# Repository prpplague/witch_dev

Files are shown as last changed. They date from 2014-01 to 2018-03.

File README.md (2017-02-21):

WITCH Development
=========

Repository for misc documents and code relating to the study of the Harwell
WITCH. The Harwell computer, later known as the Wolverhampton Instrument for
Teaching Computing from Harwell (WITCH), or the Harwell Dekatron Computer,
was an early British relay-based computer. It is currently being restored at
The National Museum of Computing at Bletchley Park, where it is described as
"the oldest original functioning electronic stored program computer in the 
world".

http://www.witch-e.org

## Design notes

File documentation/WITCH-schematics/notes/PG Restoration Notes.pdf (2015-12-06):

Pulse Generator Restoration Notes

January – March 2012, updated August 2012

Delwyn Holroyd

Test setup

The pulse generator was powered up on the bench using the WITCH rectifier and stabilizer for all tests. Three switches were provided :-

- Stop switch on A4 (+20 / -10V)
- RCB on / off on A2 (Returned Carry B pulses from A10 / ground)
- Start switch on A3 (-200V / open)

Oscillator

On initial power-up the oscillator worked and pulse widths were observed to be approximately correct. Nominal widths for A and B pulses are 1.5ms.

Over the course of the next few weeks as work progressed, B pulse width became highly unstable and narrower. This fault was traced to C19 (two caps – the larger flat mica to blame). These were replaced with new modern 2200 + 150pF caps on 17th March.

An unusual feature was observed on the +B outputs from V8 – on the anode positive going and on screen negative going narrow pulses coincident with V9 (+A pulse) rising edge. It is unclear exactly how this arises, but is clearly associated with the current which must flow through C19 into the grid of V8, although there is no evidence of a voltage spike on V8 grid. The -ve pulse on the screen output is effectively removed by the following stage (V13) so has no effect on circuit operation.

The anode of V8 goes to A13 and onto Units GA and GB, but is not shown on the schematics of the latter. Investigation of how this signal is used GA and GB will be needed to determine whether the +ve pulse is a problem. Exchanging V8 didn't alter the waveform.

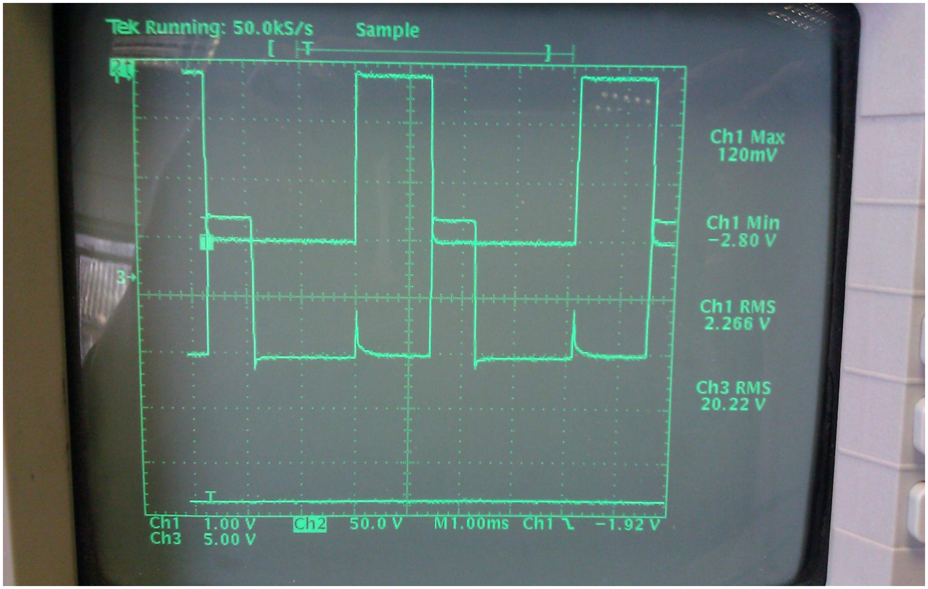
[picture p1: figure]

The picture above shows +A and +B pulses before C19 replacement.

The function of the 10n capacitor on V10 anode (-A pulses) was not immediately obvious. It's effect is to heavily round-off the rising pulse edge into V11 and V12. After clamping in the latter stages the rising edge is delayed and noticeably slower (100us). The functional effect is to delay the -A rising edge so that -A and -B pulses overlap slightly, important to ensure the Dekatrons step correctly.

On 17th March V10 failed, causing pulse widths and period to contract. The 6AM5 was replaced with an equivalent NOS EL91.

The photo below shows +A, -B, -A pulses after replacement of C19 and V10.

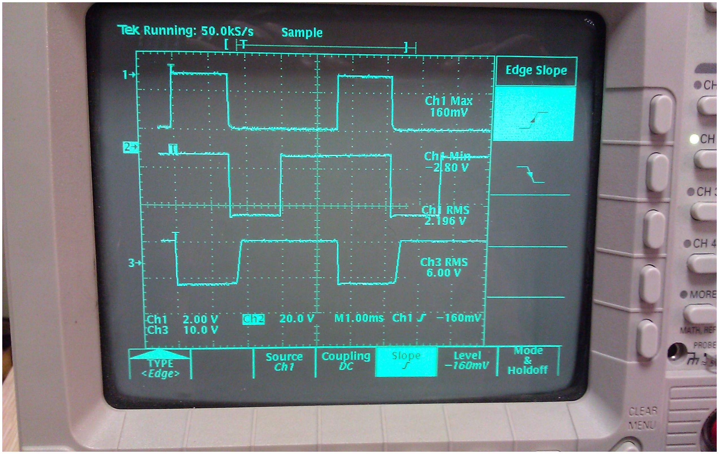
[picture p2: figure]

Control Circuit

On initial power-up, the two G1/371K trigger tubes V5, V6 did not work (no priming gap glow). The GTE175M tester was modified to accept G1/371K in an additional socket and the entire stock tested. We had only 7 working and the machine requires six in total (four in the pulse generator and two in Unit GA). The working parts have quite widely varying characteristics – both maintaining voltages and trigger threshold. Two tubes with reasonably well matched Vm were chosen for V5 and V6.

The adjustment of the circuit with RV1-3 is tricky since RV1 also affects the B pulse switching circuit, and V20 in Unit GA as well as the amplitude of the waveform appearing at V5 trigger (coincident with the trailing rising edge of the first RCB pulse). The contemporary “Computer Routine Maintenance” document from Wolverhampton notes that RV2 can be adjusted for two or three returned carry pulses, but it was found to be possible to adjust for one pulse. It isn't clear why more than one would be necessary.

A fault was discovered in this circuit which became more apparent over the period of fault-finding. This was traced to rectifier W2 (actually two germanium in series, probably a Wolverhampton replacement). This was replaced on 17th March with a modern 1N4007 silicon diode. This restored the correct timing of the trigger signal to V5 and eliminated spurious narrow pulses from the B pulse switching outputs.

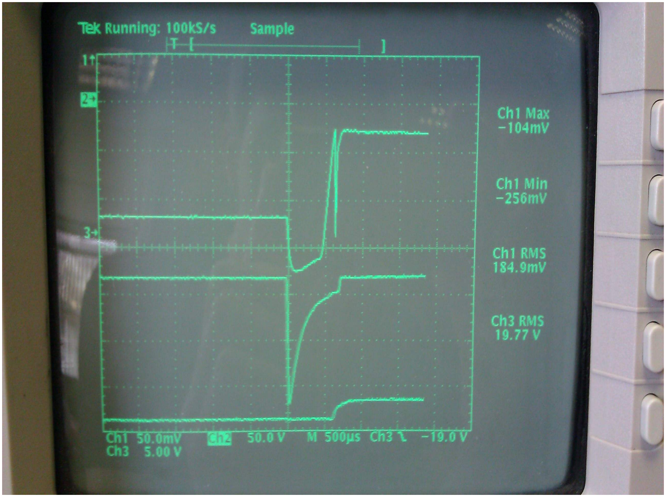
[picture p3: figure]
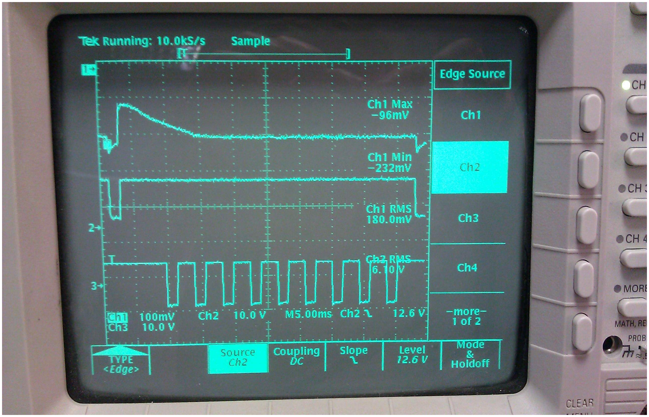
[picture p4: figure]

The left picture above shows the V5 trigger, V4 grid and V5 cathode before the repair, the right hand picture shows V5 trigger, RCB and 9B after replacement of W2.

Round-off Circuit

This was tested briefly, but due to the extreme shortage of working trigger tubes and the non essential nature of this circuit it has been left with V22-23 unpopulated.

A Pulse Switching Circuit

No problems were found in this circuit (V11-12) and all the clamping diodes are working.

B Pulse Switching Circuit

As noted above RV1 must be adjusted correctly to ensure waveform z (from trailing edge of RCB pulses) is not too large relative to waveform y (from trailing edge of first normal B pulse). The picture below shows correct adjustment – RCB, z, y.

B Pulse Output Stages

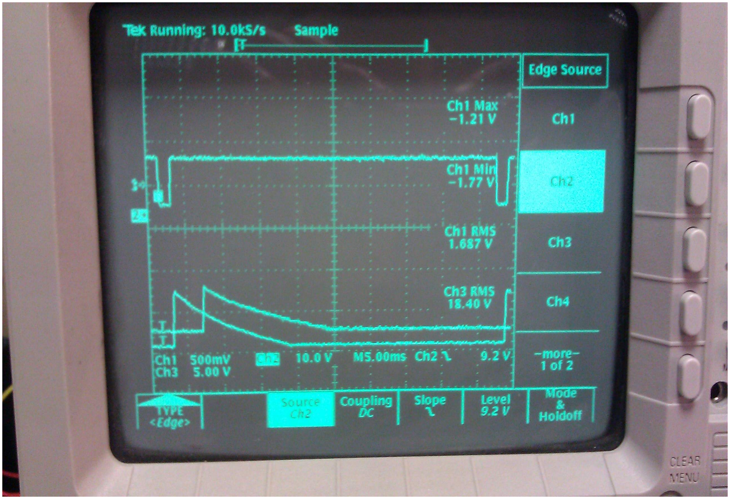
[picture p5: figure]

No problems were found in this circuit (V17-19, V25). However during early integration testing of the machine it was noted that send B pulses from V19 (SK21) only fall to around -50V, with RV6 at the limit of adjustment. To correct this problem the bias on RV6 was rewired from -200V to -180V, which now gives plenty of adjustment margin.

Trigger Valve Anode Waveform Circuit

These circuits produced the correct waveforms but with narrow spikes coincident with the rising edge of B pulses. These were traced to V20, the output of which drives SK3 and is mixed into SK2. Initially rectifier W29 was suspected, but temporary substitution with a silicon diode didn't alter the symptom. The picture below shows SK2, and V20 grids.

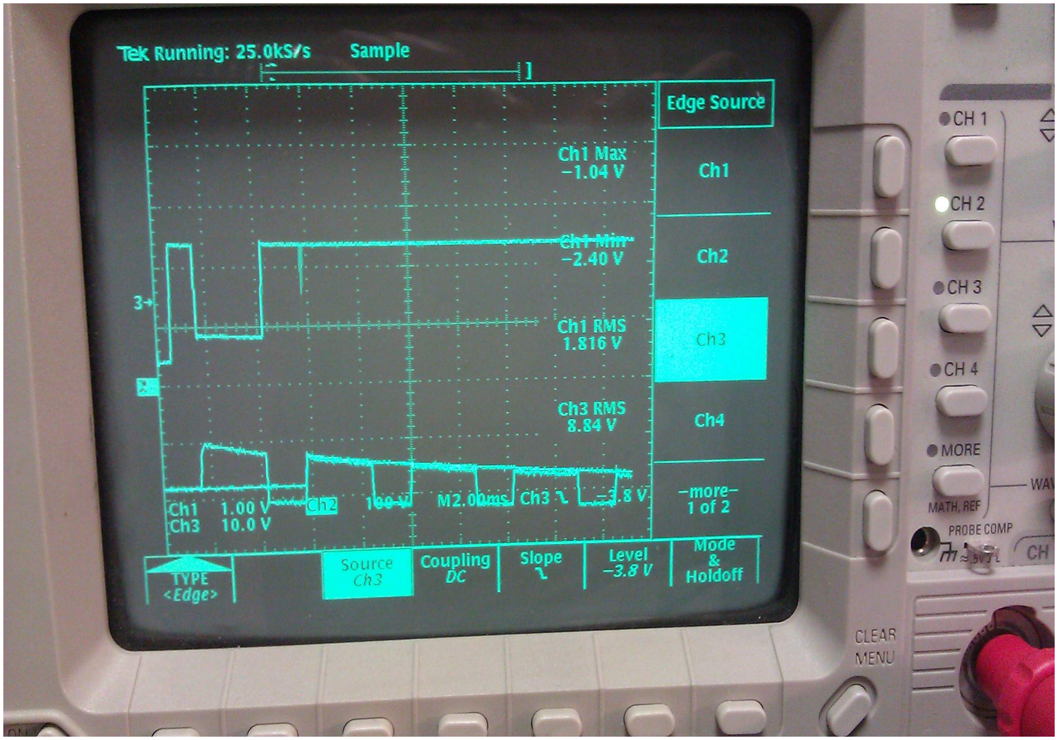
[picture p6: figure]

The problem is hard to see in this picture but there is ringing on the rising edges of the B pulses mixed into waveform z which is compared with waveform y by V20. This problem was solved by adding a 330pF capacitor from the junction of W29/R60 to -180V, to slow down the rising edges. The picture below shows the waveforms on SK3 and V20 grids after the capacitor was added.

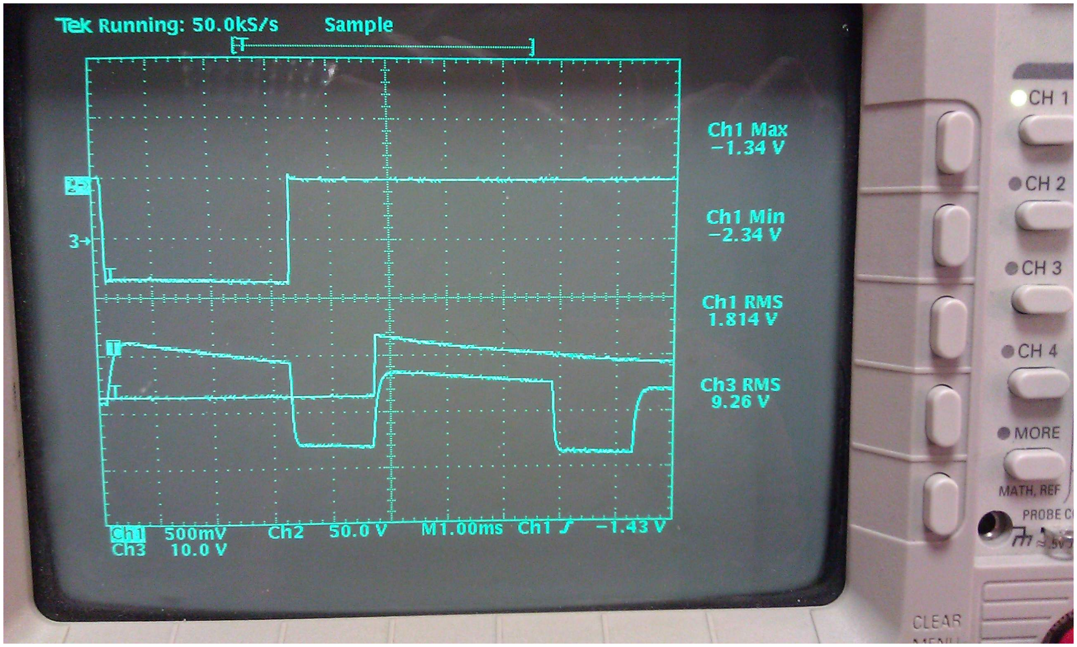
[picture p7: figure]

Circuit Modifications

Capacitor on W29 | Replacement C19

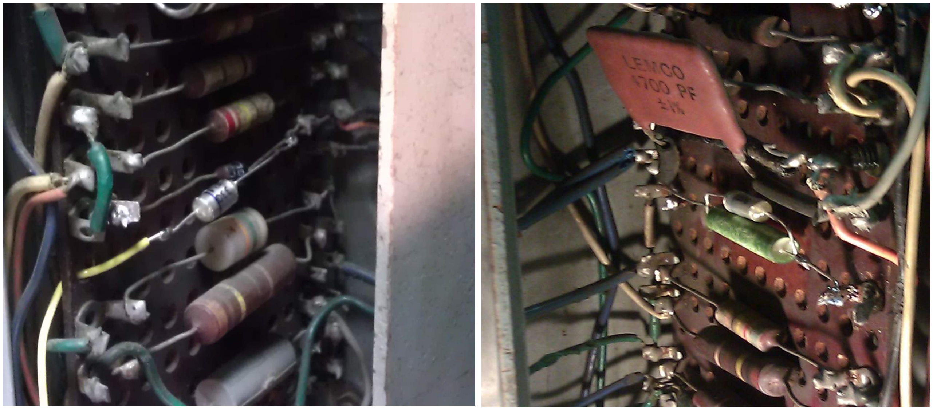
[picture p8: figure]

Replacement W2

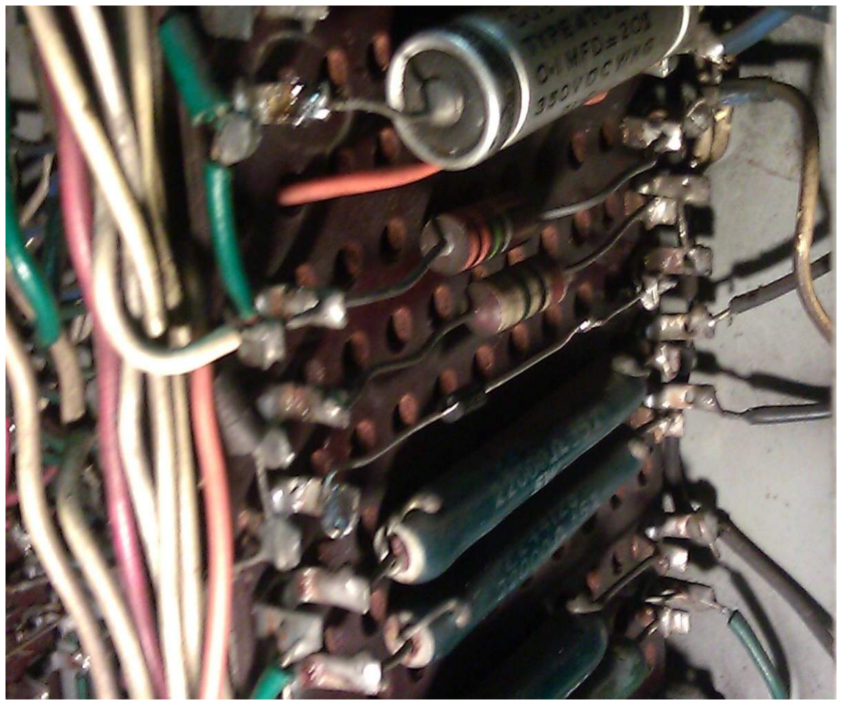
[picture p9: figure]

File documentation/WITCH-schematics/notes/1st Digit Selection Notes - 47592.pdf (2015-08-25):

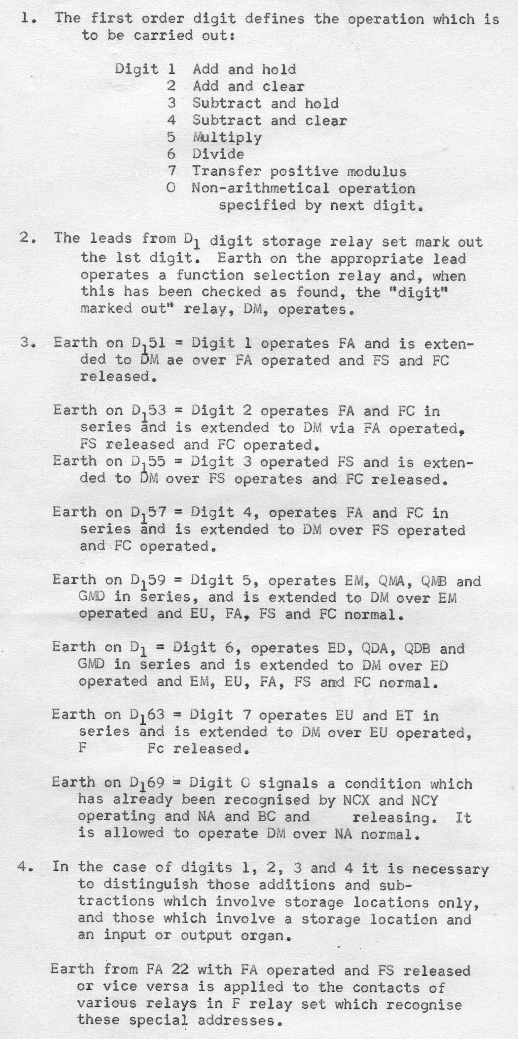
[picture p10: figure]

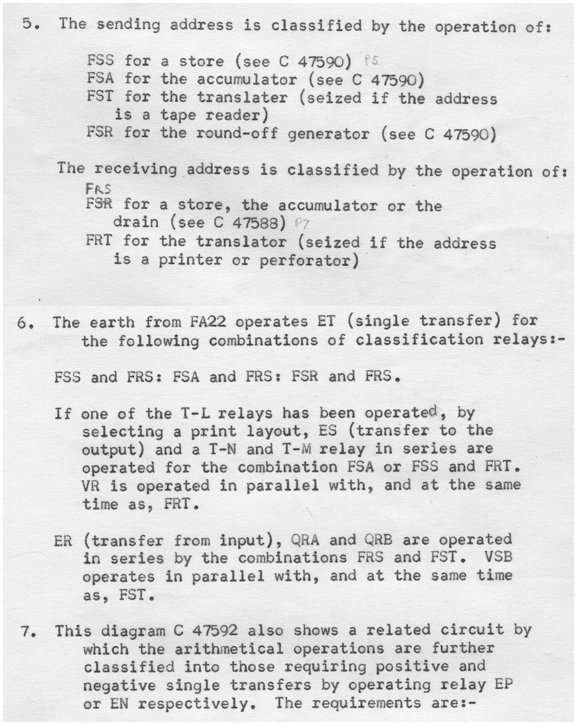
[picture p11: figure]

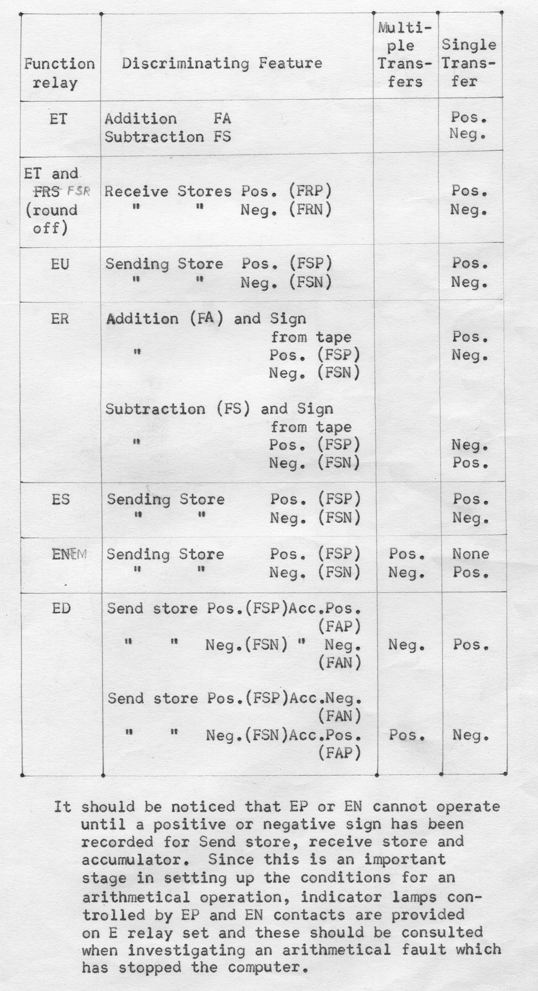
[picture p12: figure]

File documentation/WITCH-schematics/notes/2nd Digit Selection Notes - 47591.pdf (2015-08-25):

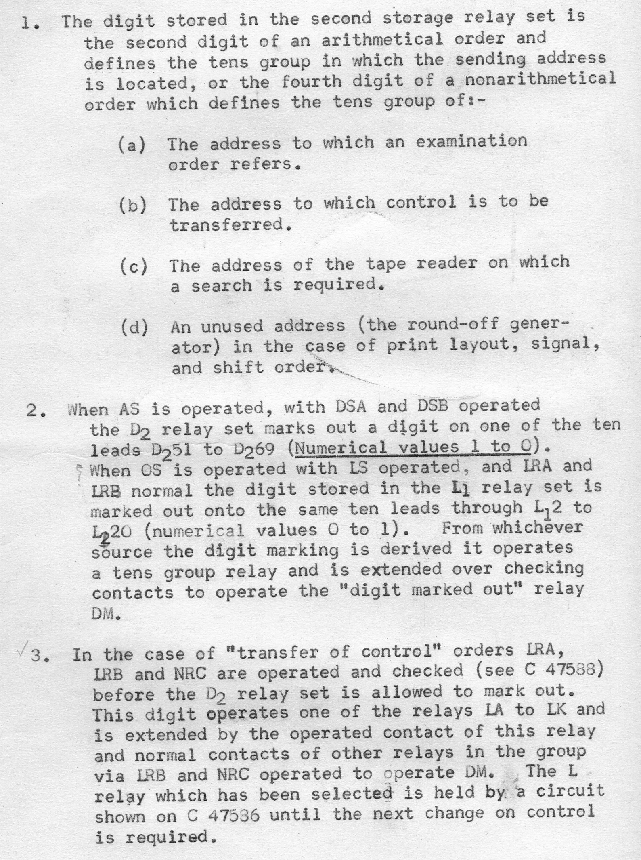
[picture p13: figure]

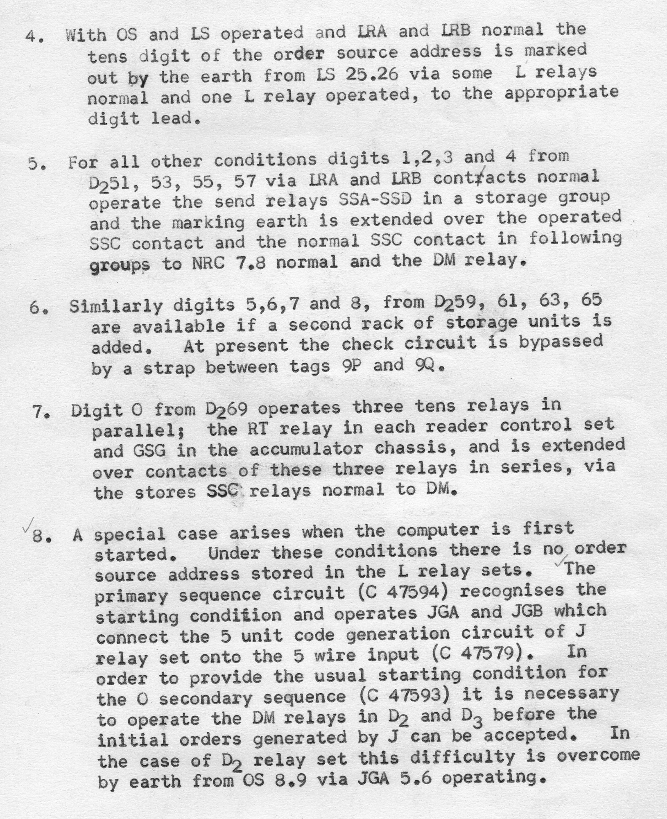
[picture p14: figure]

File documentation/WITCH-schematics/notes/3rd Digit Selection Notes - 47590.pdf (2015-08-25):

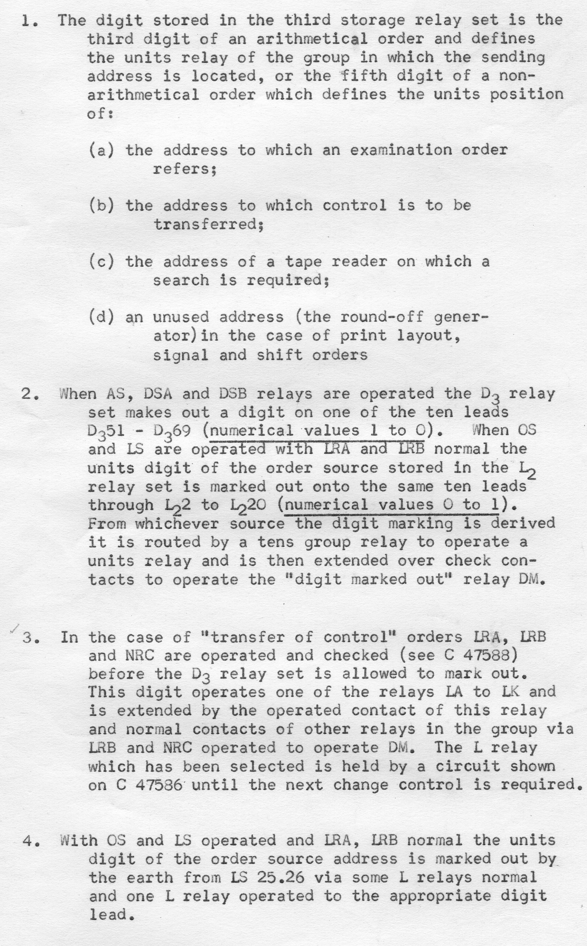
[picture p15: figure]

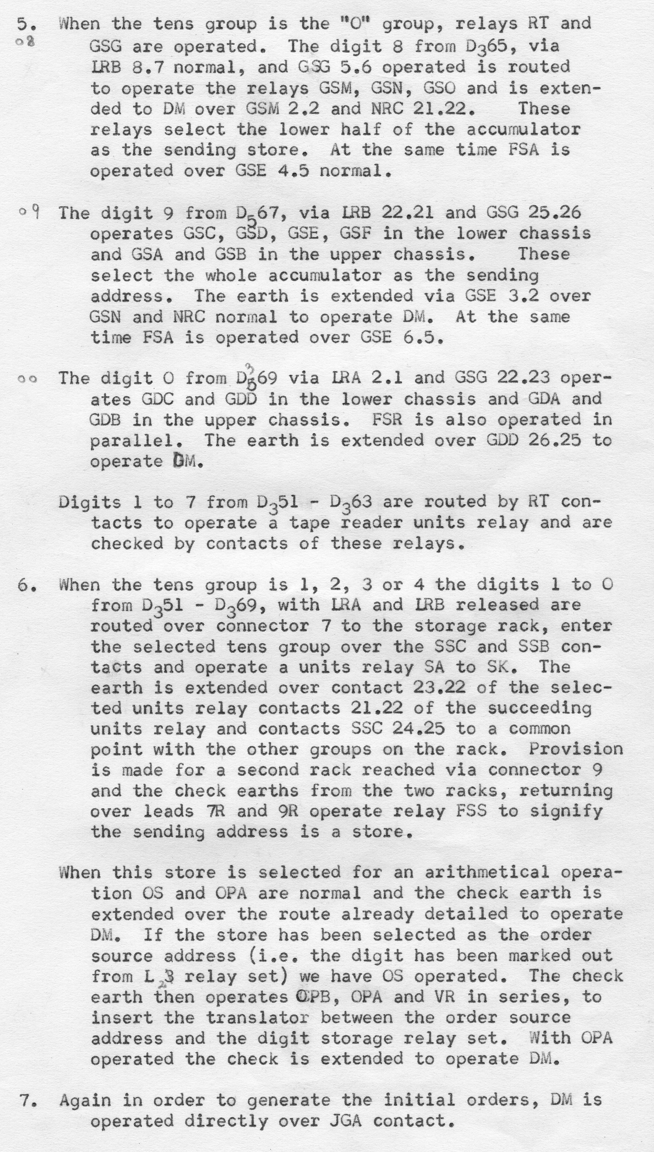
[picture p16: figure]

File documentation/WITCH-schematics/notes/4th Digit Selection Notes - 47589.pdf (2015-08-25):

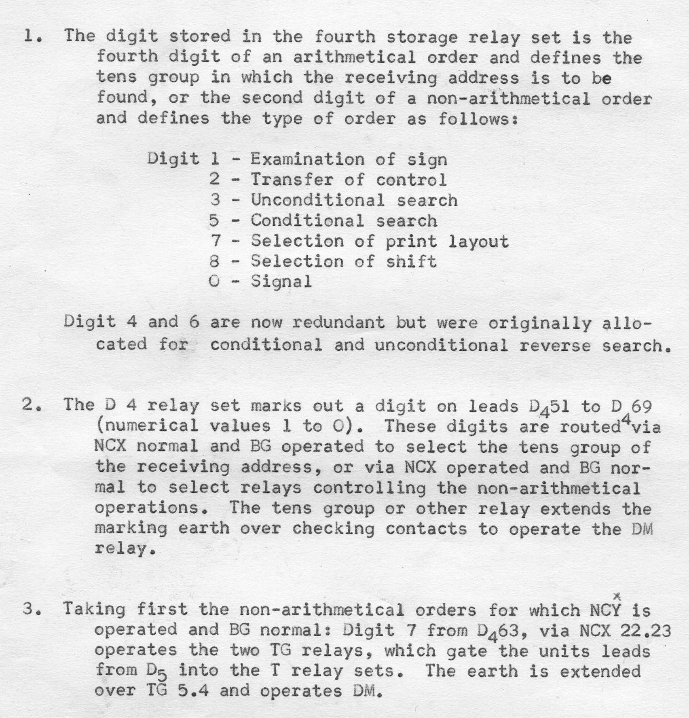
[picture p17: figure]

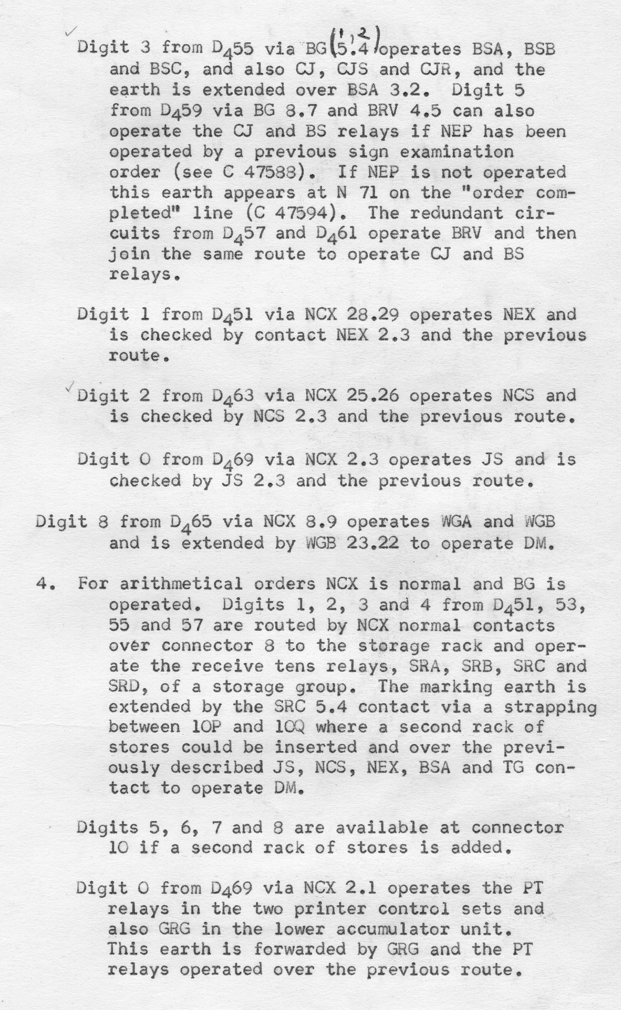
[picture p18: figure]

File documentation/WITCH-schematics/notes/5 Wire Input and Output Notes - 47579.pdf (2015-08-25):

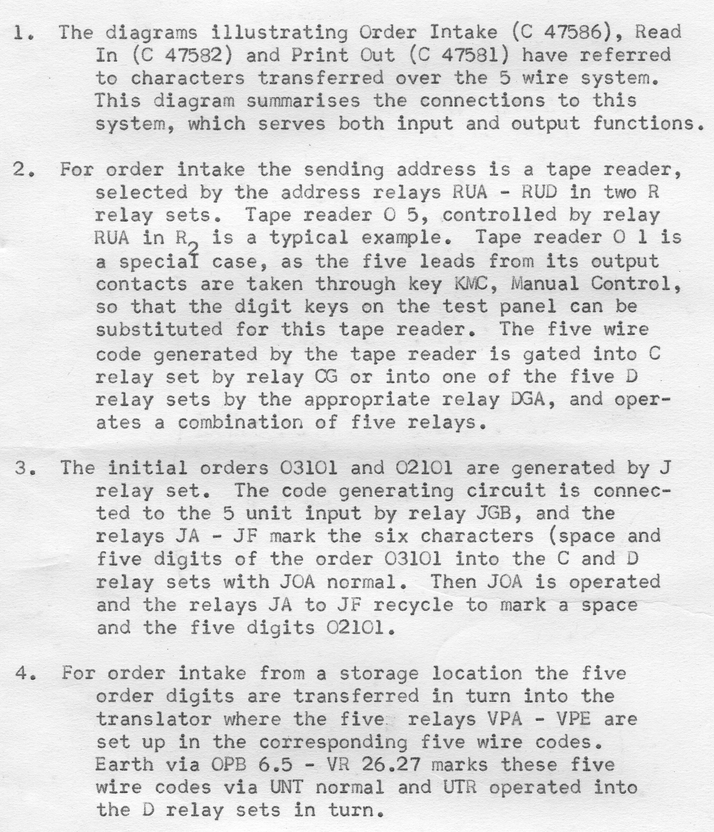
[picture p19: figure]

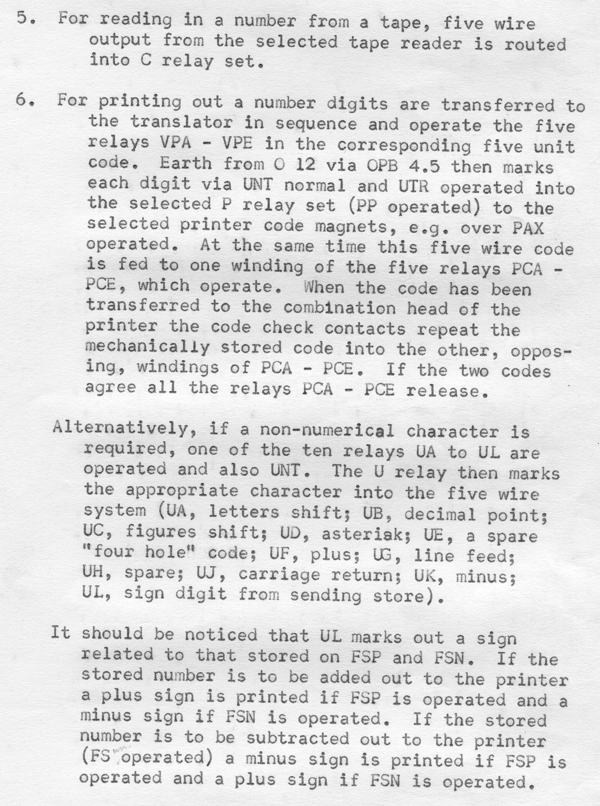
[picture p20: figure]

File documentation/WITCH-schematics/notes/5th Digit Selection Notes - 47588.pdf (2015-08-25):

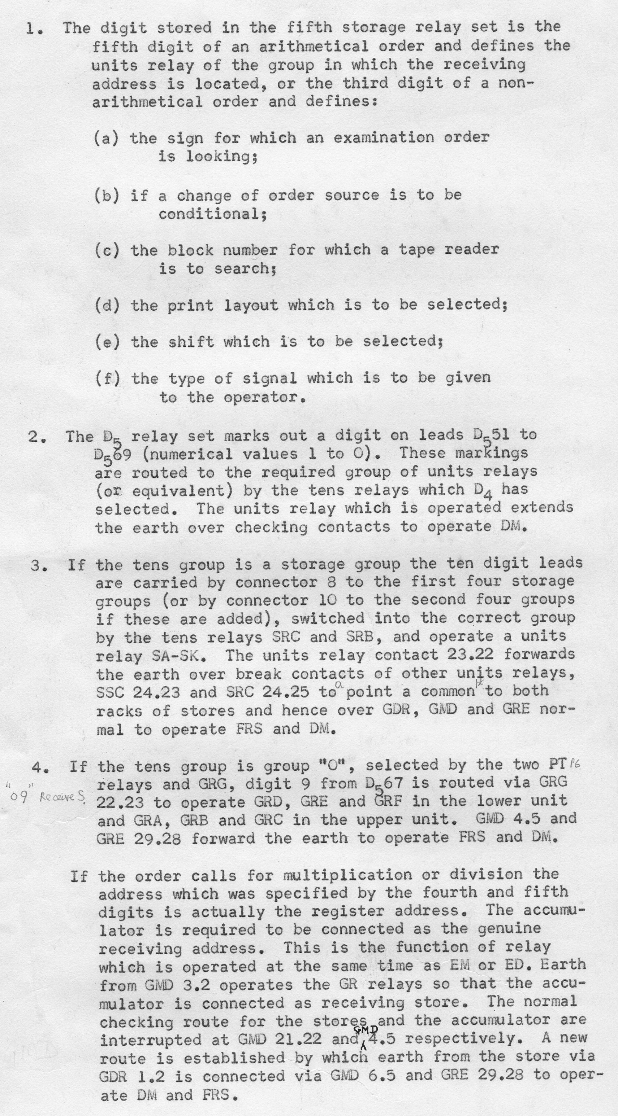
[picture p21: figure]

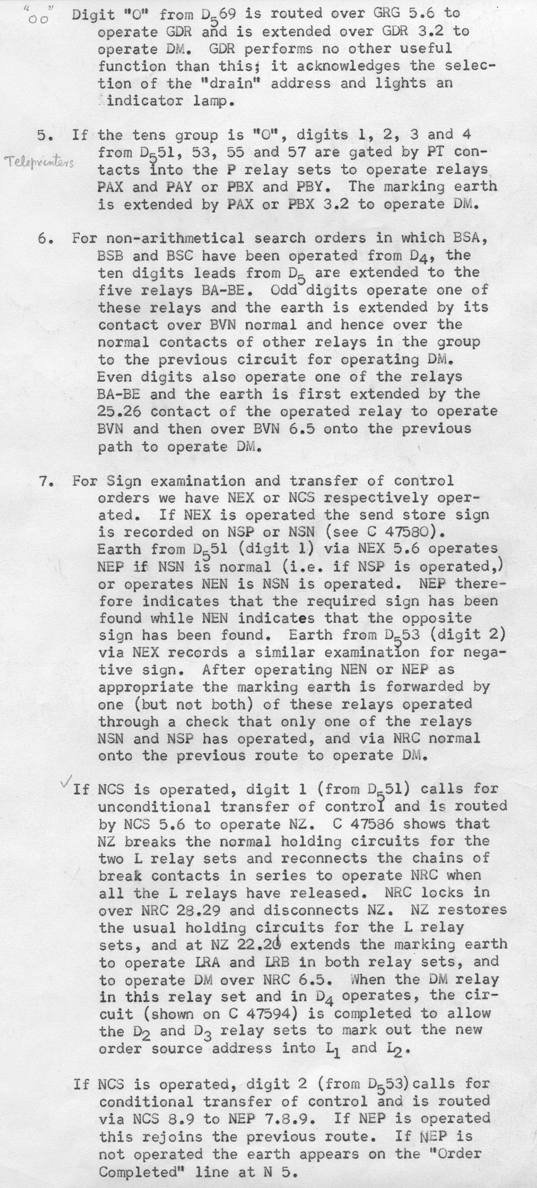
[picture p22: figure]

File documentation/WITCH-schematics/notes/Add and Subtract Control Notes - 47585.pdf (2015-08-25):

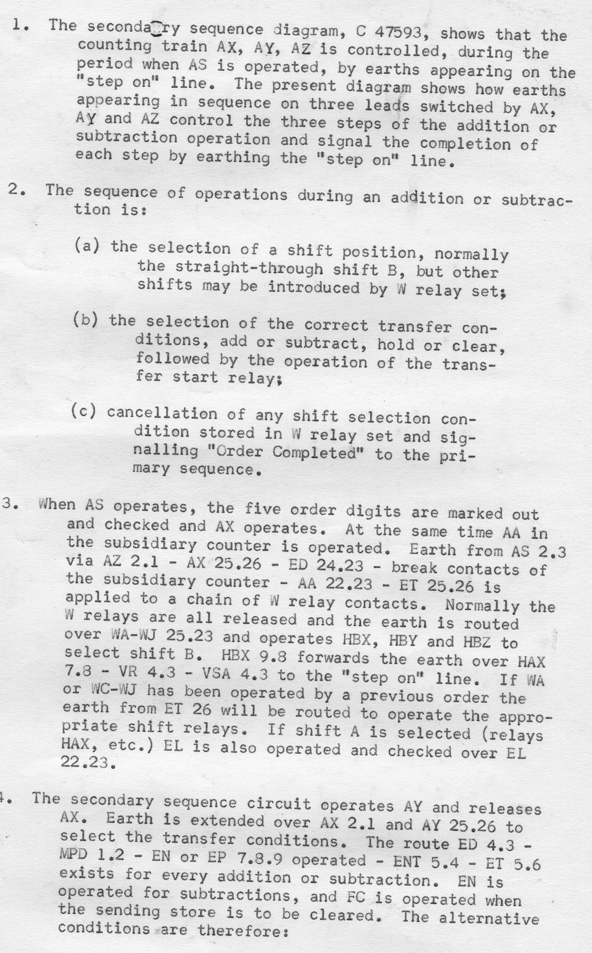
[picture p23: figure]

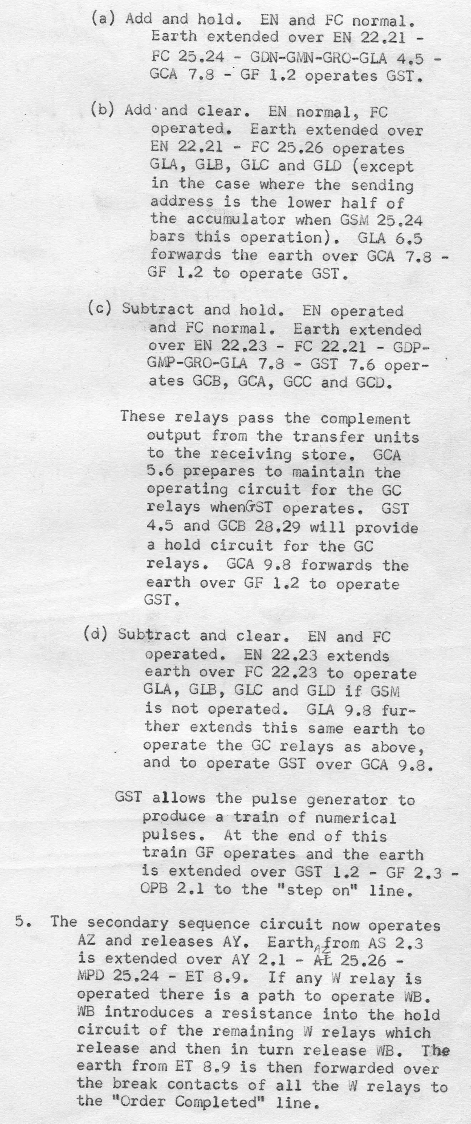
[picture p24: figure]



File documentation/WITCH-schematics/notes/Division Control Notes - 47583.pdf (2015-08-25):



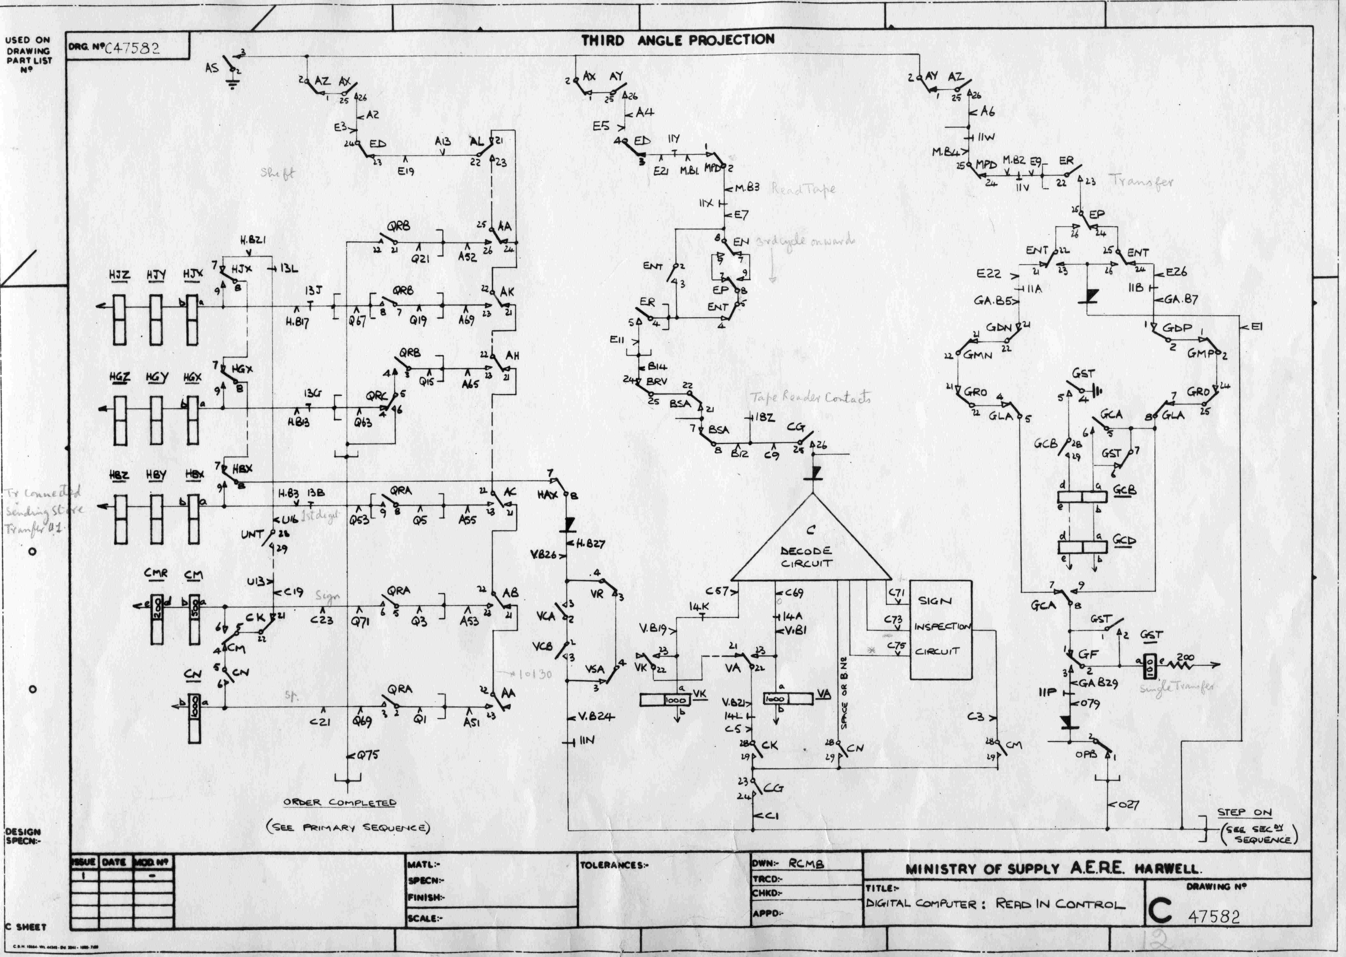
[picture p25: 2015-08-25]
documentation/WITCH-schematics/jpgs/Read In Control - 47582.jpg

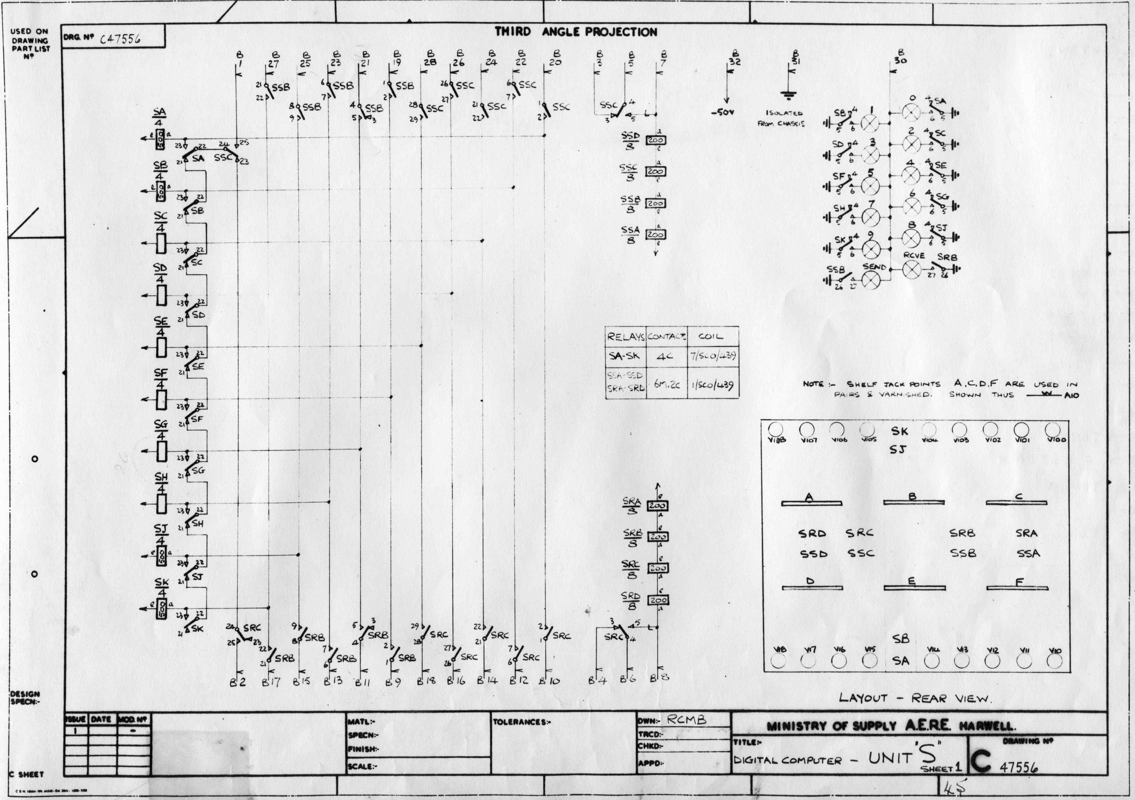
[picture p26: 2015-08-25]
documentation/WITCH-schematics/jpgs/Unit S Sheet 1 - 47556.jpg

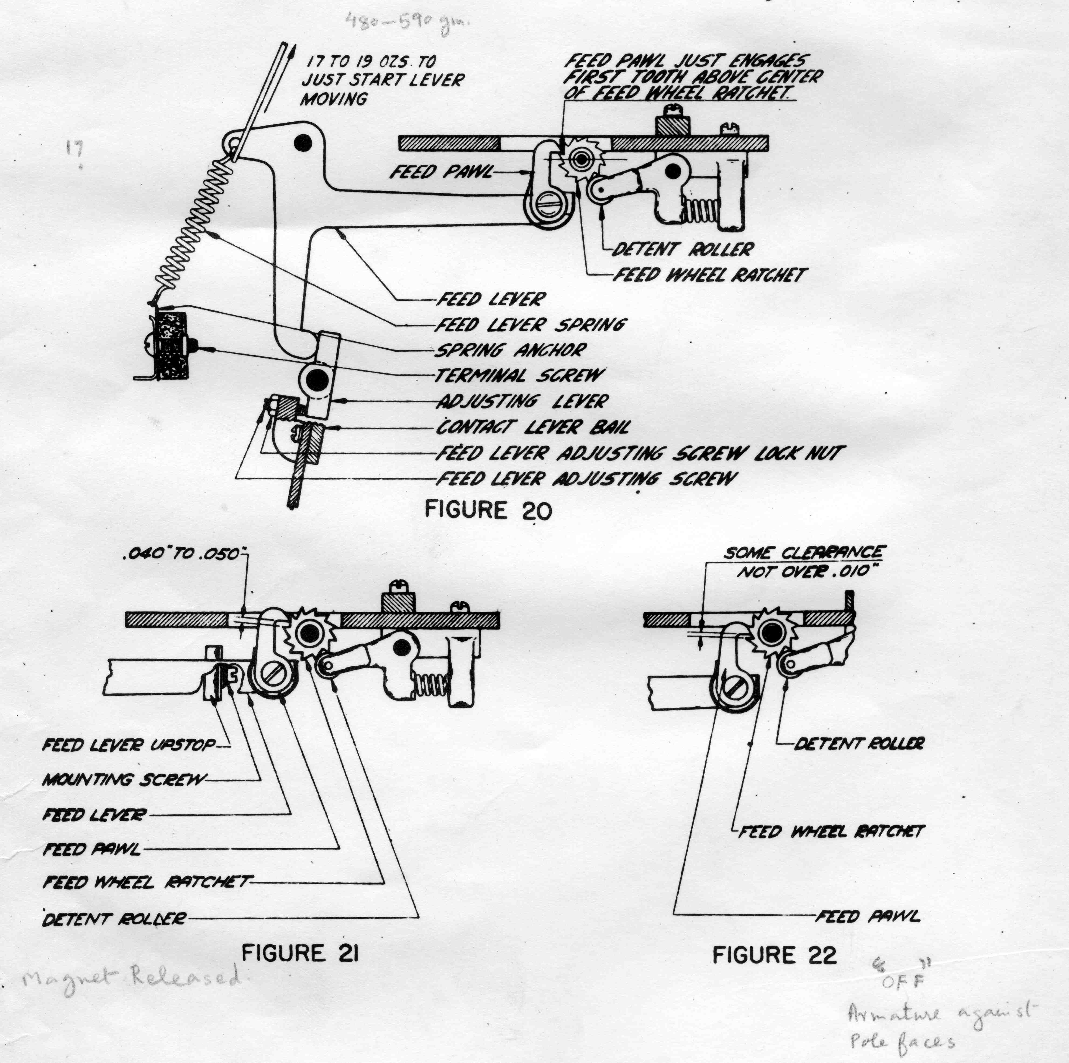
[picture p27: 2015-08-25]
documentation/WITCH-schematics/jpgs/Figure 20.jpg

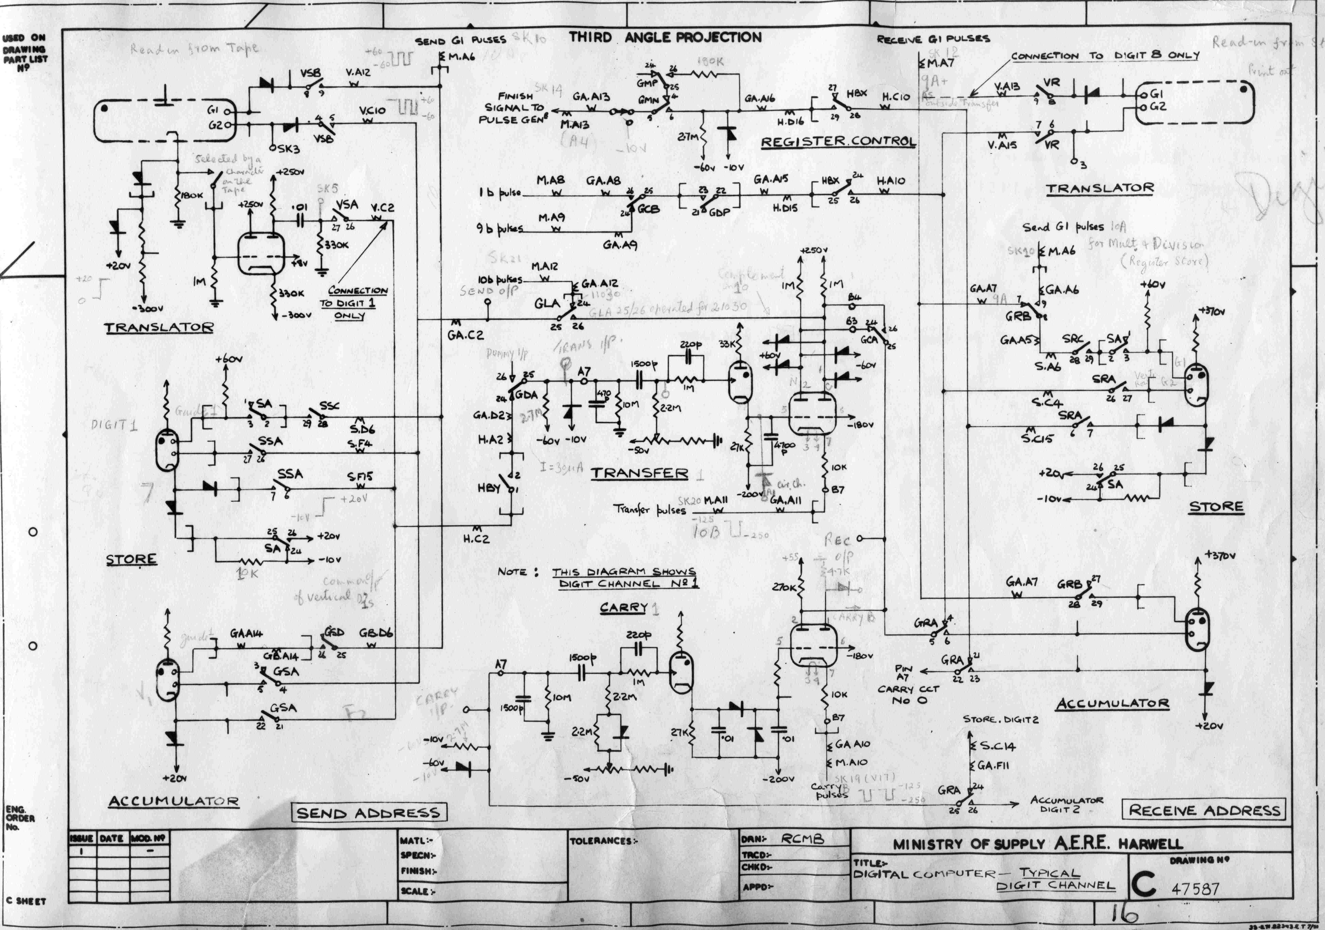
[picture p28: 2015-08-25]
documentation/WITCH-schematics/jpgs/Typical Digit Channel - 47587.jpg

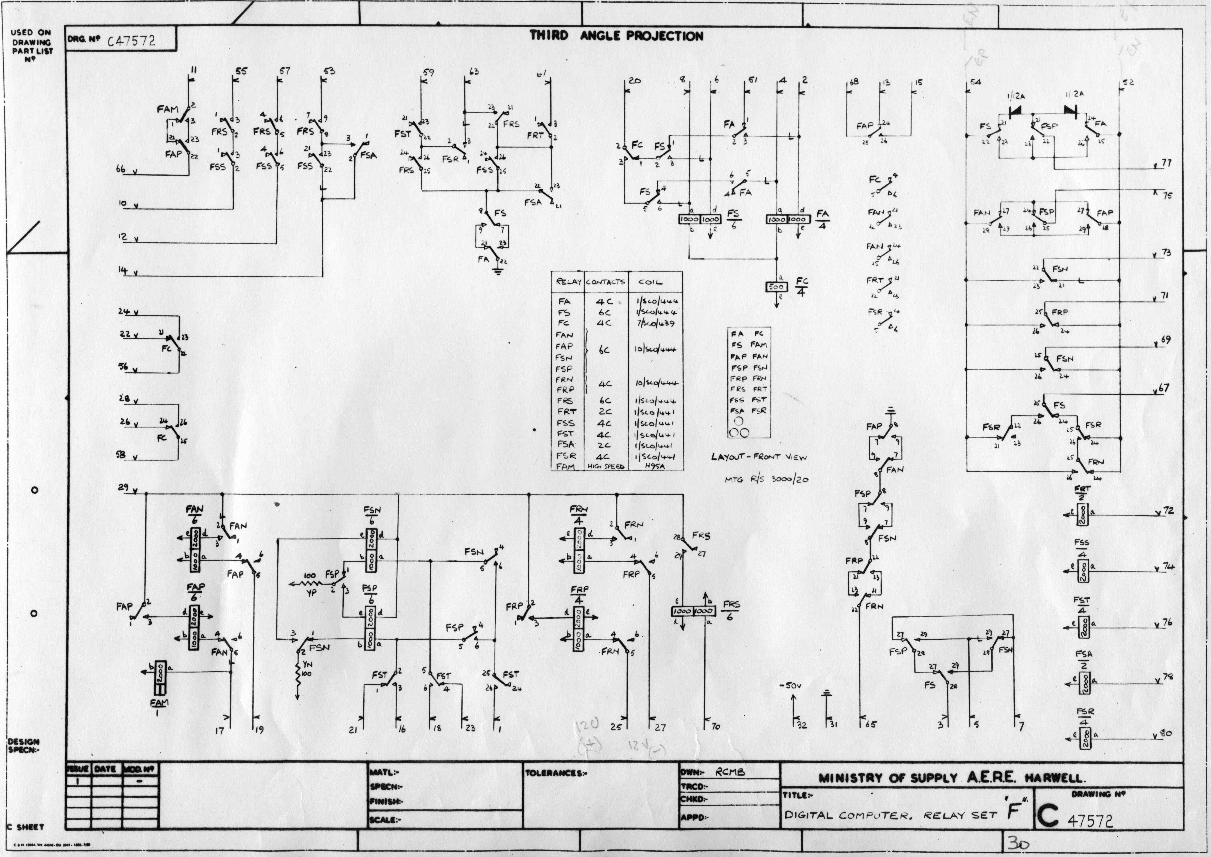
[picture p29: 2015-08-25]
documentation/WITCH-schematics/jpgs/Relay Set F - 47572.jpg

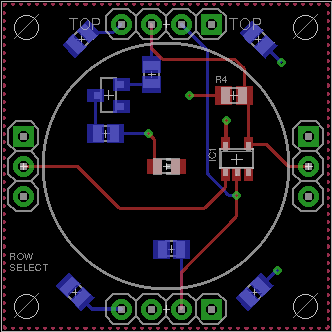
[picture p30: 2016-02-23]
block-designs/witch-phase2/store-row-block/store-row-block.png

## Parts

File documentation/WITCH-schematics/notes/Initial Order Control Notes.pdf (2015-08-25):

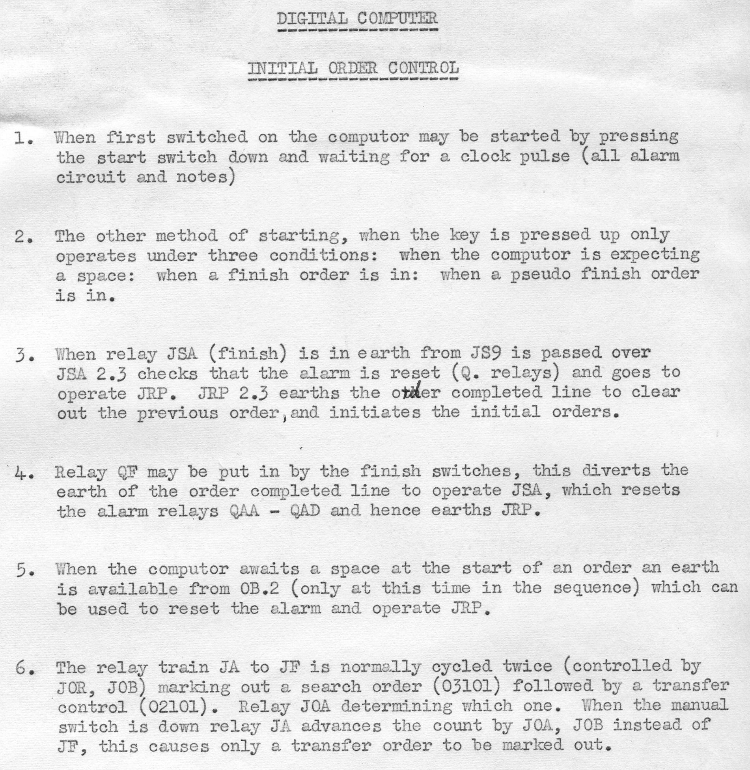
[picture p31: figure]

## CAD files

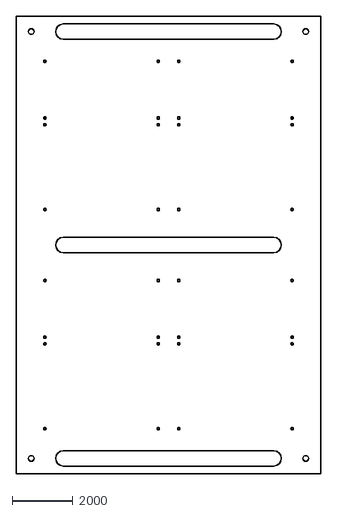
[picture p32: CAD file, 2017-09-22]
block-designs/witch-phase2/cad/snd-rcv-select.dxf
10000.0 x 15000.0

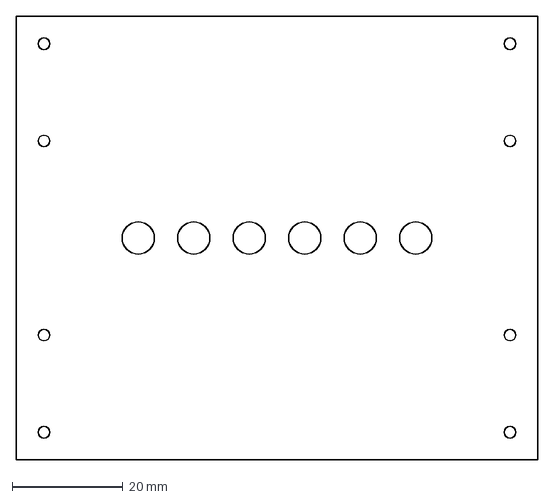
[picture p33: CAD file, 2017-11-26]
block-designs/witch-phase4/tape-reader/cad/80mm/tape-reader-top.dxf
94.0 x 80.0 mm

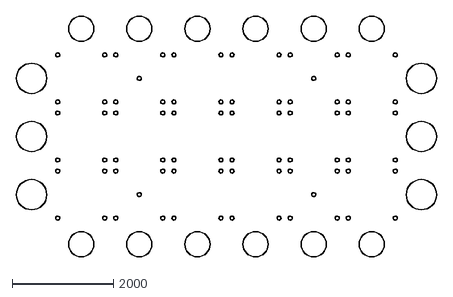
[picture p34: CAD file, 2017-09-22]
block-designs/witch-phase2/cad/transfer-acc-mounting.dxf
8315.0 x 4765.0

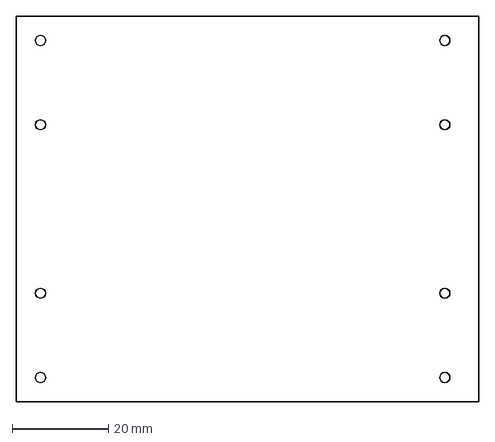
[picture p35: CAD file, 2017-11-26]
block-designs/witch-phase4/tape-reader/cad/80mm/tape-reader-mid.dxf
96.0 x 80.0 mm

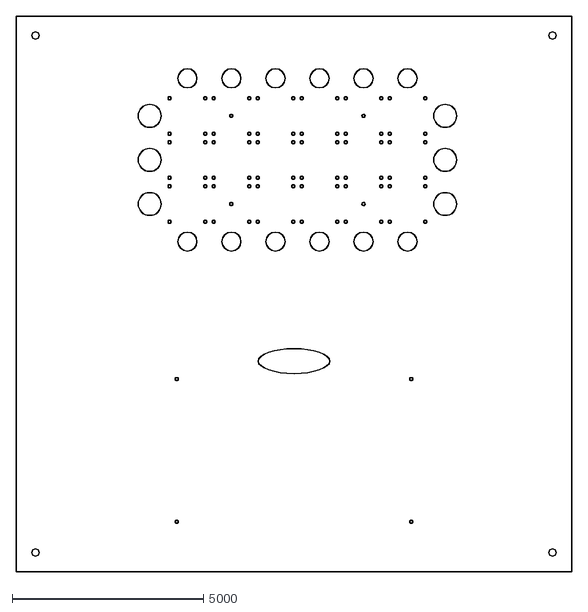
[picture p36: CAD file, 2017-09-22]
block-designs/witch-phase2/cad/transfer-and-pulse.dxf
14500.0 x 14500.0

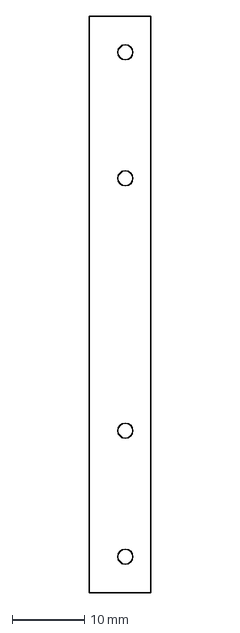
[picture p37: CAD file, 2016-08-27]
block-designs/witch-phase4/tape-reader/cad/58mm/tape-reader-guide.dxf
8.50 x 80.0 mm

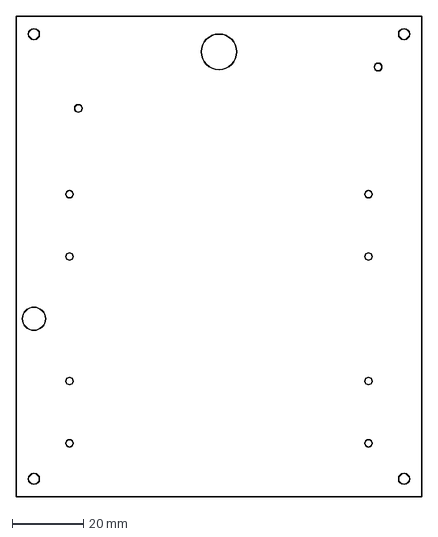
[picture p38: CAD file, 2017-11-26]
block-designs/witch-phase4/tape-reader/cad/80mm/tape-reader-bot.dxf
114.0 x 135.0 mm

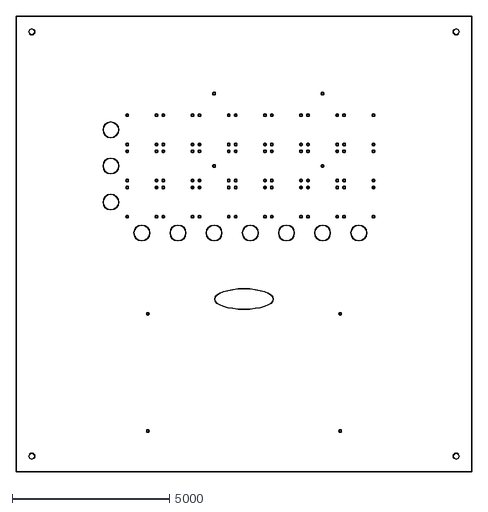
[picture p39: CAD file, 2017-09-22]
block-designs/witch-phase2/cad/single-store-single-row.dxf
14500.0 x 14500.0

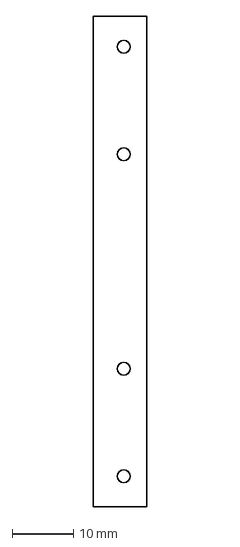
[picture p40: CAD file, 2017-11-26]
block-designs/witch-phase4/tape-reader/cad/80mm/tape-reader-spc.dxf
8.80 x 80.0 mm

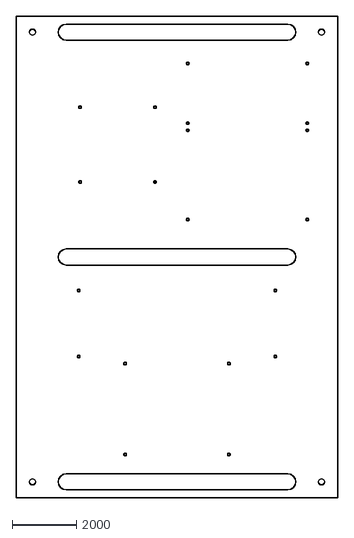
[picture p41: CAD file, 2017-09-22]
block-designs/witch-phase2/cad/keypad-n-sequence.dxf
10000.0 x 15000.0

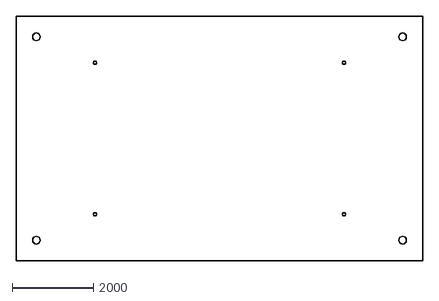
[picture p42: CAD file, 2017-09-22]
block-designs/witch-phase2/cad/single-panel.dxf
10000.0 x 6000.0

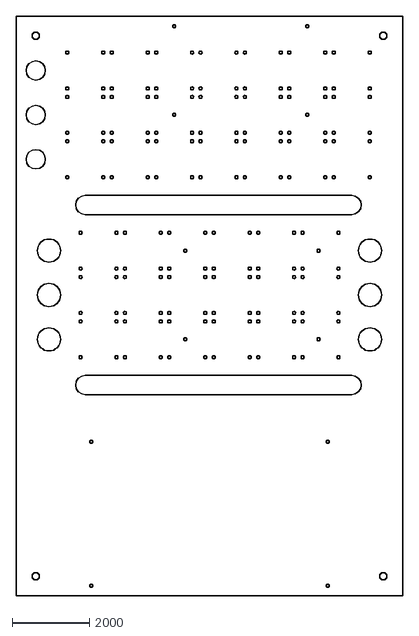
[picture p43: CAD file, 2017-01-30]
block-designs/witch-phase2/cad/new-set-a.dxf
10000.0 x 15000.0

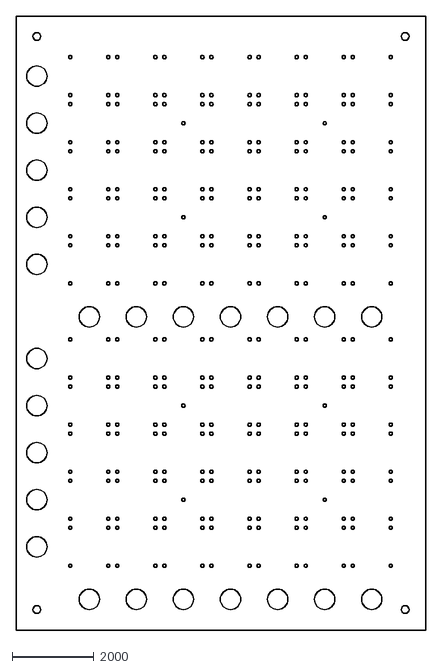
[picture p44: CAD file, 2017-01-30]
block-designs/witch-phase2/cad/mini-store.dxf
10000.0 x 15000.0

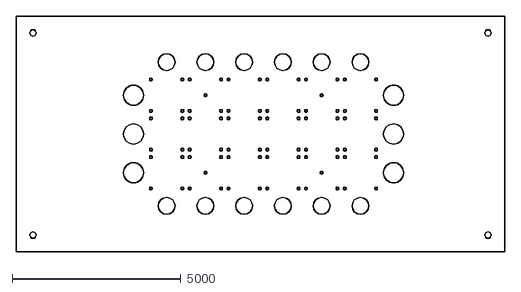
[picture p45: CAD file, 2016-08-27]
block-designs/witch-phase2/cad/transfer-acc.dxf
14500.0 x 7000.0

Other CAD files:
block-designs/witch-phase2/cad/relay-set-d.dxf
block-designs/witch-phase4/tape-reader/cad/58mm/tape-reader-top.dxf
block-designs/witch-phase4/tape-reader/cad/58mm/tape-reader-bot.dxf
block-designs/witch-phase4/tape-reader/cad/58mm/tape-reader-mid.dxf

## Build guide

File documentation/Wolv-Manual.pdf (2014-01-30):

ELECTRONIC DIGITAL COMPUTER

Notes on Programming and Operating (2nd edition)

### 1. THE ORDER CODE

1. The Code
2. Numerical input
3. Initial orders
4. Addresses
5. Addition and Subtraction, including Input, Output orders
6. Multiplication
7. Division
8. Sign Examination
9. Transfer of control
10. Search orders
11. Printing layouts
12. Shift selection
13. Signal Orders
14. Round-off

### 11. OPERATING THE COMPUTER

1. The operating controls
2. Operating instructions
3. Preparation of tapes
4. Perforating the paper original
5. Printing and perforating copies
6. Reading the perforated tape
111. PERFORMING THE PROGRAMME
1. Subdividing a programme on one tape
2. Subdividing a programme on more than one tape
3. Use of stored orders
4. Some arithmetical difficulties
5. Completing the loop
6. Testing for zero
7. Controlling the repetition of a sub-routine
8. Testing for the end of a numerical input tape
9. Reading into the drain
10. Alternative orders for correct round-off
11. Other examples of alternative orders
12. Refinements in printing layouts
13. Adding block numbers to the perforated output
14. Clearing stores
15. Estimating the running-time of a programme

1. The Code.

Orders are perforated on the tape as a block marking character or space code followed by five decimal digits. These five digits form the order code shown in Table A. It is a two-address code and for orders controlling arithmetical operations the first digit specifies the operation (addition, subtraction, multiplication or division) and the remaining four digits are two addresses defining the location of the two quantities which are to be operated upon. Further details of the arithmetical orders are given in paragraph 3, 4, 5, 6 and 7 below.

A second class of order, in which the first digit is 0, do not require arithmetical operations but result in various operations in the controlling part of the Computer. These orders are described in paragraphs 8 - 13 below.

2. Numerical Input.

Numbers are perforated on the tape in one of two forms, either eight decimal digits preceded by a space (or block marking character) and a positive or negative sign; or five decimal digits preceded by a space (or block marking character) and an asterisk (equivalent to a positive sign). This latter form was originally intended for orders which are to be read into the internal storage of the Computer, but it is useful for positive numbers when only five digits are necessary.

Throughout the Computer the decimal point is fixed after the first digit. The numerical capacity, N, of every storage location in the Computer is therefore 10 > N > -10

A check is provided so that the computer cannot produce a number outside this range by normal arithmetical operations.

3. Initial Orders.

Two orders are stored permanently in the wiring of the computer and are used whenever the start key is operated or the computer restarts itself.

These orders are:

03101 i.e. Search for block No. 1 on tape reader 01.
02101 i.e. Transfer control to tape reader 01.

Hence the tape in reader 01 must begin with block No. 1 and the first order which is to be obeyed. The tape need not be loaded into the reader at block No.1.

4. Addresses.

Each storage group contains ten stores with addresses numbered, for example, 30, 31, 32 -- 38, 39. At present the computer is equipped with stores 10 to 99.

The addresses in the group 00 - 09 are allocated as follows:-

As sending Address | As Receiving Address
00 | Round-off Circuit | Drain
01 | Tape reader | Printer
02 | “ | Perforator
03 | “ | Printer
04 | “ | Perforator
05 | “ | Spare
06 | “ | “
07 | “ | “
08 | Last 7 digits of accumulator * | “
09 | All digits of accumulator →

* with the sign which stands before the first digit of the accumulator.

5. Addition and Subtraction Including Input and Output Orders.

Addition and subtraction are specified by orders beginning with the digits 1, 2, 3 and 4. Digits 1 and 3 control Addition and Subtractions, respectively, when the contents of the sending store are to be retained. These are usually called "Add and hold" and “Subtract and hold". Digits 2 and 4 control addition and subtraction when the contents of the sending store are to be cleared. These orders are called "Add and clear" and "Subtract and clear".

Input is a special case of the orders with first digit 1 or 3, in which the sending address is a tape read (01 - 07) and the receiving address is a store or the accumulator. If the receiving address has not been cleared previously a sum or difference will be formed in it.

Output is another special case of the orders with first digit 1 or 3 in which the sending address is a store or either half of the accumulator (09 or 08) ad' the receiving address is a printer or reperforator (01 - 04). It is not possible to print out and clear the sending store. The layout of the printed message is determined by a layout order described in Para. 11.

Another special case of addition and subtraction is the order with first digit 7, which allows the transfer of the positive modulus. This examines the sign of the sending address, which must be a store or the accumulator. If it is positive it behaves as an "add and hold" order, or if it is negative it behaves as a "subtract and hold" order. There are no orders allowing the transfer of negative modulus or the transfer of modulus with clearance of the sending store.

The orders 209 -- and 409 -- clear the whole of the accumulator.

The two addresses in these, or any other, arithmetical orders must not be in the same group of ten stores with the following exceptions in the group 00 - 09, which are permitted.

Sending address | Receiving Address | Task
00 | 09 | Rounding off the accumulator.
01 - 07 | 00 | Reading into the drain
01 - 07 | 09 | Reading into the accumulator
08 | 00 | Transferring last 7 digits of accumulator to drain
08 | 01 - 04 | Printing out last 7 digits of accumulator x 108
09 | 00 | Transfer from accumulator to drain
09 | 01 - 04 | Printing out first 8 digits of accumulator.

"Add and Clear" at "Subtract and Clear" orders are not permitted with these combinations of addresses.

6. Multiplication.

The multiplication order has the first digit 5. The two addresses must not be in the group 00 - 09. During multiplication the product is formed in the accumulator. If the accumulator has not been cleared the product is added to the previous contents. The multiplier is in the receiving address, and is cleared during multiplication.

Since the numerical storage of the computer, including the accumulator, has a capacity less than 10 a multiplication (+3) x (+3) is permissible but (+3) x (+4) will overfill the accumulator unless this already holds a negative number. (-3) x (-3) is also permissible. During multiplication with a negative multiplier the computer "overshoots" when dealing with each digit of the multiplier. This is very similar to the action of this computer or most mechanical calculators during division. For instance the multiplication (+ 3) x (-3) takes place as two operations:-

[ ( +3) x (-4) ] + [ (+3) x (+1) The first product temporarily overfills the accumulator and the computer is stopped. In effect the capacity of the accumulator is reduced during multiplication with a negative multiplier.

7. Division.

The division order has the first digit 6. The two addresses must not be in the group 00 - 09. The dividend must be placed in the accumulator. The quotient is built up in the receiving address but there is no carry-over between digits so that this address must be cleared previously. The remainder, if any, is left in the accumulator after division.

There is no guard against overfilling the quotient register, except that a division which attempts to produce a quotient of, say 1000 will take about 45 seconds and the normal inactivity alarm (see Section II) will operate.

The dividend must not be +0 (i.e. all 0's) but may be -0 (i.e. all 9's). A dividend of +0 stops the computer, but no detailed warning is given.

An exact division of a positive dividend, which should leave zero remainder, produces an error of -1 in the seventh decimal place of the quotient and leaves a remainder. Division of a negative dividend is always correct.

Division is appreciably slower than multiplication, leaves a remainder which has to be cleared out of the accumulator and the quotient is not easily rounded off correctly. Where it is possible multiplication by a reciprocal is usually superior to division.

8. Sign Examination.

The order beginning with the digits 01 causes the computer to compare the sign stored in a specified address with the required sign. A Yes-No answer is stored until superseded by the result of another sign examination. This information is used in conjunction with orders relating to conditional transfer of control and conditional search but it need not be used immediately.

9. Transfer of Control.

After the initial permanent orders, described in paragraph 3, orders are read from tape reader 01, until an order beginning with the digits 02 is reached. Transfer control orders beginning with 021 are always obeyed. Those beginning with 022 are only obeyed, if the sign examination memory has stored an affirmative, otherwise the computer proceeds to the next order. If there has been no previous sign examination the computer stops.

In an 02 order transfers control to a storage address orders are read from successive stores until a further 02 order is found in a store.

10. Search Orders.

These orders provide a means whereby control can be transferred to another point on the same loop of tape, or another loop of tape can be prepositioned in readiness for transfer of control to it or reading information from it. They cause the specified tape reader to search for a particular one of (up to) ten distinctive characters or block numbers.

Orders beginning with digits 03 always cause a search. Orders beginning with digits 05 only cause a search if the previous sign examination has stored an affirmative, otherwise the computer reads in the next order.

In either case a guard circuit gives an alarm if no space code is encountered in any half minute or if a space code persists for more than about half a minute. A search for a non-existent block number continues indefinitely.

11. Printing Layouts.

Each number can be perforated in two ways or printed in 8 ways the choice being determined by orders with first digits 07. No output can take place until a layout has been specified. The ten layouts are used as follows:-

| Layout No | Use
Perforating
| 1 | 8 digits.
| 2 | 5 digits with asterisk.
Printing
| 3 | 8 digits, 5 columns, first or intermediate column.
| 4 | 8 digits, last number on line.
| 5 | 8 digits, last number on line, followed by blank line.
| 6 | 6 digits, 6 columns, first or intermediate column.
| 7 | 6 digits, 5 columns, first or intermediate column.
| 8 | 6 digits, last number on line.
| 9 | 6 digits, last number on line, followed by blank line.
| 0 | feeds up five rows of blank paper.

The printer stores one character mechanically. When switched off it retains the last character fed to it and prints it whenever another character is fed in. The tabulations are chosen so that this stored character is normally "Figures Shift", but under special circumstances it may be any code.

Print layout 0 allows any such stored character to be printed well clear of the genuine output and provides blank paper for headings.

The use of the print layouts is illustrated in Appendix 1.

12. Shift Selection.

Additions and subtractions normally take place with the straight through shift position (Shift B). The orders beginning with digits 08 allow I the next addition, subtraction 'or transfer of modulus (i.e. 1, 3, or 7 orders) to be performed with a specified shift over the range from one place to the left to seven places to the right. The sending store cannot be cleared when this facility is in use. The 08 order affects only one transfer following it, and shift B is then effective again.

It does not affect any input, output, multiply or divide orders which
may occur between the 08 order and the 1, 3 or 7 order to which it refers. The following table shows the multiplying factors which are introduced:-
Order | Shift-selected | Factor
08100 | A | 10
08300 | C | 10 -1
08400 | D | 10 -2
08500 | E | 10 -3
08600 | F | 10 -4
08700 | G | 10 -5
08800 | H | 10 -6
08900 | J | 10 -7

The order 08200 is permissible, but it only selects the usual straight-through shift.

When using shift A the left hand digit is discarded. It is not added into the sign position. When using shifts C - J the right hand digits are discarded unless the receiving store is the accumulator.

13. Signal Orders.

These orders allow the computer to call for assistance. Two distinctive signals are provided :-

Order 00100 : "Finish". The computer can pass on to the next order if the “Pass Finish" key is operated permanently or temporarily. In passing this order the delayed alarm facility is reset.

Order 00200 : "Signal". The computer can pass onto the next order if the "Pass Signal” key is operated permanently or temporarily. The delayed alarm is not reset.

If either of these orders is encountered when the respective pass key is not operated the appropriate signal lamp lights and after a delay the inactivity alarm operates.

The computer ignores the order 00000 and passes on to the next order.

14. Round Off.

Section III para. 10, shows how a programme can be constructed to perform the usual rounding process by adding 5 into the right of the last digit which is being retained.

A less accurate method is available without elaborate programming. The sending address 00 is a device which produces randomly the digits 0 or 1 to be added (with the correct sign provided automatically) into the last digit which is to be retained. Unless preceded by an 08 order the round-off digit is added into the seventh decimal place.

II OPERATING THE COMPUTER.

### 1. The Operating Controls

The controls essential to the operator are :-

On the power rack

(a) The "on" press switch. This switches on all power supplies.
(b) The "off” press switch. This switches off all the computer except any equipment running off the monitor power sockets, which are controlled by a separate switch.
(c) "Automatic Shut Down" switch. All equipment except the monitors shuts down when the alarm circuit operates if this switch is down.

On the Control Unit

(d) "Start" key. Operate momentarily to start.
(e) "Pass Finish" key. See Section I paragraph 13.
(f) "Pass Signal" key.
(g) Alarm key with positions "No Alarm", "Normal Alarm" and "Delayed Alarm" • The no alarm position is used while testing or to clear an alarm condition. The use of the other positions is described in paragraph 2.
(h) "Busser Off" key. Disconnects the audible alarm.
2. Operating the Computer.
(a) Switch on Power Supplies by operating the "ON” push Switch on the power rack. After about one minute the Sealing tubes light and the computer is ready for use.
(b) Load the tape readers. If each tape has an order searching for the correct block number on any tape reader to which it is about to transfer control it is not necessary to load the tapes at any particular row. (See also paragraph I.3.) Check that the tapes are not reversed. The direction of motion is from the gate towards the raised end of the tape reader.

Tapes which lie on the floor or are otherwise in danger of becoming trapped or tangled should be passed over the support wire and under the tight tape lever of the tape reader.

(c) Operate the "Start" key (Green). This will be ineffective if the "No Alarm” key on the input table or the control rack is operated, and, until the internal clock mechanism generates an impulse.

(d) Set the required alarm conditions (Red key). The normal alarm gives a warning if the computer is inactive for 30-60 seconds. The delayed alarm returns the computer to the beginning of the programme when a period of inactivity is detected if the inactivity is not due to either Signal order. In general after three such attempts the normal alarm is given, but whenever a finish signal is passed the memory of my previous delayed alarms is lost and the full three lives are restored. The alarm key on the control rack should be set at "Normal Alarm".
(e) To Reset.
When experimenting with a new programme it is not unusual to wish to restart the computer at the beginning of the programme. This can be done in two ways:-

If the computer has stopped cancel the existing alarm, if any, and allow the delayed alarm to operate. If the computer is running,select the delayed alarm and lift the tight tape lever of the tape reader in use.

Alternatively the 50 volt D.C. switch on the power distribution unit may be switched off momentarily and the “Start" key operated again. This is preferable to switching the, whole equipment off.

(f) The Order Monitor Display.
When the computer stops owing to a programme error on a faulty tape it is useful to know what order is stored in the control section of the computer or the address from which an order is being read. Five keys on the Control racks switch in a lamp display showing this information.

When using the display it will be noticed that the two "addresses" of non-arithmetical, "0", order are interchanged e.g. an order which is perforated as 03104 appears on the display as 00431.

3. Preparation of Tapes.

The normal procedure is to make a paper original using the keyboard perforator. From this a printed slip is produced and checked against the manuscript programme. Any errors are marked up and if necessary a corrected paper copy is made. The paper original or copy may then be proved in the computer and any further corrections inserted. Where the final loops of tape are required to pass through the computer more than a few dozen times linen copies are made from the paper originals.

4. Perforating the Paper Original.

The tape preparation equipment draws its power from the computer and the

110V and 50V supplies should be switched on. The three-bank keyboard of the perforator is similar in appearance to that of a typewriter but some of the upper case characters have been changed. The top bank is used for the digits 1 - 0, the middle bank for the block marking numbers 1 - 9, (labeled in red) and the lower bank for +, -, *, and the block number 0.

Perforating errors can be omitted in the subsequent copying processes. When a keying mistake is noticed, backspace by using the level near the perforating head, perforate "letters shift" (5 holes) over the incorrect row and all rows which follow it and then repeat correctly. The row of tape which has just been perforated is visible immediately to the left of the perforating head.

5. Printing and Perforating Copies.

The tape copying equipment has two inputs, tape readers A and. B, selected by a key; and two outputs, the printer and the reperforator, also selected by a key. The input may either be copied exactly ("copy" key operated) or certain codes may be omitted (key in "Edit" position). The codes which are omitted are selected by a key having three positions. "Blank", "Blank and Erase", and "Erase". As the Erase" code is also the code for "Letters Shift" it is essential both to edit and erase codes when printing matter containing figures only and also to copy erase codes when printing a mixture of letters and figures.

To reproduce a tape, load the original into one of the tape readers and select the appropriate input, output and whether a direct or edited copy is required. Operate the "Motor On" control and then the "start" control. At the end of the tape operate the "Stop" control. The "Single Row" control may be used when only a few rows are to be copied or when it is essential to stop exactly on a particular row. When at rest the row standing in the gate of the tape reader has not been copied.

Blank tape may be run out of the reperforator by using the "Edit Run-out" key when the perforator is selected as the output and the motor is running. If the printer is selected as the output and the motor is running the "Edit Run-out" key causes the printer to be set to the "figures Shift" position; it does not run out unprinted tape.

It is advisable to check copies against the original tape. This can be done by holding the two tapes together and viewing against the light.
Badly worn tapes may often be copied more successfully if they pass through the tape reader inverted and reversed. This has the double advantage that the tape is driven by the unworn edges of the feed holes and the reading pins bear against the raised side of the distorted tape. The tape readers associated with the copying equipment operate with a greater pressure on the reading pins than the other readers and so unless the tape is inverted they may fail to copy correctly a tape which has been found worn but serviceable in the computer.

Splice the tape into loops by cutting the ends to a blunt point, allowing an overlap of two or three rows. Coat both ends sparingly with thick paste on one side and join ,with the leading end on top. The joint should be lined up carefully to ensure that there is no discontinuity at the edges and that the feed holes are clear. Press the joint together firmly and dry thoroughly before use. Avoid excess paste on the linen tape as the starch impregnation is easily removed by moisture.

6. Reading the Perforated Tape.

The accuracy of the perforated tape is usually checked by printing out the contents but, when modifying or correcting a tape or when experimenting with a new programme, it is useful to be able to read the perforations visually.

The five positions in which holes may be perforated are labelled "a" to “e”. Holes a and b are separated from holes c, d and e by the smaller feed hole.

The codes with only one hole per row are :-

Code | Perforations | Use
| E D C B A
A | 0 | + Sign
B | O | Line Feed *
C | O | Space
D | O | Carriage Return *
E | O | - Sign
* Not used during the preparation of tapes

The codes with two holes per row represent the tens digit :-

Code | Perforations | Use
E D C B A
BA | O O | 0
EB | O O | 2
DC | O O | 4
ED | O O | 6
AE | O | O | 8
Code | Perforations | Use
E D C B A
CA | O | O | 1
DB | O | O | 3
EC | O | O | 5
AD | O | O | 7
BE | O | O | 9

The codes with three holes per row represent the ten block marking characters and are the complement of the corresponding digit codes e.g. block marking character 1 is codes BDE and digit 1 is coded AC

Code | Perforations | Use
E D C B A
EDEB | O O O | O | Asterisk
AEDC | O | Decimal Point *
BAED | O | Figures Shift
CBAE | O | Letter N only *
DEBA | O | Letter Only *
* Not used during the preparation of tapes

The five hole code is used for "Letters Shift" and also for erasures.

The perforations on the tape and the printed characters on paper slip have a similar spacing. This can often be used as a guide to a point on the tape with sufficient accuracy that only a few orders need be read visually. It will also be found that the most easily recognised codes are the asterisks (code bedc) and these/can often be a help when looking for a point on a tape.

III PREPARING THE PROGRAMME

### 1. Subdividing a programme on one tape

Any programme which is suitable for automatic computing is repetitive and usually consists of a number of repetitive sub-routines.

Consider a programme which has a sequence of orders, A, used to control
the initial intake of information and clear the stores, a sequence B which has to be repeated N times and during which it is necessary to repeat a third sequence C, m times. It would be possible to perforate all these orders on one loop or tape, heading sequence A with Block No.1 and sequences B and C with block numbers 2 and 3. It is easy to devise orders at the end of sequence B which will cause a search for block number 2 to occur -1 times and some other order e.g. 'Finish' the nth time sequence B is completed. At the appropriate point in Sequence B there can be an order causing a search for block number 3
so that sequence C is introduced. At the end of sequence C a simple routine can cause a return to block number 3 the first (m-1) times and a return to the correct point in sequence B ( marked with another Block number) after the m th application of sequence C.

This is the simplest arrangement of several sequences of orders but it wastes time, tape, and machine life. Although sequence A is needed once and sequence B n times both have to pass through the tape reader n x m times to give access to sequence C. Some improvement can be affected by perforating sequence C in times on the tape, but this may not be convenient if it makes the tape very
long or if m is variable.

It is usually only necessary to arrange several sequences on one tape if
a programme would otherwise require more than seven tape readers, and it is then usually possible to collect together several sequences of orders which are not used frequently.

### 2. Subdividing a programme on more than one tape

Continuing with the example of paragraph 1, it is more convenient to have sequences A, B, and C on separate loops of tape. Then these loops only pass through their tape readers 1, nay and n x m times respectively. Searching time is eliminated, the loops may be kept to reasonable lengths and there are no complications if n and m are variable. Furthermore if n x m is greater than the expected life of the tape, about 500 passages through the tape reader, it
may be possible to perforate sequence C n x m / 500 times in one loop of reasonable size.

### 3. Use of Stored orders

Under some circumstances it may be useful to store a sequence of orders
in successive stores, but as it takes longer to read orders from the stores than from the tape this is seldom profitable unless some advantage can be gained by performing arithmetical operations in the orders.

In the example above the sub-routine loop for sequence C must always transfer control back to sequence B and a simple 02 order is adequate. If sequence could be entered from either of the sequences A or B and must return control ,to the same sequence the transfer is more complicated. One solution is to have
a store in which sequence A or B, before control ay sequence C, writes an 021 order to transfer control to sequence A or B respectively. Then at the end
of sequence C a discrimination either repeat's C or transfers control to the stored order. This, in turn, transfers control to the tape reader from which it
was originally derived.

### 4. Some Arithmetical Difficulties

The points which are summarised here are peculiarities of this particular computer which have already been mentioned in preceding paragraphs.

(a) In all arithmetical orders the two addresses must not lie in the same group of stores with certain exceptions in the group 00 - 09.
(b) When adding or subtracting with a shift preset by an 08 order it is not possible to clear the sending store.
(c) The preset shift order (08) does not apply to additions or subtractions involving the input or output.
(d) The capacity of the accumulator is reduced during multiplication by a negative multiplier. See Section I, paragraph 6.
(e) The dividend must not be +0 (all 0's). If there is any risk that this may happen, take the precaution of subtracting 0 into the accumulator before each division, thus converting to into -0. If the dividend is +0 the computer stops with the A shift selected and no direct indication of the nature of the fault.
(f) Where an error of one unit in the quotient cannot be tolerated, or where it would look unsightly in the printed output change the sign of divisor and dividend, where necessary, to make the latter negative.
(g) The receiving address (quotient register) for division must be cleared. It is sometimes assumed that a store is ready for use as the quotient register if it has previously been the multiplier register.

If the multiplier was negative the register address will be cleared to -0 which is not suitable for the quotient register.

5. Completing the Loop.

The tape can be joined into a loop with no gap between the first and last orders if the first order is repeated or several rows of letters shift
are perforated after the last order. The highest standard of splicing is necessary if all the overlapping holes are to be exactly coincident. Such a loop of' tape
can be identified by a written label but there is a risk that copies will not
be marked and so cause confusion.

These difficulties have led to the practice of perforating an identification number at the head of each tape and a search order for block number 1 at the end of each order tape. The splice can then be of any length and only the feed holes need accurate alignment. All copies, both perforated and printed, carry the identification code, which should indicate :-

(a) The tape reader, so that a set of tapes can be loaded quickly.
(b) The job or programme so that tapes can be sorted and stored easily.
(c) The "Mark No" of the programme so that the latest modification can be distinguished.
6. Testing for Zero.

This computer represents zero in two ways, as +0 (all zero's) and -0 (all nines).

The form +0 is produced by clearing a store, adding one cleared store into another, subtracting -0 from +0, or by the clearance of a positive multiplier during multiplication. The form -0 is produced by all other operations, including subtracting +0 from +0 or by the clearance of a negative multiplier during multiplication.

A simple test for either form is that zero is the only number whose positive modulus can be added to -0 and give a negative result. Where the numbers to be tested are usually zero this test can be applied very easily by adding the modulus of each number into a store containing -0 and inspecting this store for negative sign. Whenever this system is used to test a number which is not zero the testing store has to be cleared and replaced at -0.

### 7. Controlling the repetition of a sub-routine

The test to determine when a sequence has been repeated n times can be arranged in several ways, but these fall into two classes which are illustrated here. If we write +n in a store and subtract unity from it during each repetition of the sequence the sign will change from + to - at the nth subtraction. On the other hand if we write -a in a store and add unity during each repetition, the sign changes from - to + at the n + 1 addition.
There is often some advantage to be gained by choosing the right form of this test.
8. Testing for the end of a numerical input tape.

Where a problem can only be expressed as "carry out this operation on as many numbers as you find on the input tape" it may be difficult to terminate the progress neatly.

If no particular action is required after reaching the end of the input tape the crude expedient of letting the tape reader step off the end of the tape and produce an alarm might suffice.

If some further action is needed, as would be the case if the computer were to print out the answer when the last item had been read in, it is possible to head the input tape with a number which indicates the number of items on the tape. The intake routine can then repeat while counting down from this number.

Where each item or a part of each item, on the input tape is always positive the last item can be indicated by perforating it with a negative sign. A test of
the sign of each item which is read in reveals the last item.
9. Reading into the Drain.

When it is necessary to pass over a few number groups on a wholly numerical tape it may be more convenient to do this by reading the unwanted groups into the drain rather than by marking the tape with a system of block numbers so that the next wanted group can be found.

10. Alternative orders for correct Round-Off.

Correct round off i.e. not using the random round off facility, is a good example of the method by which one of two alternative groups of orders can be chosen.

If the 8th digit of the accumulator is to be rounded off we require a sequence of orders which will add 5 into the 9th digit of the accumulator if the accumulator has a positive sign, but subtract 5 if the accumulator is negative. Assume we have 0.5 in store 20 and the tape reader in use is 03.

Suitable orders are :-

08900 Set shift J
01109 Examine the accumulator for +ve sign

05203 Conditional search for block Number 2
32009 Subtract 5 from 9ayh digit of accumulator using the shift J set above.
03303 Search for block number 3.

Block No.2.

12009 Add 5 into 9th digit of accumulator using the shift J set above.

Block No.3. and next order.

Correct round off for division follows the same general lines but as there is not a ninth digit in the quotient register the same effect can be produced by adding half the divisor into the dividend with the appropriate sign and Shift

11. Other examples of alternative orders.

Some systems of alternative orders need only one block number. For instance, if the sign of a specified store has to control whether a certain number is added or subtracted into the accumulator and cleared, one block number is sufficient. Assume that the controlling sign is in store 20, the number to be transferred to the accumulator is in store 21, and the tape reader is 03.

The following orders may be used :_

01120 Examine 20 for +ve sign
05203 Search for Block No. 2 (if 20 has +ve sign) 42109 Subtract and clear 21 into accumulator.

Block No.2.

22109 Add and clear 21 into accumulator.

Note that this last order will be carried out for both +ve and -ve sign in store 20, but in the latter case the order 42109 has already cleared stored 21.

The sign of a controlling store can also be used to modify a sub-routine by similar systems of alternative orders. This has been used where it is necessary to insert some modifications in a long sub-routine during its first application. The latter part of the sub-routine is made to write a number of known sign into the controlling store, but the previous tape writes in a number of opposite sign. The sign in this store is then an indication of the first application of the sub-routine. The alternatives are to have the modified routine as a separate tape or as a part of the preceding tape.

12. Refinements in printing layouts.

Before the printer is used in any programme it is usual to set the tabulation 0 (order 07000) and have an order to print out from any store. This prints no digits but feeds up five blank rows of paper suitable for inserting headings. The same order can be used between sections of a programme where a larger break than one clear line is desirable.

The appearance of the printed output is usually improved if it is split into groups of a few lines separated by a blank line. Where the programme does not naturally provide a control for such grouping it is often convenient to have
a separate tape for the printing orders. This tape can then contain several (usually four) repetitions of the printing orders for one line, ending with a number printed with layout 4 or 8 (single line feed) and then the printing orders for one line ending with layout 5 or 9 (two line feed). This tape, may only have the printing orders for the last number in the line (i.e. 4 orders with layout 4 or 8, followed by one order with layout 5 or 9) since the orders for the first and intermediate numbers on the line will probably be the same throughout the programme. It is usually simpler to have a separate tape than to have a counting-down routine which can recognise every nth line and control alternative printing orders.

Where the output is needed in more than five or six columns it is possible to print out the first five or six columns on printer 01 and the next five or six columns on printer 02 so that the sheets of paper may be joined later.

The tape preparation equipment can be used to print headings containing letters and figures by transferring the whole paper carriage to the tape copying printer.

13. Adding Block numbers to the perforated Output.

The two output layouts (1 and 2) which control perforated outputs precede the eight or five digits with a space, whereas it may be, essential to have aye block numbers on the tape when it is used subsequently as an input to the computer. The block numbers 0, 3, 6, 7, 8, 9 can be perforated, by keyboard perforator or hand punch, over the space row as these block numbers include hole "C". Other block numbers can only be introduced while copying the output· tape.

14. Clearing Stores.

When the computer is switched on the stores contain unwanted (but probably not random) numbers. There are two approaches to clearing out these number and subsequently providing clear stores where needed.

One system which has been used is that of clearing each store just before it is required for use. This has the advantage that the programmer can construct each part of the programme separately without considering which stores have been cleared by previous parts of the programme. This is often helpful when a programme has to be modified. It does not lead to the most economical use of clearing orders since these are essentially orders which leave a store cleared after it has been used.

Another alternative is to clear all stores at the beginning of the programme and then clear each store, as far as possible, after it is used. It is not necessary to write out or key the orders for clearing all the stores each time a programme is prepared. These orders may either by copied from a master tape or one tape reader can be reserved for a "store clearing sub-routine".

15. Estimating Running Time.

To obtain a rough estimate of the running time for a sequence of orders allow:-

Addition
Subtraction
0 orders, except search | 2 seconds
Reading in | 5 seconds
Printing out | 10 seconds
Multiplication | 15 seconds
Division
Search | 1.4 orders per second
| 0.8 eight digit numbers per second.

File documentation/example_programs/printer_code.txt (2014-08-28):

The National Museum of Computing (http://www.tnmoc.org)
This work is licensed under the Creative Commons 
Attribution-NonCommercial-ShareAlike 4.0 International License
http://creativecommons.org/licenses/by-nc-sa/4.0/

Printer code

abcde	Figure	Letter

00000	??	??
00001	-	X
00010	CR	CR
00011	6	Y
00100	SP	SP
00101	5	T
00110	4	R
00111	Block 0	B
01000	LF	LF
01001	9	O	
01010	3	E
01011	Block 1	A	
01100	2	W
01101	Block 7	J
01110	Block 8	K
01111	*	C
10000	+	Z
10001	8	I
10010	7	U
10011	Block 2	S
10100	1	Q
10101	Block 3	D
10110	Block 9	L
10111	.	V
11000	0	P
11001	Block 4	F
11010	Block 5	G
11011	Figure	Figure
11100	Block 6	H
11101	N?	N
11110	M?	M
11111	Letters	Letters

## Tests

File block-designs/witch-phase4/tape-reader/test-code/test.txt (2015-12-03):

=
>1
21000
22000
23000
24000
25000
26000
27000
20900
10110
+1.0000000
10130
+8.0000000
11020
11009
11060
07400
03202
02102
=
>1
11040
64050
20900
15009
25060
32030
01130
05202
16001
00100

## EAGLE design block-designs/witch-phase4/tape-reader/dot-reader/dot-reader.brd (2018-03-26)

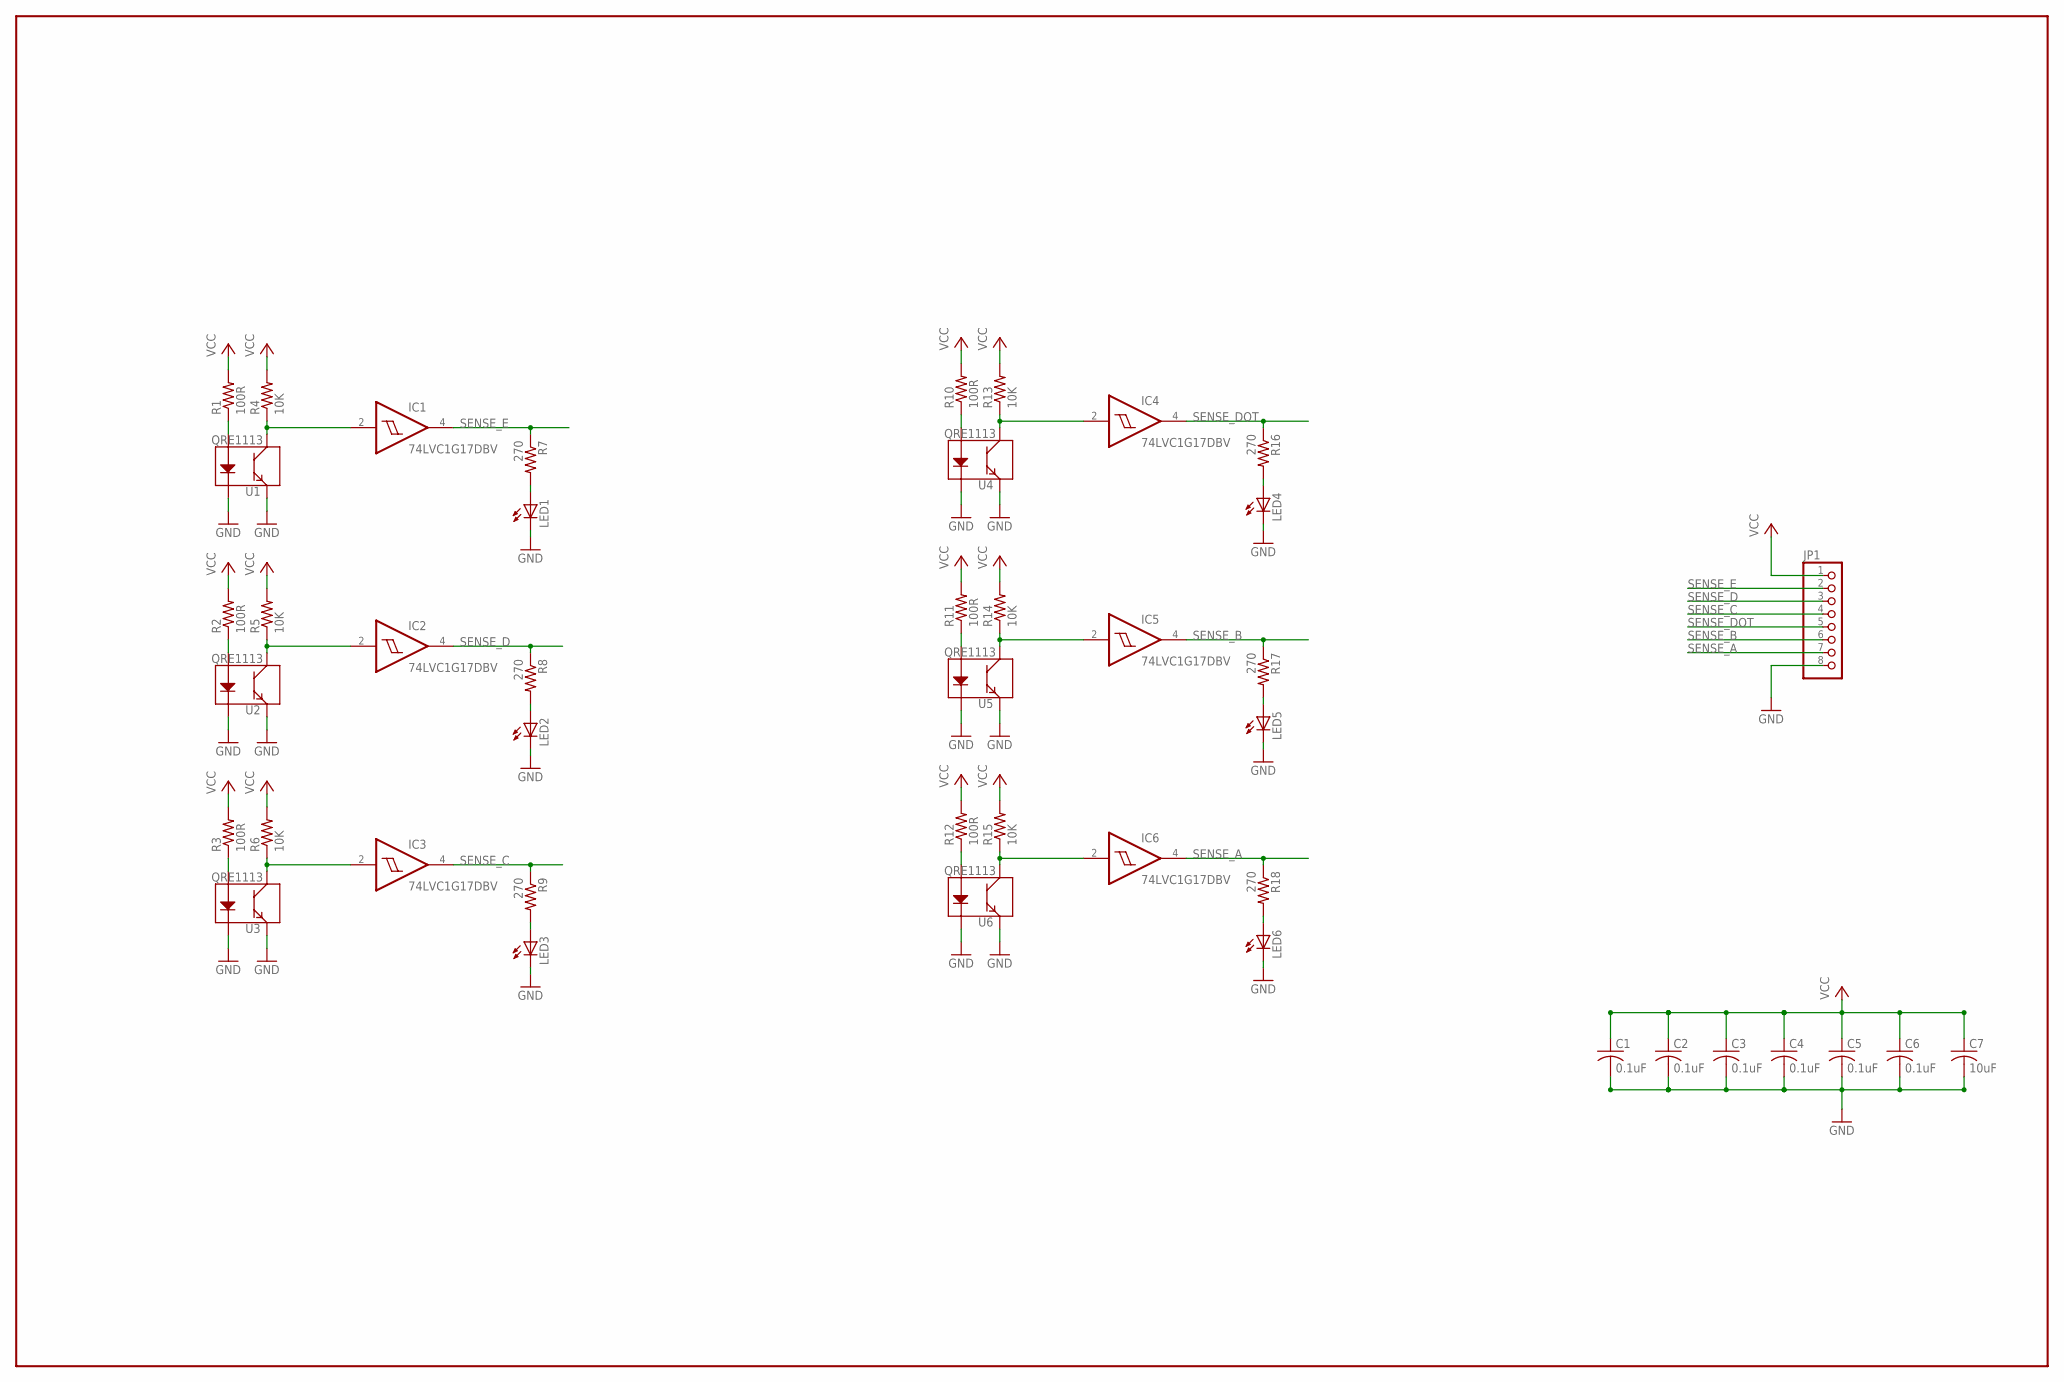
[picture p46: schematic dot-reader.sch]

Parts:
C1, C2, C3, C4, C5, C6: 0.1uF; C0603
C7: 10uF; C0805
IC1, IC2, IC3, IC4, IC5, IC6: 74LVC1G17DBV; SOT23-5
JP1: PINHD-1X8; 1X08
LED1, LED2, LED3, LED4, LED5, LED6: LEDCHIP-LED0805; CHIP-LED0805
R1, R2, R3, R10, R11, R12: 100R; M0805
R4, R5, R6, R13, R14, R15: 10K; M0805
R7, R8, R9, R16, R17, R18: 270; R0805
U1, U2, U3, U4, U5, U6: QRE1113

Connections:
A: IC1.2 (I), R4.1, U1.3 (C)
B: IC2.2 (I), R5.1, U2.3 (C)
C: IC4.2 (I), R13.1, U4.3 (C)
D: IC5.2 (I), R14.1, U5.3 (C)
DOT: IC3.2 (I), R6.1, U3.3 (C)
E: IC6.2 (I), R15.1, U6.3 (C)
GND: C1.2, C2.2, C3.2, C4.2, C5.2, C6.2, C7.2, IC1.3 (GND), IC2.3 (GND), IC3.3 (GND), IC4.3 (GND), IC5.3 (GND), IC6.3 (GND), JP1.8, LED1.C, LED2.C, LED3.C, LED4.C, LED5.C, LED6.C, U1.2 (K), U1.4 (E), U2.2 (K), U2.4 (E), U3.2 (K), U3.4 (E), U4.2 (K), U4.4 (E), U5.2 (K), U5.4 (E), U6.2 (K), U6.4 (E)
unnamed: R1.1, U1.1 (A)
unnamed: LED2.A, R8.2
unnamed: R2.1, U2.1 (A)
unnamed: LED4.A, R16.2
unnamed: R3.1, U3.1 (A)
unnamed: LED5.A, R17.2
unnamed: R10.1, U4.1 (A)
unnamed: LED3.A, R9.2
unnamed: R11.1, U5.1 (A)
unnamed: LED6.A, R18.2
unnamed: R12.1, U6.1 (A)
unnamed: LED1.A, R7.2
SENSE_A: IC6.4 (O), JP1.7, R18.1
SENSE_B: IC5.4 (O), JP1.6, R17.1
SENSE_C: IC3.4 (O), JP1.4, R9.1
SENSE_D: IC2.4 (O), JP1.3, R8.1
SENSE_DOT: IC4.4 (O), JP1.5, R16.1
SENSE_E: IC1.4 (O), JP1.2, R7.1
VCC: C1.1, C2.1, C3.1, C4.1, C5.1, C6.1, C7.1, IC1.5 (VCC), IC2.5 (VCC), IC3.5 (VCC), IC4.5 (VCC), IC5.5 (VCC), IC6.5 (VCC), JP1.1, R1.2, R2.2, R3.2, R4.2, R5.2, R6.2, R10.2, R11.2, R12.2, R13.2, R14.2, R15.2

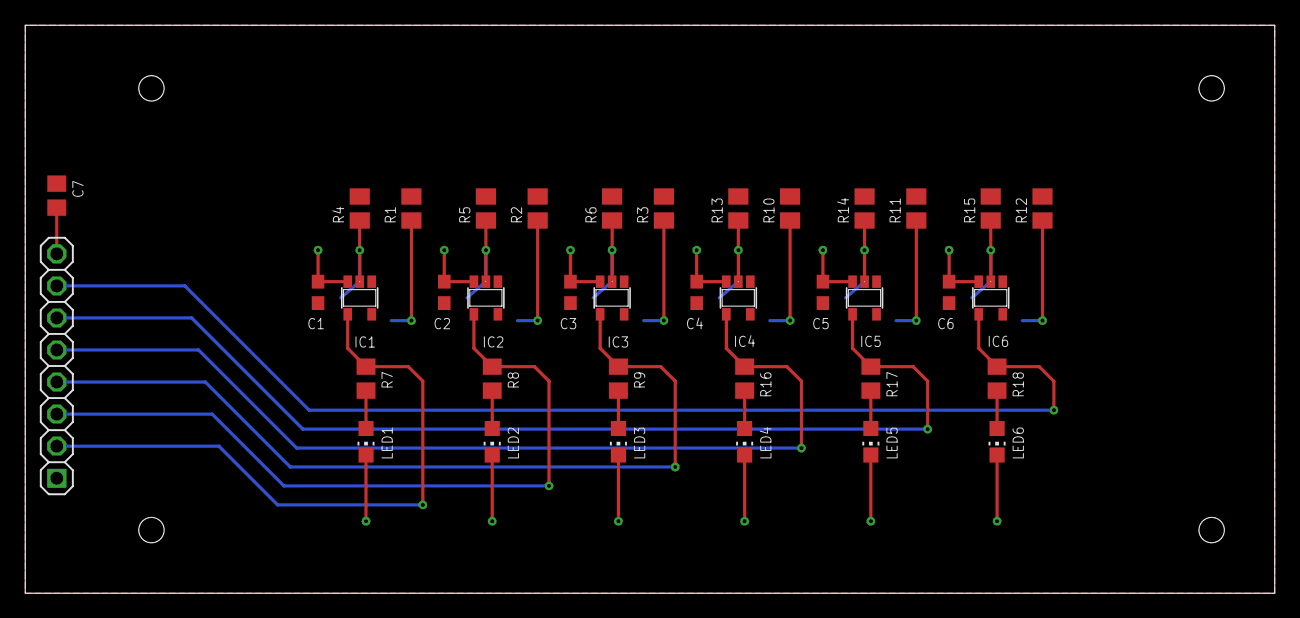
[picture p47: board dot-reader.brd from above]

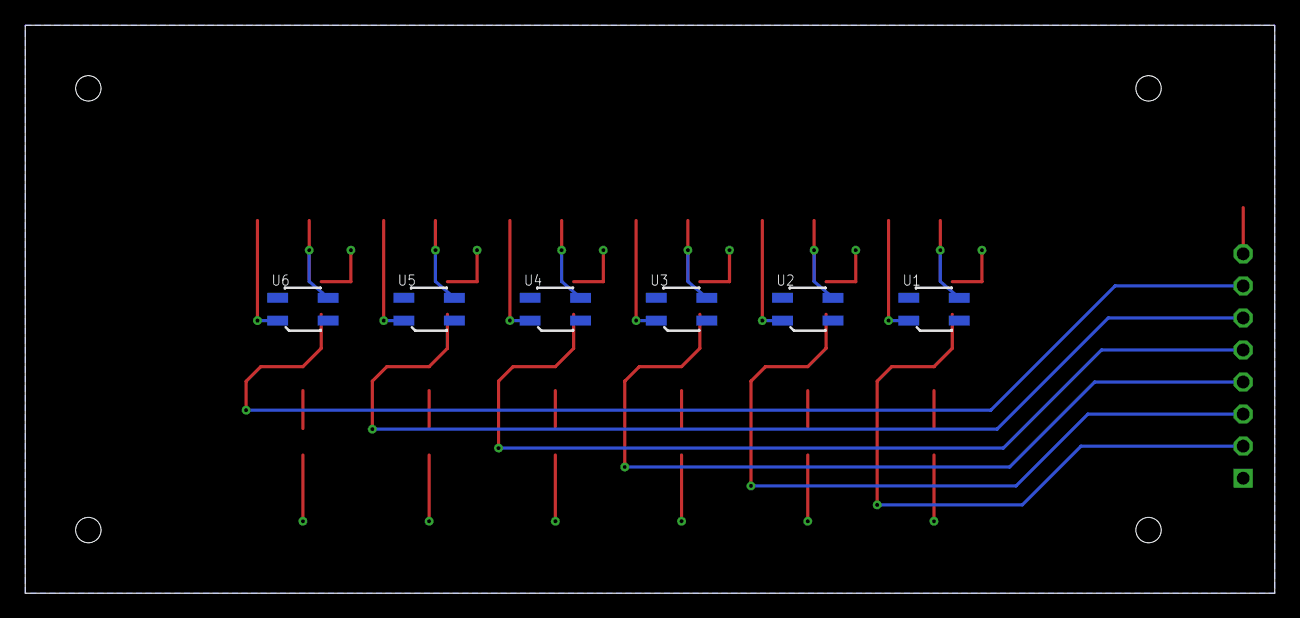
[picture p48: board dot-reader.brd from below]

Board: 2 copper layers, 99.0 x 45.0 mm, 44 parts (6 on the bottom side), 26 nets.

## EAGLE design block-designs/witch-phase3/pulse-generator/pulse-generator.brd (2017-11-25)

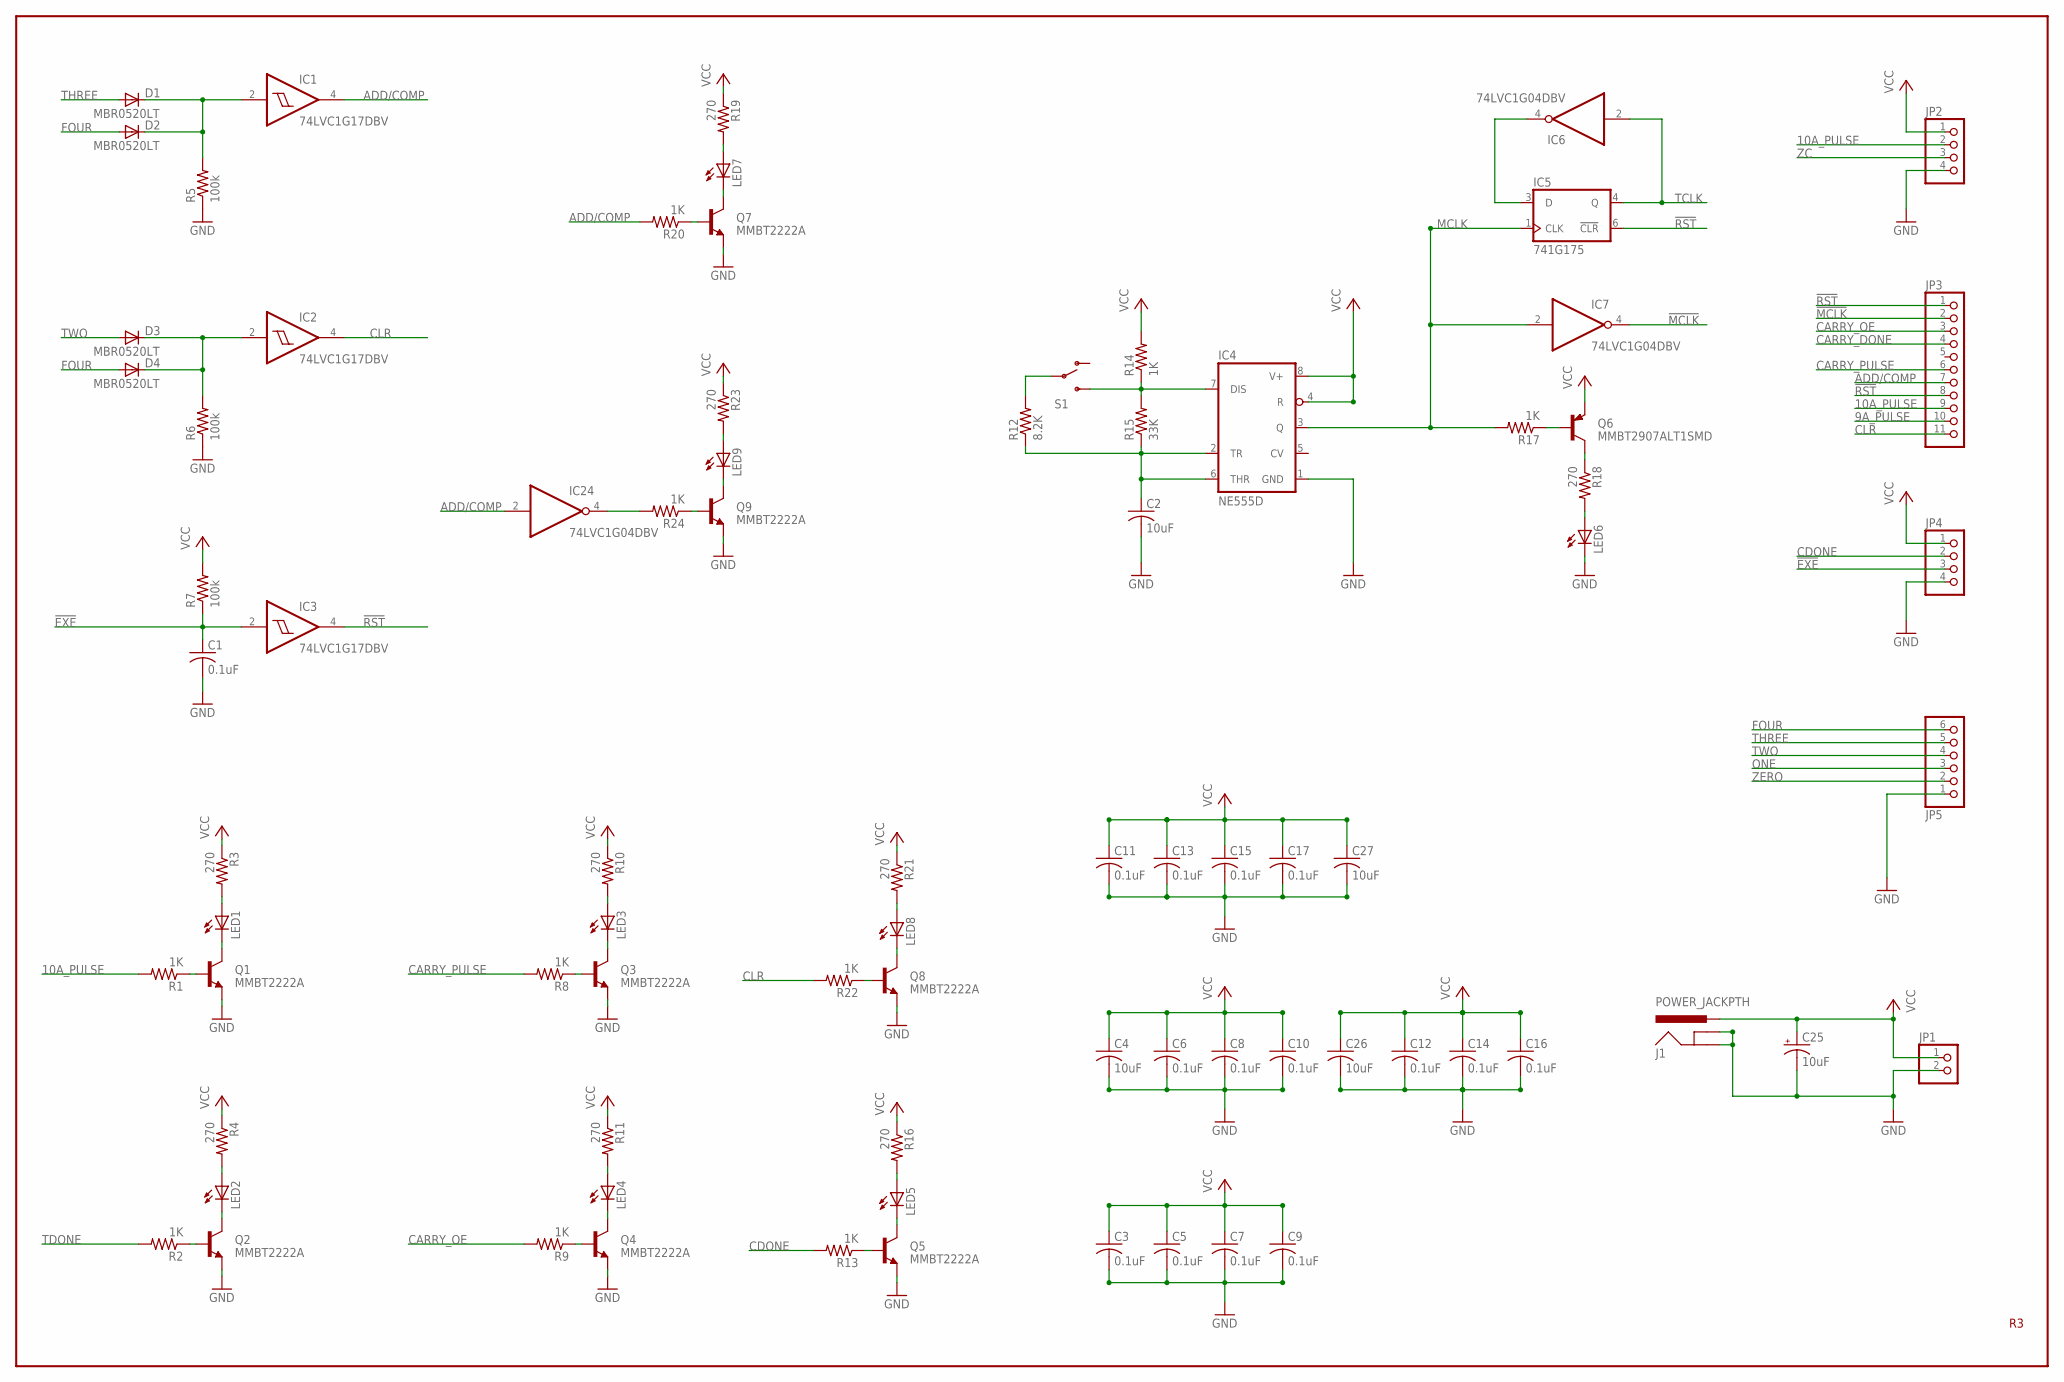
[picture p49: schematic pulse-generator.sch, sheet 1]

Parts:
C1, C7: 0.1uF; C0805
C2, C4, C26, C27: 10uF; C0805
C3, C5, C6, C8, C9, C10, C11, C12, C13, C14, C15, C16, C17: 0.1uF; C0603
C25: 10uF; EIA3216
D1, D2, D3, D4: MBR0520LT; SOD123
IC1, IC2, IC3: 74LVC1G17DBV; SOT23-5
IC4: NE555D; SO08
IC5: 741G175; DBV_R-PDSO-G6
IC6, IC7, IC24: 74LVC1G04DBV; SOT23-5
J1: POWER_JACKPTH; POWER_JACK_PTH
JP1: PINHD-1X2; 1X02
JP2, JP4: PINHD-1X4; 1X04
JP3: PINHD-1X11; 1X11
JP5: PINHD-1X6; 1X06
LED1, LED2, LED3, LED4, LED5, LED6, LED7, LED8, LED9: LEDCHIP-LED0805; CHIP-LED0805
Q1, Q2, Q3, Q4, Q5, Q7, Q8, Q9: MMBT2222A; SOT23-3
Q6: MMBT2907ALT1SMD; SOT23-BEC
R1, R2, R8, R9, R13, R14, R17, R20, R22, R24: 1K; R0805
R3, R4, R10, R11, R16, R18, R19, R21, R23: 270; R0805
R5, R6, R7: 100k; R0805
R12: 8.2K; R0805
R15: 33K; R0805
S1: SWITCH-SPDTPTH; SWITCH-SPDT

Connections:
9A_PULSE: JP3.10; also elsewhere on the board
10A_PULSE: JP2.2, JP3.9, R1.2; also elsewhere on the board
!EXE: C1.1, IC3.2 (I), JP4.3, R7.1
!MCLK: IC7.4 (O), JP3.2; also elsewhere on the board
!RST: IC3.4 (O), IC5.6 (!CLR), JP3.1, JP3.8; also elsewhere on the board
ADD/COMP: IC1.4 (O), IC24.2 (I), JP3.7, R20.2
CARRY_DONE: JP3.4; also elsewhere on the board
CARRY_OE: JP3.3, R9.2; also elsewhere on the board
CARRY_PULSE: JP3.6, R8.2; also elsewhere on the board
CDONE: JP4.2, R13.2; also elsewhere on the board
CLR: IC2.4 (O), JP3.11, R22.2
FOUR: D2.A, D4.A, JP5.6
GND: C1.2, C2.2, C3.2, C4.2, C5.2, C6.2, C7.2, C8.2, C9.2, C10.2, C11.2, C12.2, C13.2, C14.2, C15.2, C16.2, C17.2, C25.C (-), C26.2, C27.2, IC1.3 (GND), IC2.3 (GND), IC3.3 (GND), IC4.1 (GND), IC5.2 (GND), IC6.3 (GND), IC7.3 (GND), IC24.3 (GND), J1.GND, J1.GNDBREAK, JP1.2, JP2.4, JP4.4, JP5.1, LED6.C, Q1.2 (E), Q2.2 (E), Q3.2 (E), Q4.2 (E), Q5.2 (E), Q7.2 (E), Q8.2 (E), Q9.2 (E), R5.1, R6.1; also elsewhere on the board
MCLK: IC4.3 (Q), IC5.1 (CLK), IC7.2 (I), R17.2
unnamed: IC5.3 (D), IC6.4 (O)
unnamed: C2.1, IC4.2 (TR), IC4.6 (THR), R12.1, R15.1
unnamed: IC4.7 (DIS), R14.1, R15.2, S1.3 (S)
unnamed: R12.2, S1.2
unnamed: Q6.B, R17.1
unnamed: Q6.C, R18.1
unnamed: LED6.A, R18.2
unnamed: LED3.C, Q3.3 (C)
unnamed: LED7.C, Q7.3 (C)
unnamed: LED1.C, Q1.3 (C)
unnamed: Q7.1 (B), R20.1
unnamed: D1.C, D2.C, IC1.2 (I), R5.2
unnamed: D3.C, D4.C, IC2.2 (I), R6.2
unnamed: LED7.A, R19.2
unnamed: LED8.C, Q8.3 (C)
unnamed: Q8.1 (B), R22.1
unnamed: Q3.1 (B), R8.1
unnamed: LED3.A, R10.2
unnamed: Q1.1 (B), R1.1
unnamed: LED8.A, R21.2
unnamed: LED1.A, R3.2
unnamed: LED9.C, Q9.3 (C)
unnamed: Q9.1 (B), R24.1
unnamed: LED2.C, Q2.3 (C)
unnamed: Q2.1 (B), R2.1
unnamed: LED2.A, R4.2
unnamed: LED4.C, Q4.3 (C)
unnamed: Q4.1 (B), R9.1
unnamed: LED4.A, R11.2
unnamed: LED5.C, Q5.3 (C)
unnamed: Q5.1 (B), R13.1
unnamed: LED5.A, R16.2
unnamed: LED9.A, R23.2
unnamed: IC24.4 (O), R24.2
ONE: JP5.3
TCLK: IC5.4 (Q), IC6.2 (I); also elsewhere on the board
TDONE: R2.2; also elsewhere on the board
THREE: D1.A, JP5.5
TWO: D3.A, JP5.4
VCC: C3.1, C4.1, C5.1, C6.1, C7.1, C8.1, C9.1, C10.1, C11.1, C12.1, C13.1, C14.1, C15.1, C16.1, C17.1, C25.A (+), C26.1, C27.1, IC1.5 (VCC), IC2.5 (VCC), IC3.5 (VCC), IC4.4 (R), IC4.8 (V+), IC5.5 (VCC), IC6.5 (VCC), IC7.5 (VCC), IC24.5 (VCC), J1.PWR, JP1.1, JP2.1, JP4.1, Q6.E, R3.1, R4.1, R7.2, R10.1, R11.1, R14.2, R16.1, R19.1, R21.1, R23.1; also elsewhere on the board
ZC: JP2.3; also elsewhere on the board
ZERO: JP5.2

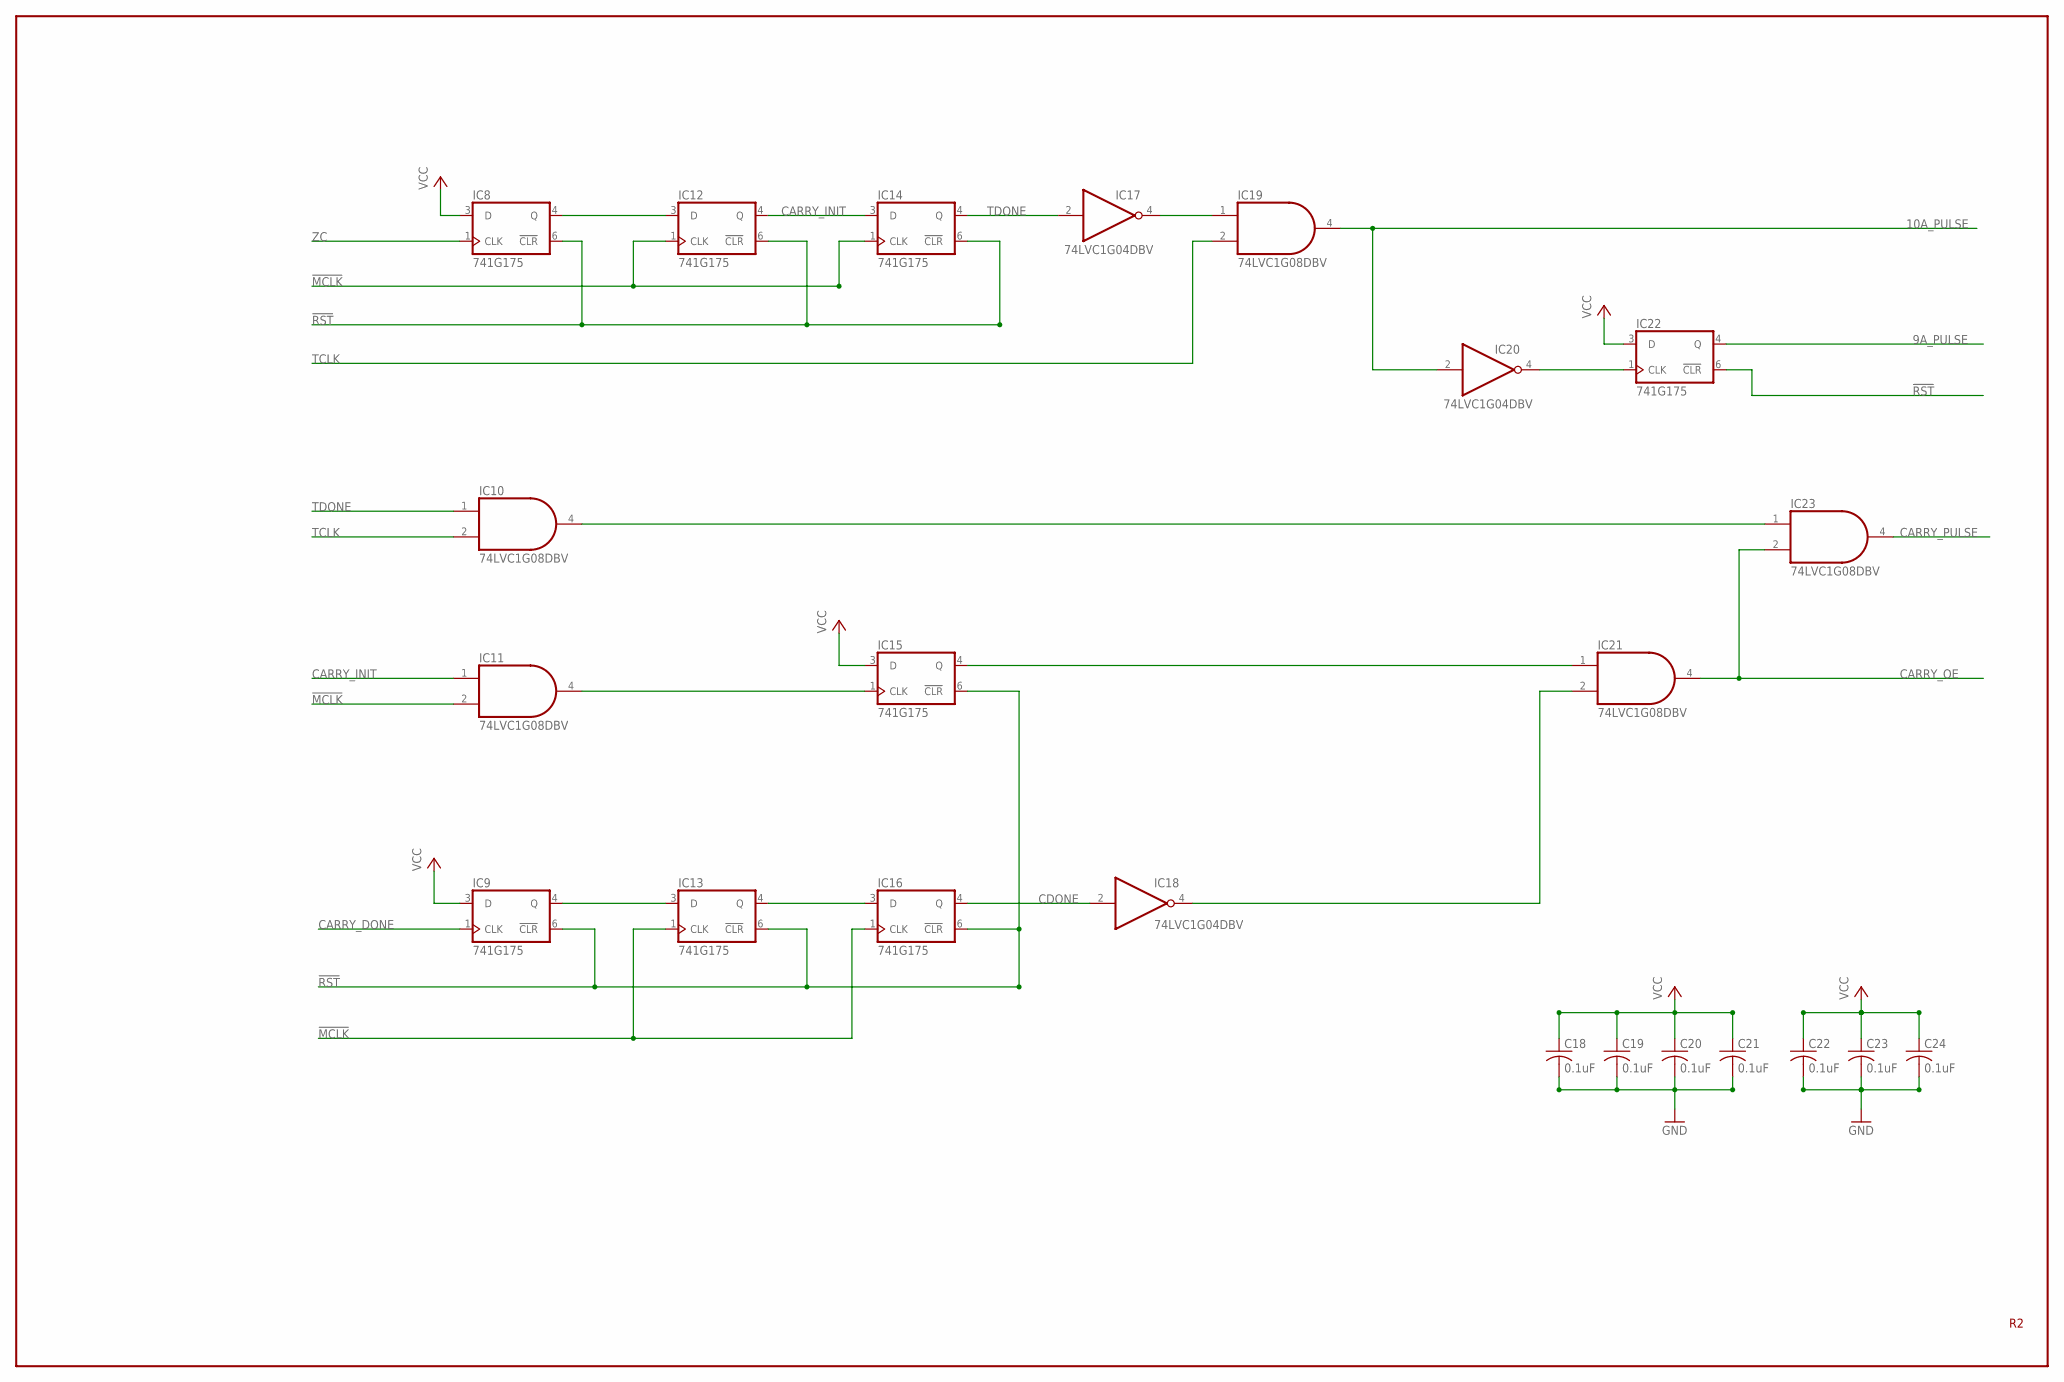
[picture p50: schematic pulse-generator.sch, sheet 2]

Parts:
C18, C19, C20, C21, C22, C23, C24: 0.1uF; C0603
IC8, IC9, IC12, IC13, IC14, IC15, IC16, IC22: 741G175; DBV_R-PDSO-G6
IC10, IC11, IC19, IC21, IC23: 74LVC1G08DBV; SOT23-5
IC17, IC18, IC20: 74LVC1G04DBV; SOT23-5

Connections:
9A_PULSE: IC22.4 (Q); also elsewhere on the board
10A_PULSE: IC19.4 (O), IC20.2 (I); also elsewhere on the board
!CDONE: IC18.4 (O), IC21.2 (I1)
!MCLK: IC11.2 (I1), IC12.1 (CLK), IC13.1 (CLK), IC14.1 (CLK), IC16.1 (CLK); also elsewhere on the board
!RST: IC8.6 (!CLR), IC9.6 (!CLR), IC12.6 (!CLR), IC13.6 (!CLR), IC14.6 (!CLR), IC15.6 (!CLR), IC16.6 (!CLR), IC22.6 (!CLR); also elsewhere on the board
!TDONE: IC17.4 (O), IC19.1 (I0)
CARRY_DONE: IC9.1 (CLK); also elsewhere on the board
CARRY_INIT: IC11.1 (I0), IC12.4 (Q), IC14.3 (D)
CARRY_OE: IC21.4 (O), IC23.2 (I1); also elsewhere on the board
CARRY_PULSE: IC23.4 (O); also elsewhere on the board
CDONE: IC16.4 (Q), IC18.2 (I); also elsewhere on the board
GND: C18.2, C19.2, C20.2, C21.2, C22.2, C23.2, C24.2, IC8.2 (GND), IC9.2 (GND), IC10.3 (GND), IC11.3 (GND), IC12.2 (GND), IC13.2 (GND), IC14.2 (GND), IC15.2 (GND), IC16.2 (GND), IC17.3 (GND), IC18.3 (GND), IC19.3 (GND), IC20.3 (GND), IC21.3 (GND), IC22.2 (GND), IC23.3 (GND); also elsewhere on the board
unnamed: IC8.4 (Q), IC12.3 (D)
unnamed: IC10.4 (O), IC23.1 (I0)
unnamed: IC9.4 (Q), IC13.3 (D)
unnamed: IC15.4 (Q), IC21.1 (I0)
unnamed: IC11.4 (O), IC15.1 (CLK)
unnamed: IC13.4 (Q), IC16.3 (D)
unnamed: IC20.4 (O), IC22.1 (CLK)
TCLK: IC10.2 (I1), IC19.2 (I1); also elsewhere on the board
TDONE: IC10.1 (I0), IC14.4 (Q), IC17.2 (I); also elsewhere on the board
VCC: C18.1, C19.1, C20.1, C21.1, C22.1, C23.1, C24.1, IC8.3 (D), IC8.5 (VCC), IC9.3 (D), IC9.5 (VCC), IC10.5 (VCC), IC11.5 (VCC), IC12.5 (VCC), IC13.5 (VCC), IC14.5 (VCC), IC15.3 (D), IC15.5 (VCC), IC16.5 (VCC), IC17.5 (VCC), IC18.5 (VCC), IC19.5 (VCC), IC20.5 (VCC), IC21.5 (VCC), IC22.3 (D), IC22.5 (VCC), IC23.5 (VCC); also elsewhere on the board
ZC: IC8.1 (CLK); also elsewhere on the board

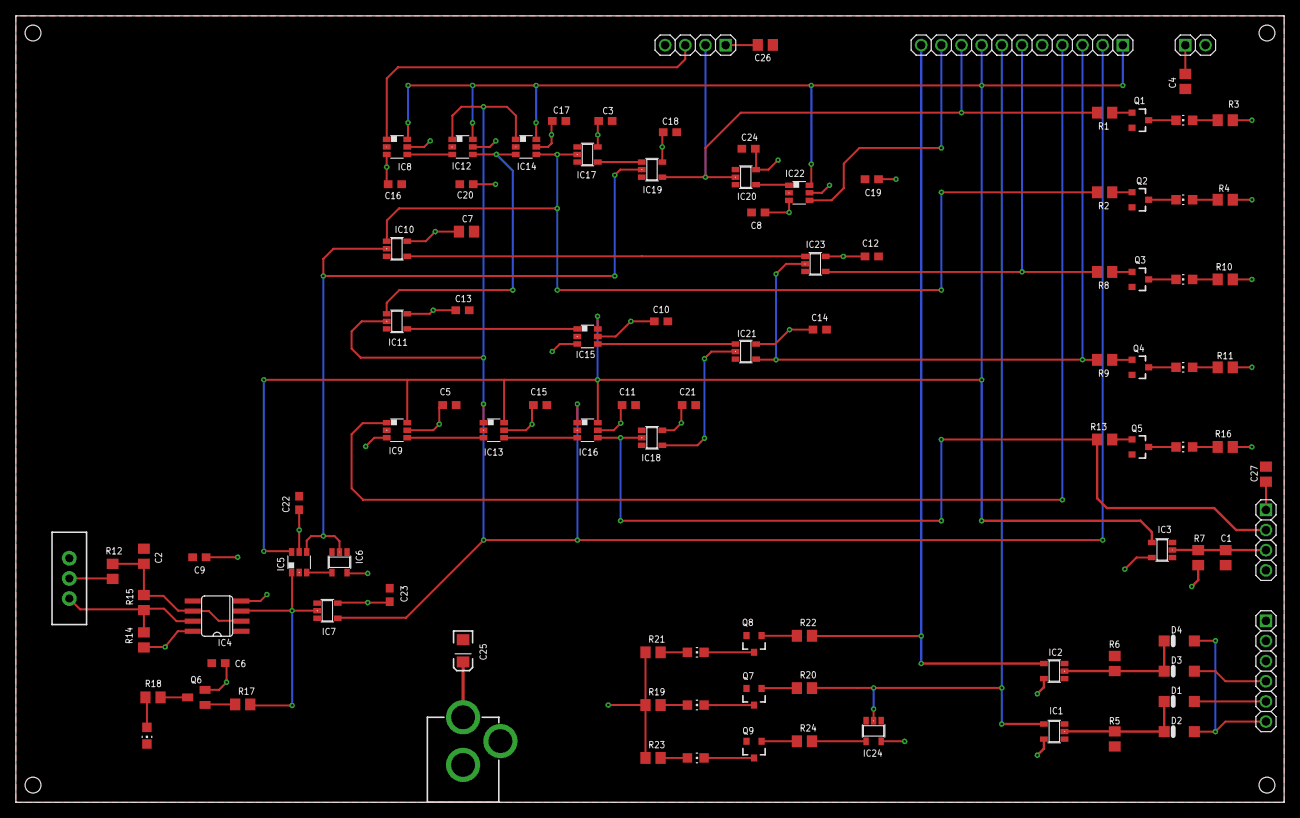
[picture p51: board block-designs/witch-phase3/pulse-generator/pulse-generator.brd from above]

Board: 2 copper layers, 159.8 x 99.1 mm, 104 parts (0 on the bottom side), 64 nets.

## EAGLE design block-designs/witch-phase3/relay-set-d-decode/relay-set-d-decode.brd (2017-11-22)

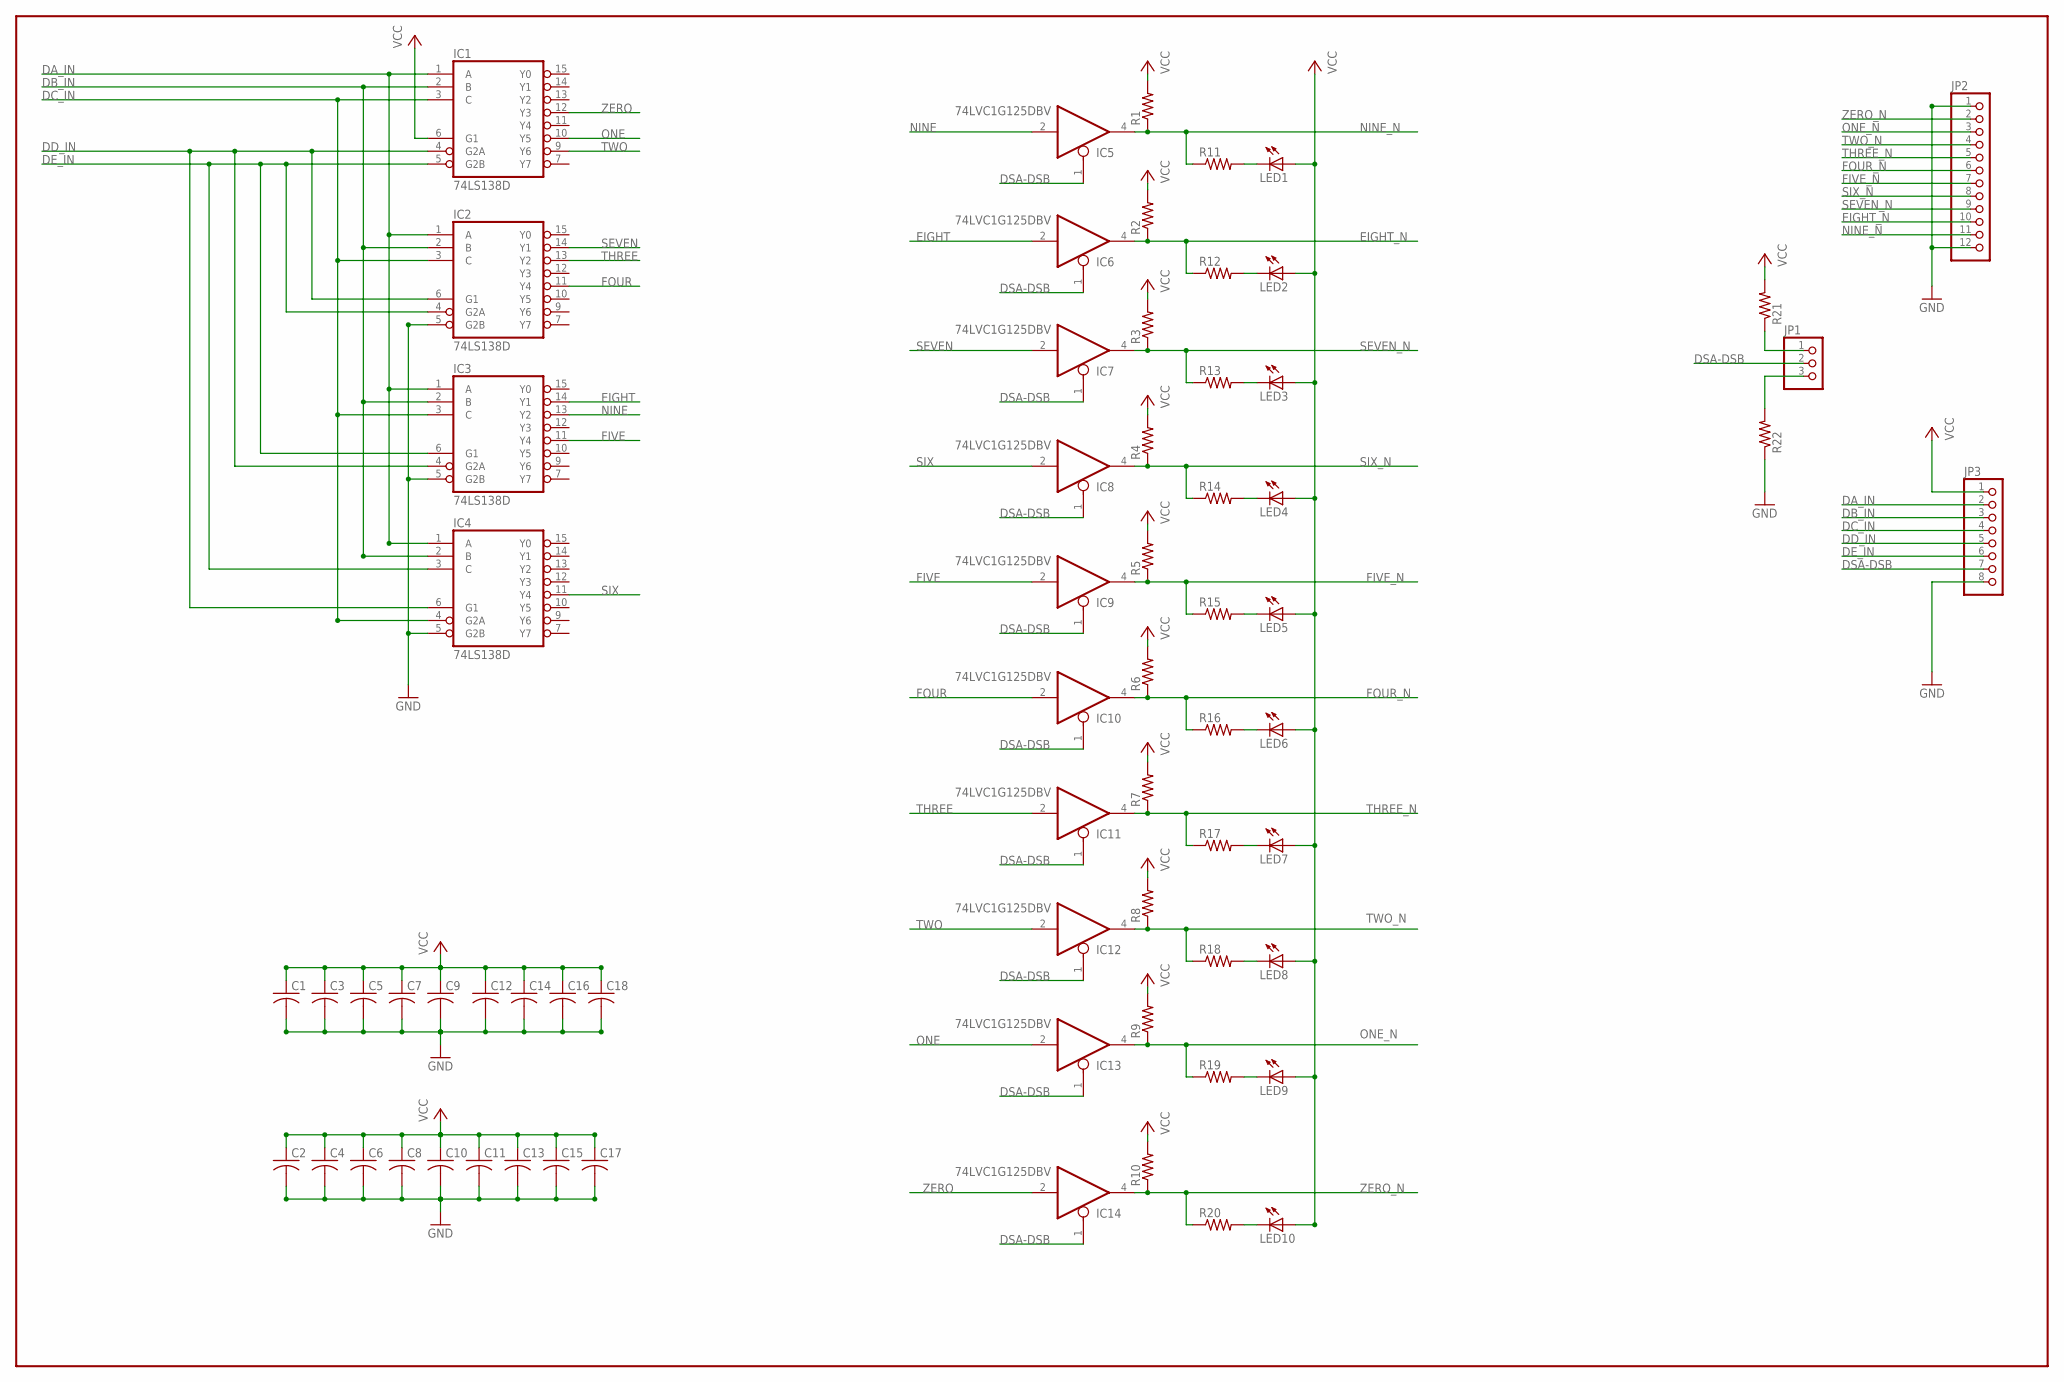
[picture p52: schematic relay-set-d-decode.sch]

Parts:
C1, C2, C3, C4, C6, C8, C10, C11, C12, C13, C14, C15, C16, C17, C18: C-USC0603; C0603
C5, C7, C9: C-USC0805; C0805
IC1, IC2, IC3, IC4: 74LS138D; SO16
IC5, IC6, IC7, IC8, IC9, IC10, IC11, IC12, IC13, IC14: 74LVC1G125DBV; SOT23-5
JP1: PINHD-1X3; 1X03
JP2: PINHD-1X12; 1X12
JP3: PINHD-1X8; 1X08
LED1, LED2, LED3, LED4, LED5, LED6, LED7, LED8, LED9, LED10: LEDCHIP-LED0805; CHIP-LED0805
R1, R2, R3, R4, R5, R6, R7, R8, R9, R10, R11, R12, R13, R14, R15, R16, R17, R18, R19, R20, R21, R22: R-US_R0805; R0805

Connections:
DA_IN: IC1.1 (A), IC2.1 (A), IC3.1 (A), IC4.1 (A), JP3.2
DB_IN: IC1.2 (B), IC2.2 (B), IC3.2 (B), IC4.2 (B), JP3.3
DC_IN: IC1.3 (C), IC2.3 (C), IC3.3 (C), IC4.4 (G2A), JP3.4
DD_IN: IC1.4 (G2A), IC2.6 (G1), IC3.4 (G2A), IC4.6 (G1), JP3.5
DE_IN: IC1.5 (G2B), IC2.4 (G2A), IC3.6 (G1), IC4.3 (C), JP3.6
DSA-DSB: IC5.1 (OE), IC6.1 (OE), IC7.1 (OE), IC8.1 (OE), IC9.1 (OE), IC10.1 (OE), IC11.1 (OE), IC12.1 (OE), IC13.1 (OE), IC14.1 (OE), JP1.2, JP3.7
EIGHT: IC3.14 (Y1), IC6.2 (I)
EIGHT_N: IC6.4 (O), JP2.10, R2.1, R12.1
FIVE: IC3.11 (Y4), IC9.2 (I)
FIVE_N: IC9.4 (O), JP2.7, R5.1, R15.1
FOUR: IC2.11 (Y4), IC10.2 (I)
FOUR_N: IC10.4 (O), JP2.6, R6.1, R16.1
GND: C1.2, C2.2, C3.2, C4.2, C5.2, C6.2, C7.2, C8.2, C9.2, C10.2, C11.2, C12.2, C13.2, C14.2, C15.2, C16.2, C17.2, C18.2, IC1.8 (GND), IC2.5 (G2B), IC2.8 (GND), IC3.5 (G2B), IC3.8 (GND), IC4.5 (G2B), IC4.8 (GND), IC5.3 (GND), IC6.3 (GND), IC7.3 (GND), IC8.3 (GND), IC9.3 (GND), IC10.3 (GND), IC11.3 (GND), IC12.3 (GND), IC13.3 (GND), IC14.3 (GND), JP2.1, JP2.12, JP3.8, R22.1
unnamed: LED1.C, R11.2
unnamed: LED2.C, R12.2
unnamed: LED3.C, R13.2
unnamed: LED4.C, R14.2
unnamed: LED5.C, R15.2
unnamed: LED6.C, R16.2
unnamed: LED7.C, R17.2
unnamed: LED8.C, R18.2
unnamed: LED9.C, R19.2
unnamed: LED10.C, R20.2
unnamed: JP1.1, R21.1
unnamed: JP1.3, R22.2
NINE: IC3.13 (Y2), IC5.2 (I)
NINE_N: IC5.4 (O), JP2.11, R1.1, R11.1
ONE: IC1.10 (Y5), IC13.2 (I)
ONE_N: IC13.4 (O), JP2.3, R9.1, R19.1
SEVEN: IC2.14 (Y1), IC7.2 (I)
SEVEN_N: IC7.4 (O), JP2.9, R3.1, R13.1
SIX: IC4.11 (Y4), IC8.2 (I)
SIX_N: IC8.4 (O), JP2.8, R4.1, R14.1
THREE: IC2.13 (Y2), IC11.2 (I)
THREE_N: IC11.4 (O), JP2.5, R7.1, R17.1
TWO: IC1.9 (Y6), IC12.2 (I)
TWO_N: IC12.4 (O), JP2.4, R8.1, R18.1
VCC: C1.1, C2.1, C3.1, C4.1, C5.1, C6.1, C7.1, C8.1, C9.1, C10.1, C11.1, C12.1, C13.1, C14.1, C15.1, C16.1, C17.1, C18.1, IC1.6 (G1), IC1.16 (VCC), IC2.16 (VCC), IC3.16 (VCC), IC4.16 (VCC), IC5.5 (VCC), IC6.5 (VCC), IC7.5 (VCC), IC8.5 (VCC), IC9.5 (VCC), IC10.5 (VCC), IC11.5 (VCC), IC12.5 (VCC), IC13.5 (VCC), IC14.5 (VCC), JP3.1, LED1.A, LED2.A, LED3.A, LED4.A, LED5.A, LED6.A, LED7.A, LED8.A, LED9.A, LED10.A, R1.2, R2.2, R3.2, R4.2, R5.2, R6.2, R7.2, R8.2, R9.2, R10.2, R21.2
ZERO: IC1.12 (Y3), IC14.2 (I)
ZERO_N: IC14.4 (O), JP2.2, R10.1, R20.1

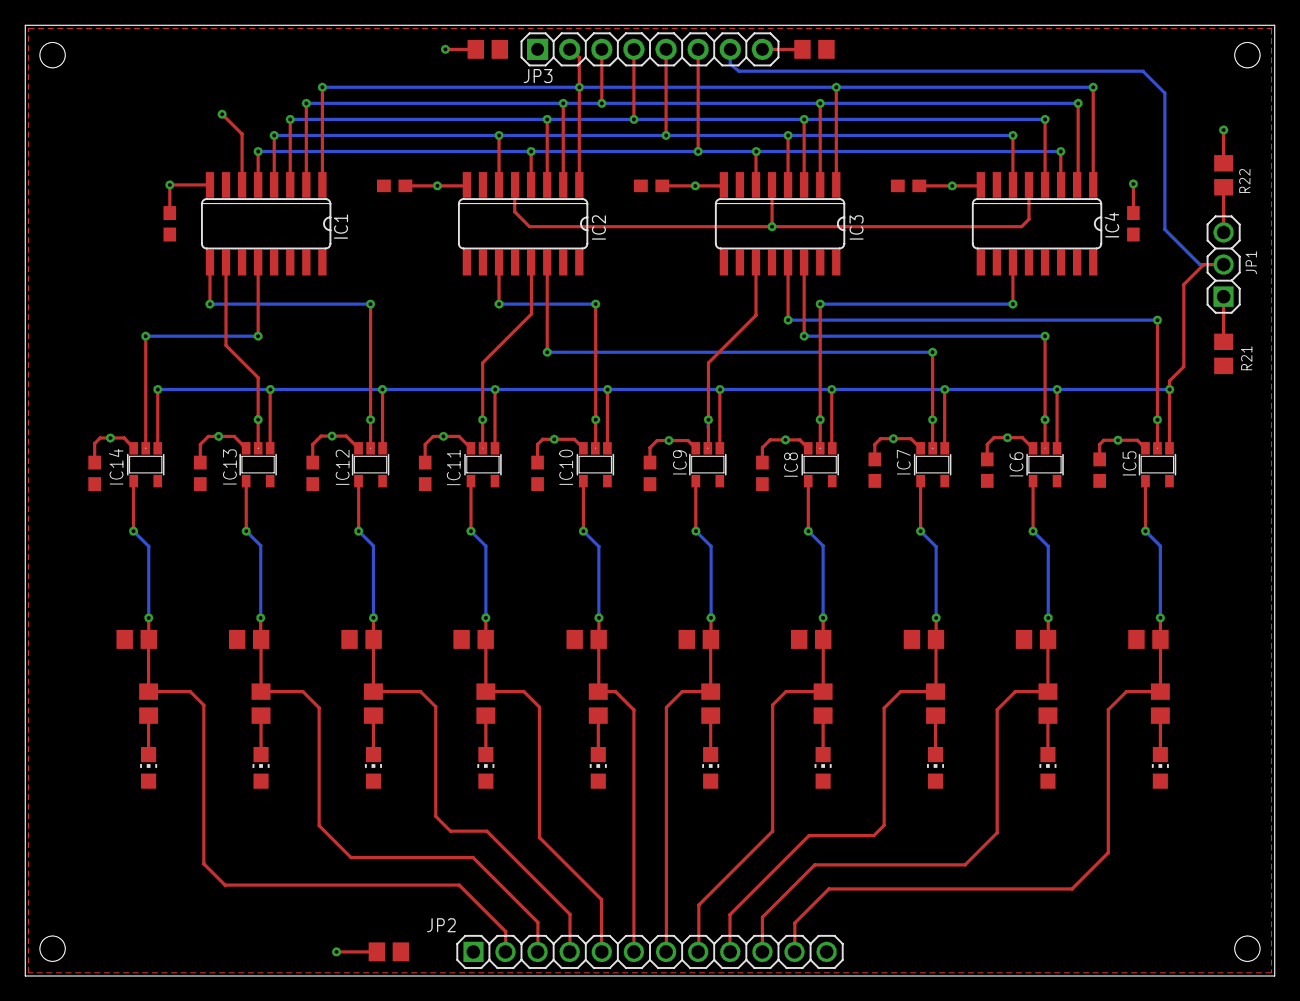
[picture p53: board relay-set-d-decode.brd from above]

Board: 2 copper layers, 98.8 x 75.2 mm, 67 parts (0 on the bottom side), 40 nets.

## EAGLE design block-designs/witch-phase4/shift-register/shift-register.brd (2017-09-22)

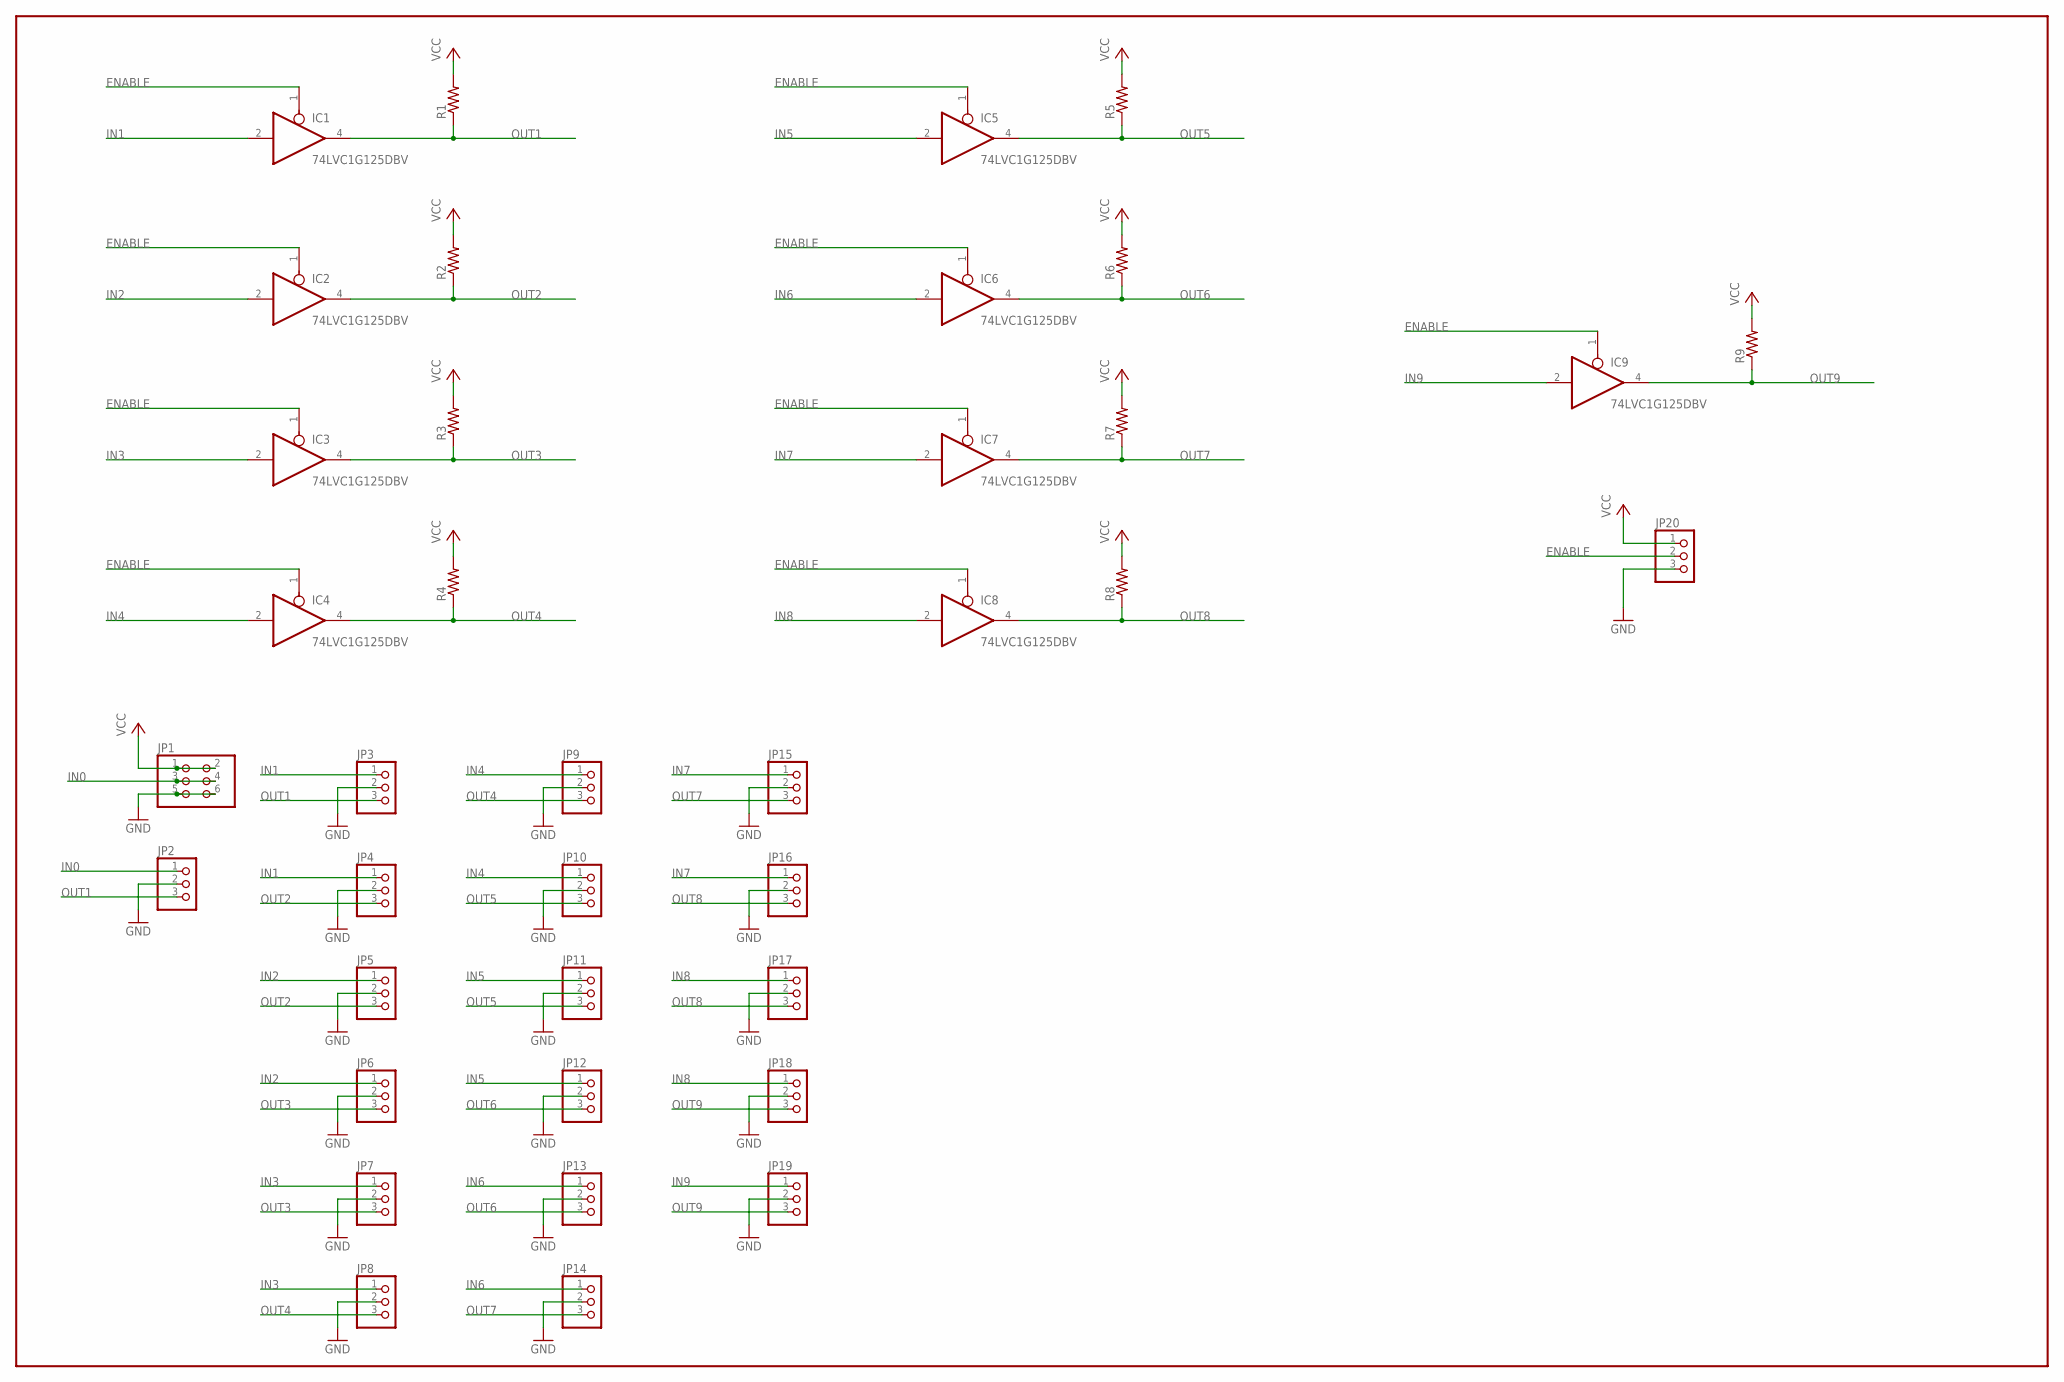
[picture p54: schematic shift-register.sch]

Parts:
IC1, IC2, IC3, IC4, IC5, IC6, IC7, IC8, IC9: 74LVC1G125DBV; SOT23-5
JP1: PINHD-2X3; 2X03
JP2, JP3, JP4, JP5, JP6, JP7, JP8, JP9, JP10, JP11, JP12, JP13, JP14, JP15, JP16, JP17, JP18, JP19, JP20: PINHD-1X3; 1X03
R1, R2, R3, R4, R5, R6, R7, R8, R9: R-US_R0603; R0603

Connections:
ENABLE: IC1.1 (OE), IC2.1 (OE), IC3.1 (OE), IC4.1 (OE), IC5.1 (OE), IC6.1 (OE), IC7.1 (OE), IC8.1 (OE), IC9.1 (OE), JP20.2
GND: IC1.3 (GND), IC2.3 (GND), IC3.3 (GND), IC4.3 (GND), IC5.3 (GND), IC6.3 (GND), IC7.3 (GND), IC8.3 (GND), IC9.3 (GND), JP1.5, JP1.6, JP2.2, JP3.2, JP4.2, JP5.2, JP6.2, JP7.2, JP8.2, JP9.2, JP10.2, JP11.2, JP12.2, JP13.2, JP14.2, JP15.2, JP16.2, JP17.2, JP18.2, JP19.2, JP20.3
IN0: JP1.3, JP1.4, JP2.1
IN1: IC1.2 (I), JP3.1, JP4.1
IN2: IC2.2 (I), JP5.1, JP6.1
IN3: IC3.2 (I), JP7.1, JP8.1
IN4: IC4.2 (I), JP9.1, JP10.1
IN5: IC5.2 (I), JP11.1, JP12.1
IN6: IC6.2 (I), JP13.1, JP14.1
IN7: IC7.2 (I), JP15.1, JP16.1
IN8: IC8.2 (I), JP17.1, JP18.1
IN9: IC9.2 (I), JP19.1
OUT1: IC1.4 (O), JP2.3, JP3.3, R1.1
OUT2: IC2.4 (O), JP4.3, JP5.3, R2.1
OUT3: IC3.4 (O), JP6.3, JP7.3, R3.1
OUT4: IC4.4 (O), JP8.3, JP9.3, R4.1
OUT5: IC5.4 (O), JP10.3, JP11.3, R5.1
OUT6: IC6.4 (O), JP12.3, JP13.3, R6.1
OUT7: IC7.4 (O), JP14.3, JP15.3, R7.1
OUT8: IC8.4 (O), JP16.3, JP17.3, R8.1
OUT9: IC9.4 (O), JP18.3, JP19.3, R9.1
VCC: IC1.5 (VCC), IC2.5 (VCC), IC3.5 (VCC), IC4.5 (VCC), IC5.5 (VCC), IC6.5 (VCC), IC7.5 (VCC), IC8.5 (VCC), IC9.5 (VCC), JP1.1, JP1.2, JP20.1, R1.2, R2.2, R3.2, R4.2, R5.2, R6.2, R7.2, R8.2, R9.2

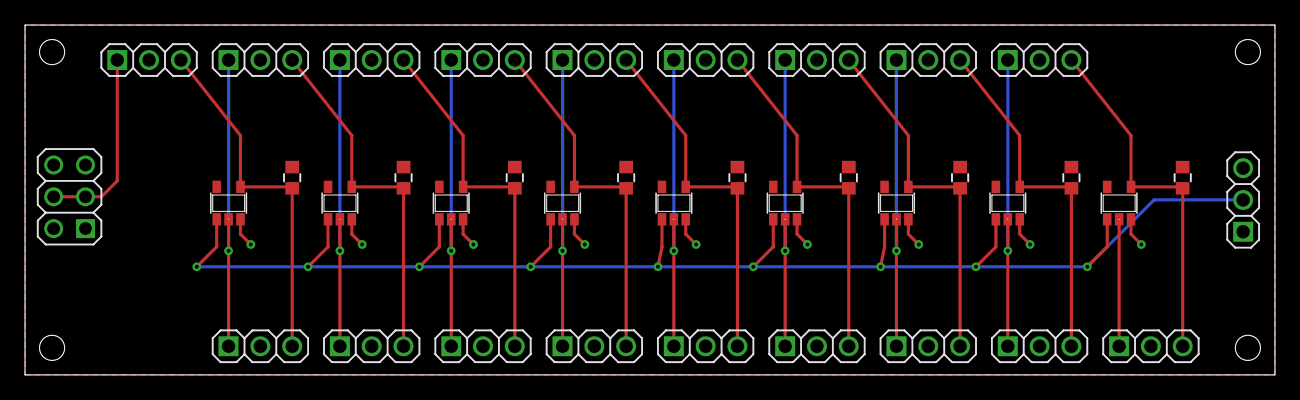
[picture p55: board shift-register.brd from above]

Board: 2 copper layers, 99.8 x 27.9 mm, 38 parts (0 on the bottom side), 22 nets.

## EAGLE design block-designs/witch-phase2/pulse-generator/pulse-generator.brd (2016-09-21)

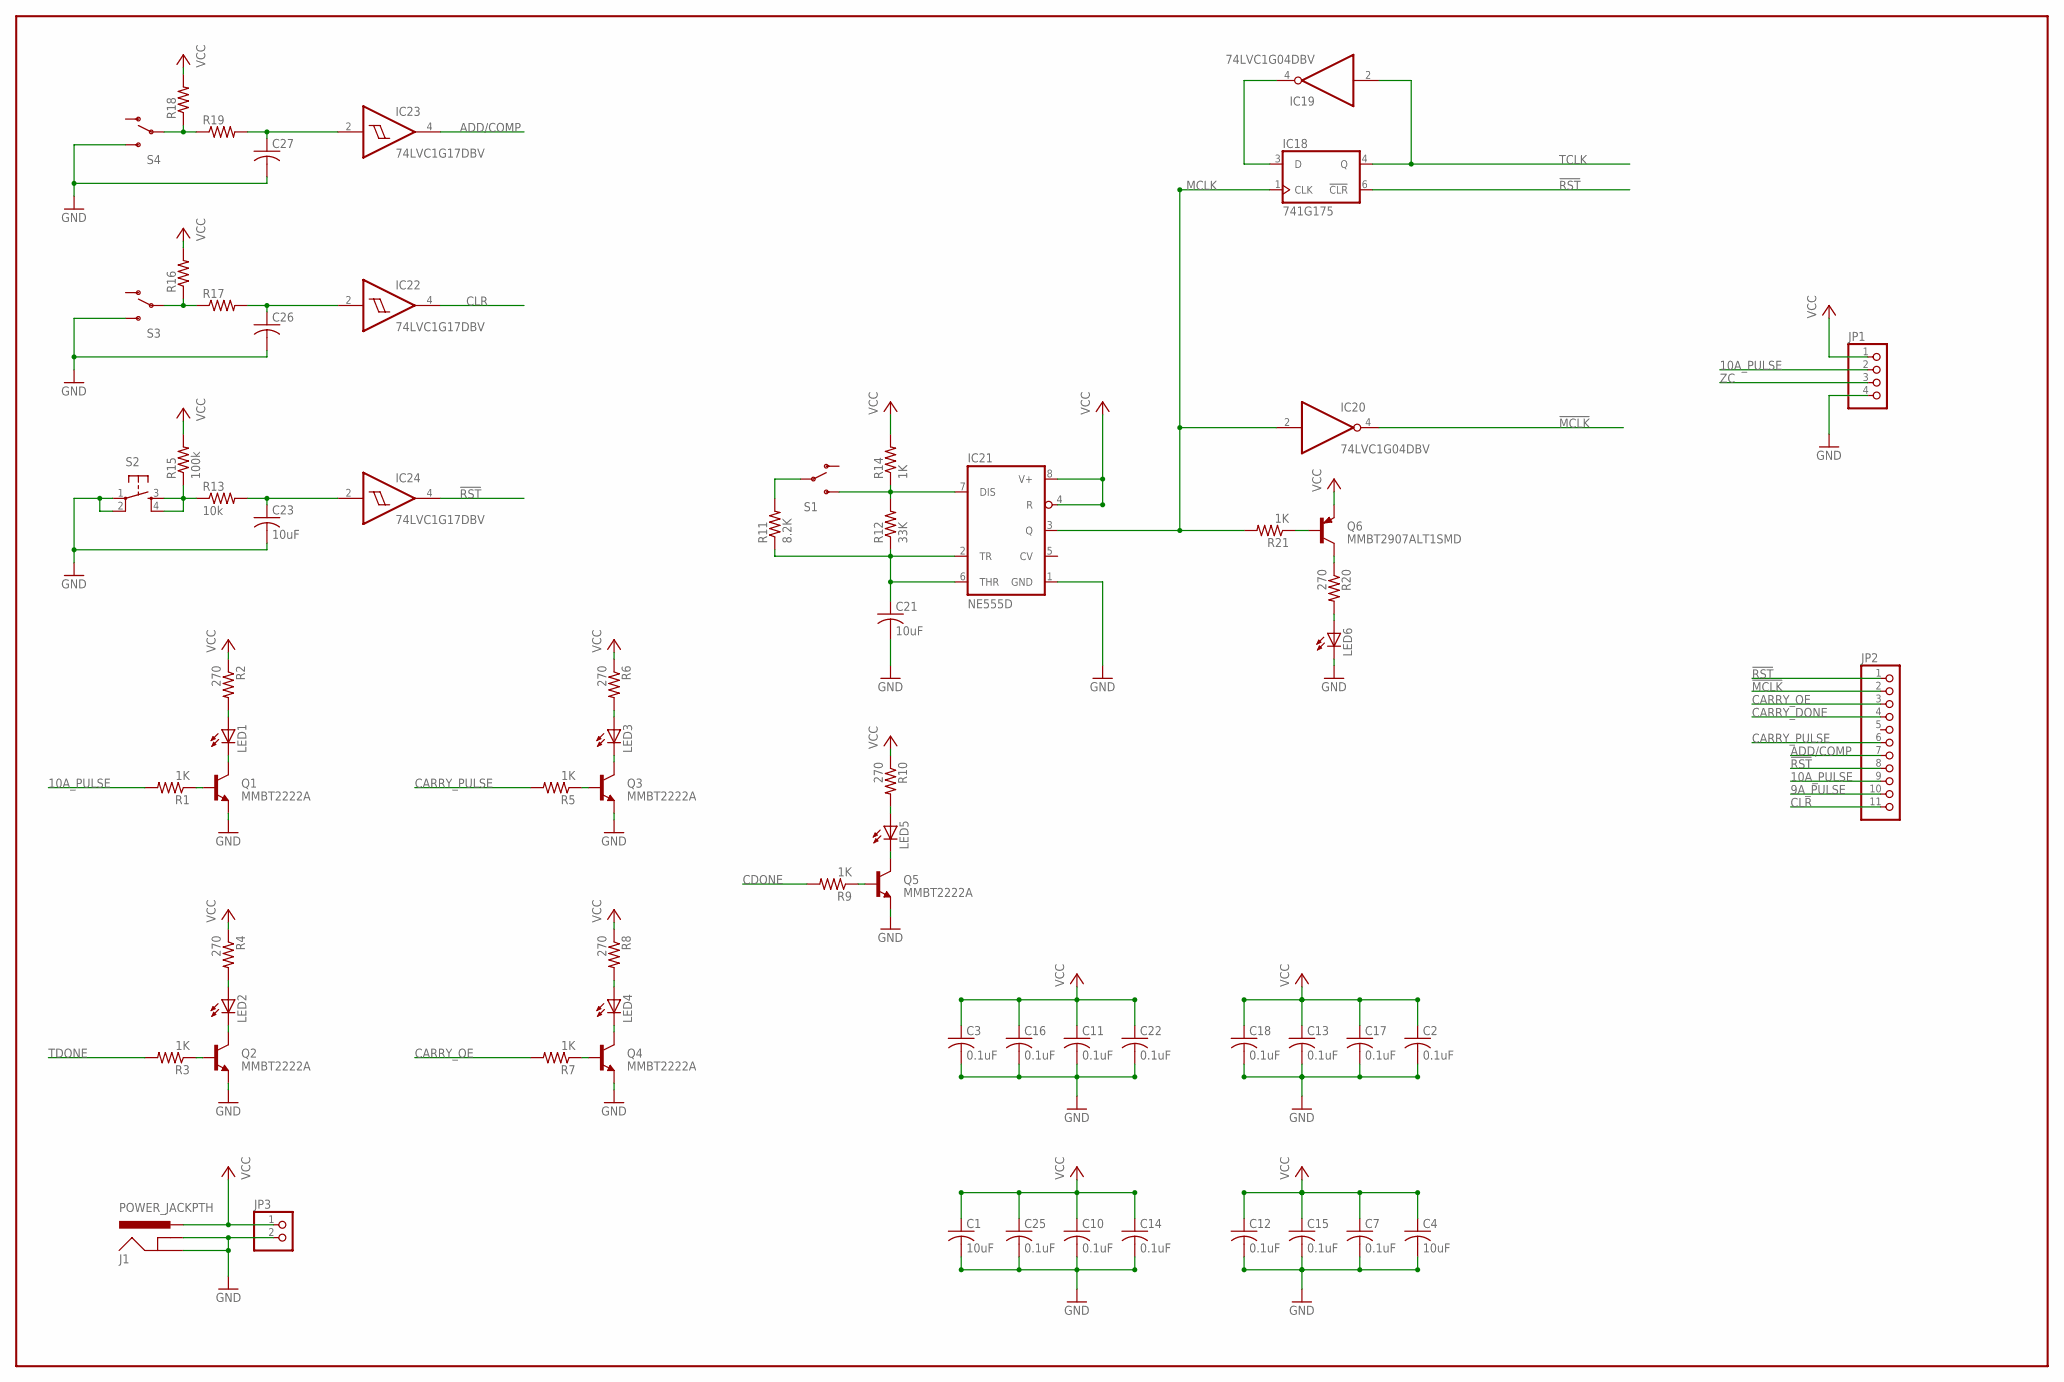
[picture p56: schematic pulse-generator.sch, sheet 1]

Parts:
C1, C4, C21, C23: 10uF; C0805
C2, C3, C7, C10, C11, C12, C13, C14, C15, C16, C17, C18, C22, C25: 0.1uF; C0805
C26, C27: C-USC0805; C0805
IC18: 741G175; DBV_R-PDSO-G6
IC19, IC20: 74LVC1G04DBV; SOT23-5
IC21: NE555D; SO08
IC22, IC23, IC24: 74LVC1G17DBV; SOT23-5
J1: POWER_JACKPTH; POWER_JACK_PTH
JP1: PINHD-1X4; 1X04
JP2: PINHD-1X11; 1X11
JP3: PINHD-1X2; 1X02
LED1, LED2, LED3, LED4, LED5, LED6: LEDCHIP-LED0805; CHIP-LED0805
Q1, Q2, Q3, Q4, Q5: MMBT2222A; SOT23-3
Q6: MMBT2907ALT1SMD; SOT23-BEC
R1, R3, R5, R7, R9, R14, R21: 1K; R0805
R2, R4, R6, R8, R10, R20: 270; R0805
R11: 8.2K; R0805
R12: 33K; R0805
R13: 10k; R0805
R15: 100k; R0805
R16, R17, R18, R19: R-US_R0805; R0805
S1, S3, S4: SWITCH-SPDTPTH; SWITCH-SPDT
S2: TAC_SWITCHPTH; TACTILE-PTH

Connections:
9A_PULSE: JP2.10; also elsewhere on the board
10A_PULSE: JP1.2, JP2.9, R1.2; also elsewhere on the board
!MCLK: IC20.4 (O), JP2.2; also elsewhere on the board
!RST: IC18.6 (!CLR), IC24.4 (O), JP2.1, JP2.8; also elsewhere on the board
ADD/COMP: IC23.4 (O), JP2.7
CARRY_DONE: JP2.4; also elsewhere on the board
CARRY_OE: JP2.3, R7.2; also elsewhere on the board
CARRY_PULSE: JP2.6, R5.2; also elsewhere on the board
CDONE: R9.2; also elsewhere on the board
CLR: IC22.4 (O), JP2.11
GND: C1.2, C2.2, C3.2, C4.2, C7.2, C10.2, C11.2, C12.2, C13.2, C14.2, C15.2, C16.2, C17.2, C18.2, C21.2, C22.2, C23.2, C25.2, C26.2, C27.2, IC18.2 (GND), IC19.3 (GND), IC20.3 (GND), IC21.1 (GND), IC22.3 (GND), IC23.3 (GND), IC24.3 (GND), J1.GND, J1.GNDBREAK, JP1.4, JP3.2, LED6.C, Q1.2 (E), Q2.2 (E), Q3.2 (E), Q4.2 (E), Q5.2 (E), S2.1, S2.2, S3.3 (S), S4.3 (S); also elsewhere on the board
MCLK: IC18.1 (CLK), IC20.2 (I), IC21.3 (Q), R21.2
unnamed: IC18.3 (D), IC19.4 (O)
unnamed: C21.1, IC21.2 (TR), IC21.6 (THR), R11.1, R12.1
unnamed: IC21.7 (DIS), R12.2, R14.1, S1.3 (S)
unnamed: R11.2, S1.2
unnamed: Q6.B, R21.1
unnamed: Q6.C, R20.1
unnamed: LED6.A, R20.2
unnamed: LED3.C, Q3.3 (C)
unnamed: LED1.C, Q1.3 (C)
unnamed: C23.1, IC24.2 (I), R13.2
unnamed: R13.1, R15.1, S2.3, S2.4
unnamed: C26.1, IC22.2 (I), R17.2
unnamed: R16.1, R17.1, S3.2
unnamed: Q3.1 (B), R5.1
unnamed: LED3.A, R6.2
unnamed: Q1.1 (B), R1.1
unnamed: LED1.A, R2.2
unnamed: C27.1, IC23.2 (I), R19.2
unnamed: R18.1, R19.1, S4.2
unnamed: LED2.C, Q2.3 (C)
unnamed: Q2.1 (B), R3.1
unnamed: LED2.A, R4.2
unnamed: LED4.C, Q4.3 (C)
unnamed: Q4.1 (B), R7.1
unnamed: LED4.A, R8.2
unnamed: LED5.C, Q5.3 (C)
unnamed: Q5.1 (B), R9.1
unnamed: LED5.A, R10.2
TCLK: IC18.4 (Q), IC19.2 (I); also elsewhere on the board
TDONE: R3.2; also elsewhere on the board
VCC: C1.1, C2.1, C3.1, C4.1, C7.1, C10.1, C11.1, C12.1, C13.1, C14.1, C15.1, C16.1, C17.1, C18.1, C22.1, C25.1, IC18.5 (VCC), IC19.5 (VCC), IC20.5 (VCC), IC21.4 (R), IC21.8 (V+), IC22.5 (VCC), IC23.5 (VCC), IC24.5 (VCC), J1.PWR, JP1.1, JP3.1, Q6.E, R2.1, R4.1, R6.1, R8.1, R10.1, R14.2, R15.2, R16.2, R18.2; also elsewhere on the board
ZC: JP1.3; also elsewhere on the board

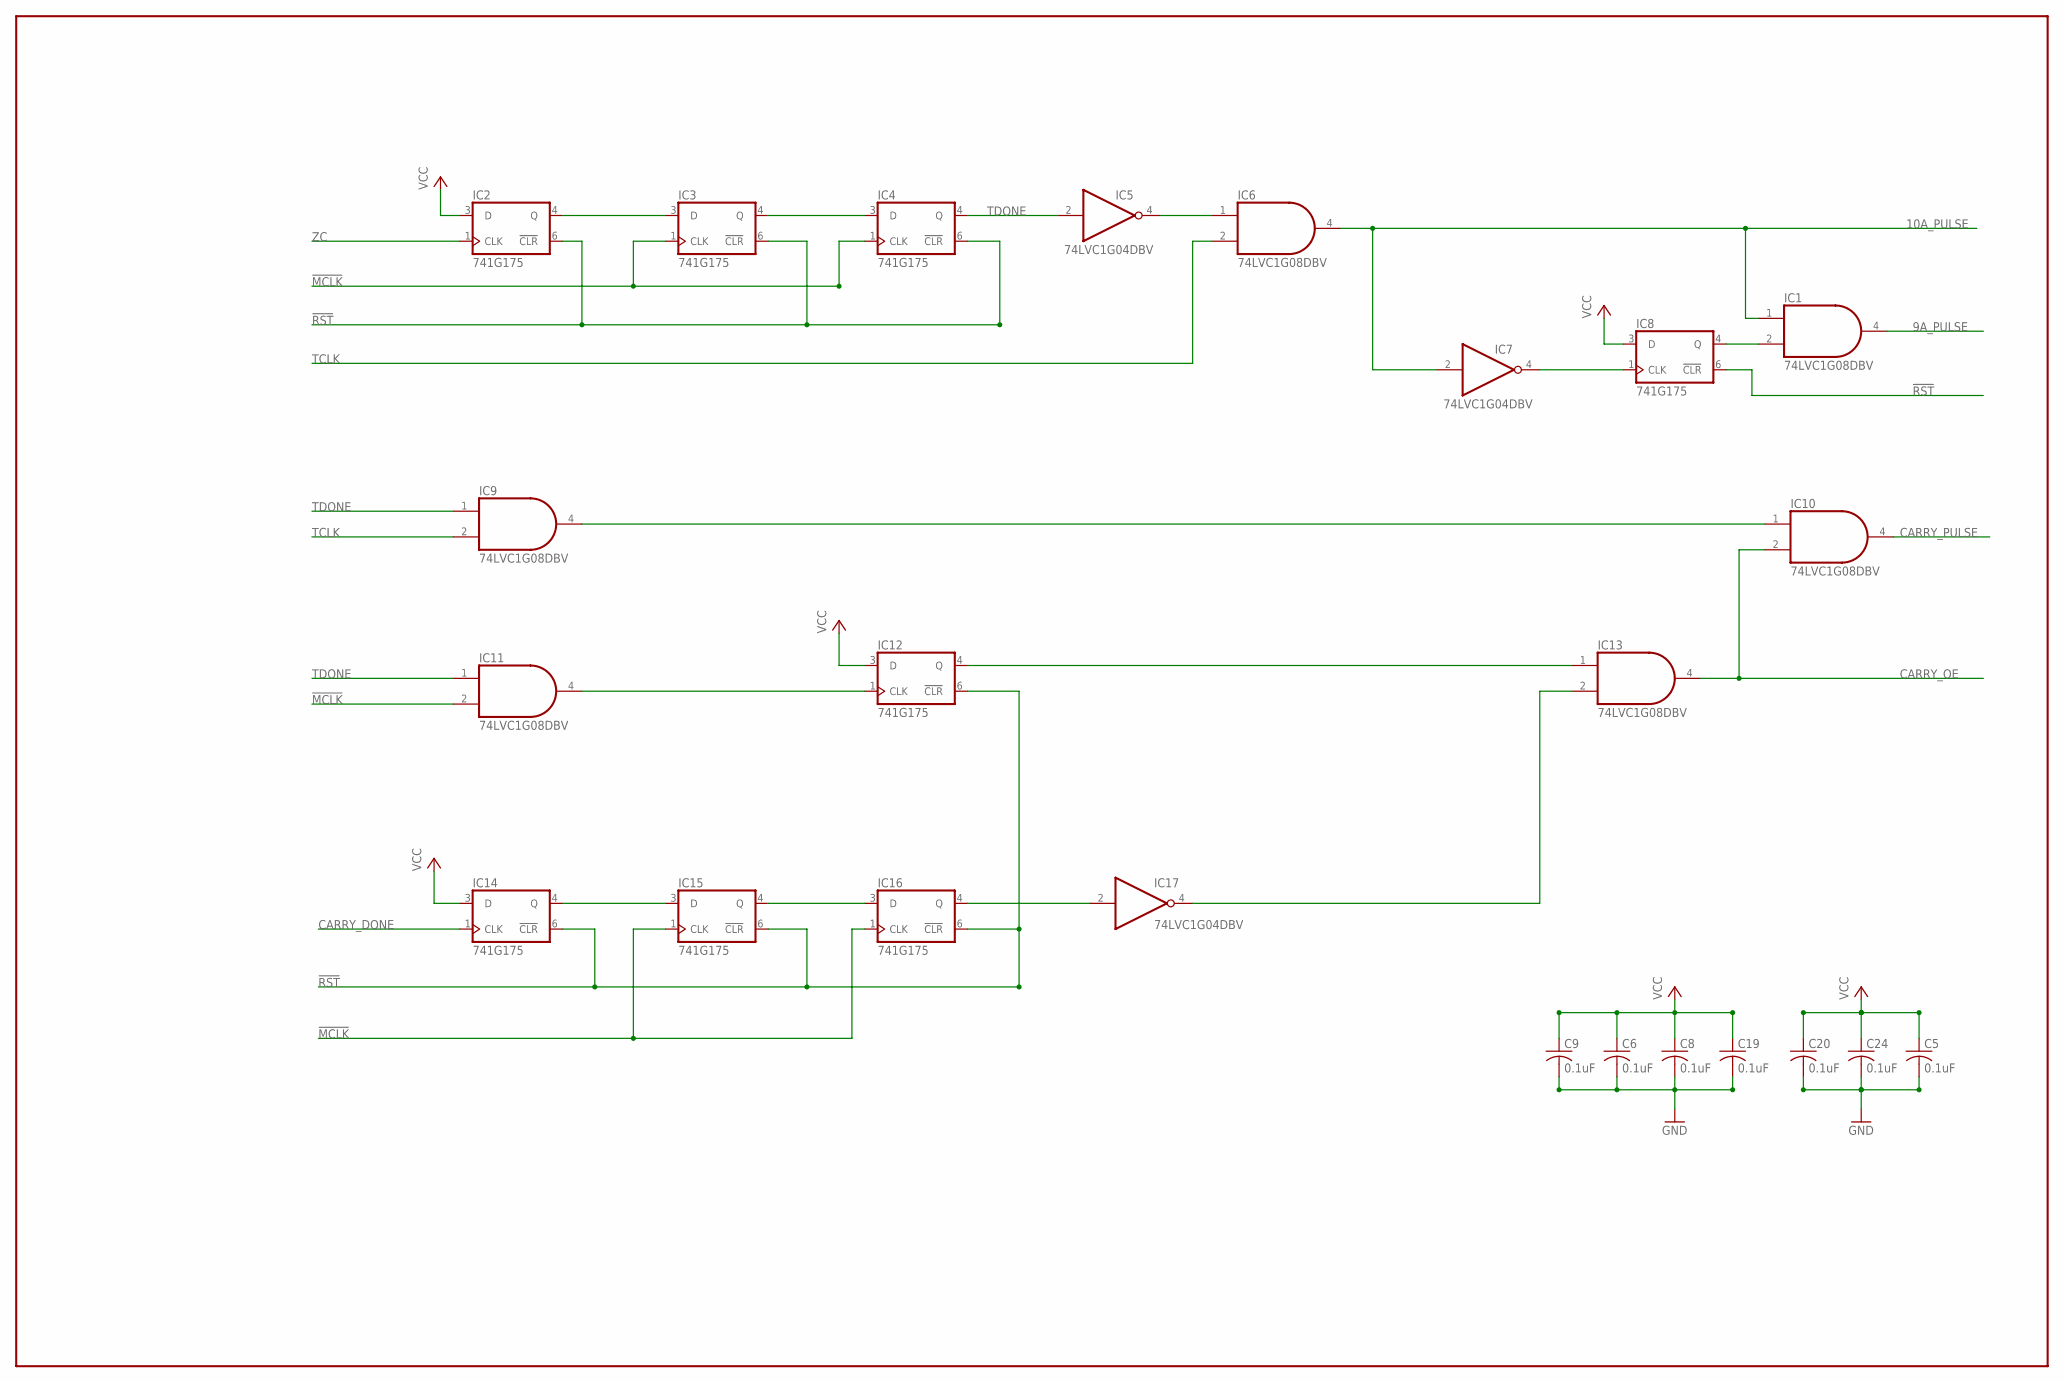
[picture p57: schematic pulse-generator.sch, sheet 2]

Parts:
C5, C6, C8, C9, C19, C20, C24: 0.1uF; C0805
IC1, IC6, IC9, IC10, IC11, IC13: 74LVC1G08DBV; SOT23-5
IC2, IC3, IC4, IC8, IC12, IC14, IC15, IC16: 741G175; DBV_R-PDSO-G6
IC5, IC7, IC17: 74LVC1G04DBV; SOT23-5

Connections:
9A_PULSE: IC1.4 (O); also elsewhere on the board
10A_PULSE: IC1.1 (I0), IC6.4 (O), IC7.2 (I); also elsewhere on the board
!CDONE: IC13.2 (I1), IC17.4 (O)
!MCLK: IC3.1 (CLK), IC4.1 (CLK), IC11.2 (I1), IC15.1 (CLK), IC16.1 (CLK); also elsewhere on the board
!RST: IC2.6 (!CLR), IC3.6 (!CLR), IC4.6 (!CLR), IC8.6 (!CLR), IC12.6 (!CLR), IC14.6 (!CLR), IC15.6 (!CLR), IC16.6 (!CLR); also elsewhere on the board
!TDONE: IC5.4 (O), IC6.1 (I0)
CARRY_DONE: IC14.1 (CLK); also elsewhere on the board
CARRY_OE: IC10.2 (I1), IC13.4 (O); also elsewhere on the board
CARRY_PULSE: IC10.4 (O); also elsewhere on the board
CDONE: IC16.4 (Q), IC17.2 (I); also elsewhere on the board
GND: C5.2, C6.2, C8.2, C9.2, C19.2, C20.2, C24.2, IC1.3 (GND), IC2.2 (GND), IC3.2 (GND), IC4.2 (GND), IC5.3 (GND), IC6.3 (GND), IC7.3 (GND), IC8.2 (GND), IC9.3 (GND), IC10.3 (GND), IC11.3 (GND), IC12.2 (GND), IC13.3 (GND), IC14.2 (GND), IC15.2 (GND), IC16.2 (GND), IC17.3 (GND); also elsewhere on the board
unnamed: IC2.4 (Q), IC3.3 (D)
unnamed: IC9.4 (O), IC10.1 (I0)
unnamed: IC14.4 (Q), IC15.3 (D)
unnamed: IC1.2 (I1), IC8.4 (Q)
unnamed: IC3.4 (Q), IC4.3 (D)
unnamed: IC12.4 (Q), IC13.1 (I0)
unnamed: IC11.4 (O), IC12.1 (CLK)
unnamed: IC15.4 (Q), IC16.3 (D)
unnamed: IC7.4 (O), IC8.1 (CLK)
TCLK: IC6.2 (I1), IC9.2 (I1); also elsewhere on the board
TDONE: IC4.4 (Q), IC5.2 (I), IC9.1 (I0), IC11.1 (I0); also elsewhere on the board
VCC: C5.1, C6.1, C8.1, C9.1, C19.1, C20.1, C24.1, IC1.5 (VCC), IC2.3 (D), IC2.5 (VCC), IC3.5 (VCC), IC4.5 (VCC), IC5.5 (VCC), IC6.5 (VCC), IC7.5 (VCC), IC8.3 (D), IC8.5 (VCC), IC9.5 (VCC), IC10.5 (VCC), IC11.5 (VCC), IC12.3 (D), IC12.5 (VCC), IC13.5 (VCC), IC14.3 (D), IC14.5 (VCC), IC15.5 (VCC), IC16.5 (VCC), IC17.5 (VCC); also elsewhere on the board
ZC: IC2.1 (CLK); also elsewhere on the board


Board: 2 copper layers, 159.8 x 99.1 mm, 92 parts (0 on the bottom side), 55 nets.

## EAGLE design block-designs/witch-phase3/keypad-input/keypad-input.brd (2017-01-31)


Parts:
JP1: PINHD-1X18; 1X18
R1, R2, R3, R4, R5, R6, R7, R8, R9, R10, R11, R12, R13, R14, R15, R16: 100k; R0805
SW0, SW1, SW2, SW3, SW4, SW5, SW6, SW7, SW8, SW9: SWITCH-MOMENTARY-212MM; TACTILE-PTH-12MM
SW-EXEC: SWITCH-MOMENTARY-212MM; TACTILE-PTH-12MM
SW-MINUS: SWITCH-MOMENTARY-212MM; TACTILE-PTH-12MM
SW-ORDER: SWITCH-MOMENTARY-212MM; TACTILE-PTH-12MM
SW-PLUS: SWITCH-MOMENTARY-212MM; TACTILE-PTH-12MM
SW-RESET: SWITCH-MOMENTARY-212MM; TACTILE-PTH-12MM
SW-SPACE: SWITCH-MOMENTARY-212MM; TACTILE-PTH-12MM

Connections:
GND: JP1.18, R1.2, R2.2, R3.2, R4.2, R5.2, R6.2, R7.2, R8.2, R9.2, R10.2, R11.2, R12.2, R13.2, R14.2, R15.2, R16.2
SW0: JP1.6, R10.1, SW0.3 (2)
SW1: JP1.5, R1.1, SW1.3 (2)
SW2: JP1.9, R2.1, SW2.3 (2)
SW3: JP1.13, R3.1, SW3.3 (2)
SW4: JP1.4, R4.1, SW4.3 (2)
SW5: JP1.8, R5.1, SW5.3 (2)
SW6: JP1.12, R6.1, SW6.3 (2)
SW7: JP1.3, R7.1, SW7.3 (2)
SW8: JP1.7, R8.1, SW8.3 (2)
SW9: JP1.11, R9.1, SW9.3 (2)
SW-EXEC: JP1.15, R12.1, SW-EXEC.3 (2)
SW-MINUS: JP1.10, R15.1, SW-MINUS.3 (2)
SW-ORDER: JP1.17, R11.1, SW-ORDER.3 (2)
SW-PLUS: JP1.2, R14.1, SW-PLUS.3 (2)
SW-RESET: JP1.14, R16.1, SW-RESET.3 (2)
SW-SPACE: JP1.16, R13.1, SW-SPACE.3 (2)
VCC: JP1.1, SW0.1, SW1.1, SW2.1, SW3.1, SW4.1, SW5.1, SW6.1, SW7.1, SW8.1, SW9.1, SW-EXEC.1, SW-MINUS.1, SW-ORDER.1, SW-PLUS.1, SW-RESET.1, SW-SPACE.1


Board: 2 copper layers, 86.4 x 76.2 mm, 33 parts (0 on the bottom side), 18 nets.

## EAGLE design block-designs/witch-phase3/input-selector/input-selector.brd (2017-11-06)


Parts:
C1, C2, C3, C4, C5, C6, C7, C8: C-USC0603; C0603
IC1, IC2, IC3, IC4, IC5, IC6, IC7, IC8: 74LVC1G17DBV; SOT23-5

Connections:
GND: C1.2, C2.2, C3.2, C4.2, C5.2, C6.2, C7.2, C8.2, IC1.3 (GND), IC2.3 (GND), IC3.3 (GND), IC4.3 (GND), IC5.3 (GND), IC6.3 (GND), IC7.3 (GND), IC8.3 (GND); also elsewhere on the board
RCV_ROW0: IC5.4 (O); also elsewhere on the board
RCV_ROW1: IC6.4 (O); also elsewhere on the board
RCV_ROW2: IC7.4 (O); also elsewhere on the board
RCV_ROW3: IC8.4 (O); also elsewhere on the board
R_R0: IC5.2 (I); also elsewhere on the board
R_R1: IC6.2 (I); also elsewhere on the board
R_R2: IC7.2 (I); also elsewhere on the board
R_R3: IC8.2 (I); also elsewhere on the board
SND_ROW0: IC1.4 (O); also elsewhere on the board
SND_ROW1: IC2.4 (O); also elsewhere on the board
SND_ROW2: IC3.4 (O); also elsewhere on the board
SND_ROW3: IC4.4 (O); also elsewhere on the board
S_R0: IC1.2 (I); also elsewhere on the board
S_R1: IC2.2 (I); also elsewhere on the board
S_R2: IC3.2 (I); also elsewhere on the board
S_R3: IC4.2 (I); also elsewhere on the board
VCC: C1.1, C2.1, C3.1, C4.1, C5.1, C6.1, C7.1, C8.1, IC1.5 (VCC), IC2.5 (VCC), IC3.5 (VCC), IC4.5 (VCC), IC5.5 (VCC), IC6.5 (VCC), IC7.5 (VCC), IC8.5 (VCC); also elsewhere on the board


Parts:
C9, C10, C11, C12, C13, C14, C17, C18, C19, C20: C-USC0603; C0603
C15, C16: C-USC0805; C0805
IC9, IC10, IC11, IC12, IC13, IC14: 74LVC1G17DBV; SOT23-5
JP1, JP2, JP3, JP4: PINHD-1X6; 1X06
JP5, JP7: PINHD-1X4; 1X04
JP6: PINHD-1X12; 1X12
R1, R2: R-US_R0805; R0805

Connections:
GND: C9.2, C10.2, C11.2, C12.2, C13.2, C14.2, C15.2, C16.2, C17.2, C18.2, C19.2, C20.2, IC9.3 (GND), IC10.3 (GND), IC11.3 (GND), IC12.3 (GND), IC13.3 (GND), IC14.3 (GND), JP1.1, JP2.1, JP3.1, JP4.1, JP5.4, JP7.4, R1.1, R2.1; also elsewhere on the board
RCV_ENABLE: JP7.3, R2.2
RCV_ROW0: JP6.5; also elsewhere on the board
RCV_ROW1: JP6.7; also elsewhere on the board
RCV_ROW2: JP6.9; also elsewhere on the board
RCV_ROW3: JP6.11; also elsewhere on the board
RCV_SEL0: IC9.4 (O), JP5.3
RCV_SEL1: IC12.4 (O), JP6.3
RCV_SEL2: IC14.4 (O), JP6.4
R_R0: JP4.2; also elsewhere on the board
R_R1: JP4.3; also elsewhere on the board
R_R2: JP4.4; also elsewhere on the board
R_R3: JP4.5; also elsewhere on the board
R_R4: JP4.6
R_S0: IC9.2 (I), JP3.2
R_S1: IC12.2 (I), JP3.3
R_S2: IC14.2 (I), JP3.4
R_S3: JP3.5
R_S4: JP3.6
SND_ENABLE: JP7.2, R1.2
SND_ROW0: JP6.6; also elsewhere on the board
SND_ROW1: JP6.8; also elsewhere on the board
SND_ROW2: JP6.10; also elsewhere on the board
SND_ROW3: JP6.12; also elsewhere on the board
SND_SEL0: IC10.4 (O), JP5.2
SND_SEL1: IC11.4 (O), JP6.1
SND_SEL2: IC13.4 (O), JP6.2
S_R0: JP2.2; also elsewhere on the board
S_R1: JP2.3; also elsewhere on the board
S_R2: JP2.4; also elsewhere on the board
S_R3: JP2.5; also elsewhere on the board
S_R4: JP2.6
S_S0: IC10.2 (I), JP1.2
S_S1: IC11.2 (I), JP1.3
S_S2: IC13.2 (I), JP1.4
S_S3: JP1.5
S_S4: JP1.6
VCC: C9.1, C10.1, C11.1, C12.1, C13.1, C14.1, C15.1, C16.1, C17.1, C18.1, C19.1, C20.1, IC9.5 (VCC), IC10.5 (VCC), IC11.5 (VCC), IC12.5 (VCC), IC13.5 (VCC), IC14.5 (VCC), JP5.1, JP7.1; also elsewhere on the board


Board: 2 copper layers, 99.1 x 66.7 mm, 43 parts (0 on the bottom side), 32 nets.

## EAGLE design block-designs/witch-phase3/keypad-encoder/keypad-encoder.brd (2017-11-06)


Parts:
C1, C2, C3, C4, C5, C6, C7, C8, C9, C10, C11, C12, C13, C14, C15, C16, C17, C18, C19, C20, C21, C22, C23: 0.1uF; C0805
C24: 1uF; C0805
C25, C26: 10uF; C0805
D1, D2, D3, D4, D5, D6, D7, D8, D9, D10, D11, D12, D13, D14, D15, D16, D17, D18, D19, D20, D21, D22, D23, D24, D25, D26, D27, D28, D29, D30, D31, D32: DIODEPTH; DIODE-1N4001
IC1, IC2, IC3, IC4, IC5, IC6: 74LVC1G17DBV; SOT23-5
IC7, IC8: 74LVC1G14DBV; SOT23-5
JP1: PINHD-1X18; 1X18
JP2: PINHD-1X8; 1X08
JP3: PINHD-1X5; 1X05
R1, R2, R3, R4, R5, R6, R7, R8, R9, R10, R11, R12, R13, R14, R15, R16, R17, R18, R19, R20, R21: 1k; R0805
R22: 100K; R0805

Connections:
!KEY: IC8.4 (O), JP3.4
!RESET: IC7.4 (O), JP2.7, JP3.2
EXEC: IC6.4 (O), JP3.3
GND: C1.2, C2.2, C3.2, C4.2, C5.2, C6.2, C7.2, C8.2, C9.2, C10.2, C11.2, C12.2, C13.2, C14.2, C15.2, C16.2, C17.2, C18.2, C19.2, C20.2, C21.2, C22.2, C23.2, C24.2, C25.2, C26.2, IC1.3 (GND), IC2.3 (GND), IC3.3 (GND), IC4.3 (GND), IC5.3 (GND), IC6.3 (GND), IC7.3 (GND), IC8.3 (GND), JP1.18, JP2.8, JP3.5, R17.1, R18.1, R19.1, R20.1, R21.1, R22.1
KEY: D28.C, D29.C, D30.C, D31.C, D32.C, IC8.2 (I), R22.2
unnamed: C11.1, D21.A, D22.A, D23.A, D24.A, R11.2
unnamed: C1.1, D1.A, D2.A, R1.2
unnamed: C2.1, D3.A, D4.A, R2.2
unnamed: C3.1, D5.A, D6.A, R3.2
unnamed: C4.1, D7.A, D8.A, R4.2
unnamed: C5.1, D9.A, D10.A, R5.2
unnamed: C6.1, D11.A, D12.A, R6.2
unnamed: C7.1, D13.A, D14.A, R7.2
unnamed: C8.1, D15.A, D16.A, R8.2
unnamed: C9.1, D17.A, D18.A, R9.2
unnamed: C10.1, D19.A, D20.A, R10.2
unnamed: C12.1, D25.A, R12.2
unnamed: C13.1, D26.A, R13.2
unnamed: C14.1, D27.A, R14.2
unnamed: C15.1, IC6.2 (I), R15.2
unnamed: C16.1, IC7.2 (I), R16.2
OUT_A: D1.C, D13.C, D15.C, D19.C, D21.C, D27.C, D30.A, IC1.2 (I), R17.2
OUT_B: D3.C, D5.C, D17.C, D20.C, D28.A, IC2.2 (I), R18.2
OUT_C: D2.C, D4.C, D7.C, D9.C, D22.C, D25.C, D29.A, IC3.2 (I), R19.2
OUT_D: D6.C, D8.C, D11.C, D14.C, D23.C, D31.A, IC4.2 (I), R20.2
OUT_E: D10.C, D12.C, D16.C, D18.C, D24.C, D26.C, D32.A, IC5.2 (I), R21.2
SIGA: IC1.4 (O), JP2.2
SIGB: IC2.4 (O), JP2.3
SIGC: IC3.4 (O), JP2.4
SIGD: IC4.4 (O), JP2.5
SIGE: IC5.4 (O), JP2.6
SW0: JP1.6, R10.1
SW1: JP1.5, R1.1
SW2: JP1.9, R2.1
SW3: JP1.13, R3.1
SW4: JP1.4, R4.1
SW5: JP1.8, R5.1
SW6: JP1.12, R6.1
SW7: JP1.3, R7.1
SW8: JP1.7, R8.1
SW9: JP1.11, R9.1
SW-EXEC: JP1.15, R15.1
SW-MINUS: JP1.10, R13.1
SW-ORDER: JP1.17, R11.1
SW-PLUS: JP1.2, R14.1
SW-RESET: JP1.14, R16.1
SW-SPACE: JP1.16, R12.1
VCC: C17.1, C18.1, C19.1, C20.1, C21.1, C22.1, C23.1, C24.1, C25.1, C26.1, IC1.5 (VCC), IC2.5 (VCC), IC3.5 (VCC), IC4.5 (VCC), IC5.5 (VCC), IC6.5 (VCC), IC7.5 (VCC), IC8.5 (VCC), JP1.1, JP2.1, JP3.1


Board: 2 copper layers, 159.8 x 63.5 mm, 91 parts (0 on the bottom side), 48 nets.

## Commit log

2014-02-07 initial commit of simulated dekatron block design
    [witch-dekatron1.brd, witch-dekatron1.sch]
2014-02-07 add initial design of transfer block
    [witch-transfer1.brd, witch-transfer1.sch]
2014-02-13 updated transfer block with board layout
    [witch-transfer1.brd, witch-transfer1.sch]
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2014-05-22 updated schematics and layouts for phase 1 block designs
    [witch-dekatron1.brd, witch-pulse.brd, witch-pulse.sch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]
2014-05-22 updated files with new images
    [witch-pulse1.brd, witch-pulse1.sch, witch-transfer1.brd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]
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2014-05-23 add gerbers for X1 designs
    [witch-dekatron1.GBL, witch-dekatron1.GBO, witch-dekatron1.GBS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]
2014-06-25 add new block design for phase2
    [witch-phase2a.brd, witch-phase2a.sch]
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2014-06-30 routed and updated transferboard and add dekatron board
    [witch-phase2a.brd, witch-phase2a.sch, witch-phase2b.brd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]
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2014-07-30 updated figure 4 for the ee article
    [witch-phase2b.brd]
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2014-10-02 updated pdf schematics and board files with fixes
    [witch-pulse1.brd, witch-pulse1.sch, witch-transfer1.brd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]
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2015-08-06 remove old phase2 tests
    [witch-phase2a.brd, witch-phase2a.sch, witch-phase2b.brd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]
2015-08-06 add new phase2 designs
    [dekatron-sim-4017-a2.brd, dekatron-sim-4017-a2.sch, dekatron-sim-4017-a3.brd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]
2015-08-06 move phase1 designs into separate subdirectory
    [witch-dekatron1.brd, witch-dekatron1.sch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]
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2015-08-28 updated revisions with fixes for manufacturing
    [dekatron-sim-4017-a3.brd, keyboard-tester.brd, keyboard-tester.sch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]
2015-09-08 add pull down resistors to design
    [relay-set-d-large-block.brd, relay-set-d-large-block.sch]
2015-09-13 change pullup to pulldown resistors
    [store-column-block.brd, store-column-block.sch]
2015-09-13 add initial schematic and board layout for transfer block
    [transfer-block.brd, transfer-block.sch]
2015-09-13 initial commit of carry block schematic and board layout
    [carry-block.brd, carry-block.sch]
2015-09-14 add OR gate with basic routing
    [carry-block.brd, carry-block.sch]
2015-09-14 added carry next and carry previous signals
    [carry-block.brd, carry-block.sch]
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2015-12-03 initial commit of the dot reader sensor board
    [dot-reader.brd, dot-reader.sch]
2016-01-19 break the carry section into two pcbs and add new flipflop design
    [carry-select.brd, carry-select.sch]
2016-01-20 updated with 74hc195 and carry_oe signal
    [carry-block.brd, carry-block.sch]
2016-01-20 remove AND gate and use the Set/Load function
    [carry-block.brd, carry-block.sch]
2016-02-21 new block designs for relay set D
    [relay-set-d-decode.brd, relay-set-d-decode.sch, relay-set-d-latch.brd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]
2016-02-21 fixes and tweaks for carry block layout
    [carry-block.brd]
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2016-02-21 updated all designs with corrected dimensions and design label
    [carry-block.brd, carry-select.brd, dekatron-sim-4017-a3.brd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]
2016-02-23 adjust borders for ground/vcc plains and size to match 1.1inch grids
    [carry-block.brd, carry-select.brd, dekatron-sim-4017-a3.brd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]
2016-02-23 updated board layout pictures and pdf schematics
    [carry-block.brd, carry-select.brd, dekatron-sim-4017-a3.brd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]
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2016-03-09 minor tweak to connector location in schematic
    [keyboard-tester.sch]
2016-03-09 minor tweaks to original large block design
    [relay-set-d-large-block.brd, relay-set-d-large-block.sch]
2016-03-09 fixes for the decode - change OR gates to AND gates
    [relay-set-d-decode.brd, relay-set-d-decode.sch]
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2016-07-03 update the interconnect board with spacing and layout changes
    [interconnect-board.brd, interconnect-board.sch]
2016-07-04 updated design for layout for use with dupont connectors
    [interconnect-board.brd, interconnect-board.sch]
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2016-07-04 change name to fit with new naming scheme
    [ministore-interconnect.brd, ministore-interconnect.sch]
2016-08-27 move keyboard tester to new directory for test and debug boards
    [keyboard-tester.brd, keyboard-tester.sch]
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2016-08-27 fixes for layout and connections
    [ministore-interconnect.brd, ministore-interconnect.sch, transfer-interconnect.brd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]
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2016-08-27 switch position tweaks and drc fixes
    [pulse-generator.brd]
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2016-08-28 minor changes to position of reset/run button
    [pulse-generator.brd]
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2016-09-03 fix pin5 on 555, invert 9A latch, connect !RST to TCLK flip-flop
    [pulse-generator.brd, pulse-generator.sch]
2016-09-16 replace or with d-flipflop to fix zc start issue
    [carry-block.brd, carry-block.sch]
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2016-09-21 add additional bypass caps and LEDs for signals
    [pulse-generator.brd, pulse-generator.sch]
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2016-11-18 update layout with additional caps and change to 0603 passives
    [carry-block.brd, carry-block.sch]
2016-11-18 updated layout with additional caps and change to 0603 passives
    [carry-select.brd, carry-select.sch]
2016-11-18 updated layout with additional caps and change to 0603 passive. changed clock input to use a 71LVC1G97 configured as AND gate with one input inverted
    [transfer-block.brd, transfer-block.sch]
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2016-11-19 added caps on the clock lines and switch to 0603 for passives
    [store-column-block.brd, store-column-block.sch]
2016-11-19 switch to using a schmitt trigger with OR gate for clock output
    [manual-button.brd, manual-button.sch]
2016-11-26 fix label for IC2
    [manual-button.brd]
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2017-01-30 updated acrylic layout for smaller 10wide and 15 tall plates
    [mini-store.dxf, new-set-a.dxf]
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2017-01-31 reduce size of module and add mounting holes
    [keypad-input.brd, keypad-input.sch]
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2017-02-12 change designs to use non-inverting schmitt triggers
    [schmitt-trigger.brd, schmitt-trigger.sch]
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2017-02-14 add additional logic for zero position bugs
    [transfer-block.brd, transfer-block.sch]
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2017-02-14 add schmitt trigger on the carry output line
    [transfer-interconnect.brd, transfer-interconnect.sch]
2017-02-14 add inverting schmitt trigger to valid data detect output
    [relay-set-d-latch.brd, relay-set-d-latch.sch]
2017-02-21 add inverting schemitt trigger for enable line and connect valdata led
    [relay-set-d-latch.brd, relay-set-d-latch.sch]
2017-02-21 add version of decoder with 0 and 1-9 for future use
    [relay-set-d-decode.brd, relay-set-d-decode.sch]
2017-02-21 remove 0 and 1-9 special decodes for basic testing
    [relay-set-d-decode.brd, relay-set-d-decode.sch]
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2017-09-22 updated layout and added inverter for reset signals
    [input-sequence.brd, input-sequence.sch]
2017-09-22 updated layout for easy interface to the rest of the system
    [relay-set-d-decode.brd, relay-set-d-decode.sch]
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2017-10-12 rework of cabling for reset, exec, power, and key-up detection
    [input-sequence.brd, input-sequence.sch, keypad-encoder.brd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]
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2017-10-30 rework design: reduced logic to minimum, added 555 timer for debouncing moved encoder connector to top edge of board for easy routing of cabling, changed the pulse-generator connector back to 4-pin f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
    [input-sequence.brd, input-sequence.sch]
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2017-11-06 schematic cleanup and change bypass caps from 0805 to 0603
    [input-selector.brd, input-selector.sch]
2017-11-06 add new connectors for input system and bug fixes from earlier prototype
    [pulse-generator.brd, pulse-generator.sch]
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2017-11-13 reorganize boards into correct phase of development
    [dot-reader.brd, dot-reader.sch, input-selector.brd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]
2017-11-13 mv work done on phase3 pulse generator to phase3 directory
    [pulse-generator.brd, pulse-generator.sch]
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2017-11-22 update schematic and layout for off-by-one error on add/comp clr singals
    [pulse-generator.brd, pulse-generator.sch]
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2017-11-25 first cut of a functional dot-reader pcb after changes to 80mm paper
    [dot-reader.brd, dot-reader.sch]
2017-11-25 switch to non-inverting schmitts and layout cleanup
    [dot-reader.brd, dot-reader.sch]
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2017-11-26 move 58mm tape reader design to own subdir
    [tape-reader-bot.dxf, tape-reader-guide.dxf, tape-reader-mid.dxf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]
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2018-03-26 fix QRE1113 pcb footprint and reverse direction of signal labels
    [dot-reader.brd, dot-reader.sch]
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

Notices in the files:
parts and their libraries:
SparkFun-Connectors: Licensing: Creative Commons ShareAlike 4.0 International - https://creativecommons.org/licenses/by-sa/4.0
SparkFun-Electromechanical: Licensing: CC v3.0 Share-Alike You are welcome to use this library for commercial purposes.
